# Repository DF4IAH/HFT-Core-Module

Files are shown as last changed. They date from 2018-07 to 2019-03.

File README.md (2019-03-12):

# HFT-Core-Module

## V1.1 PCB after placement was done:
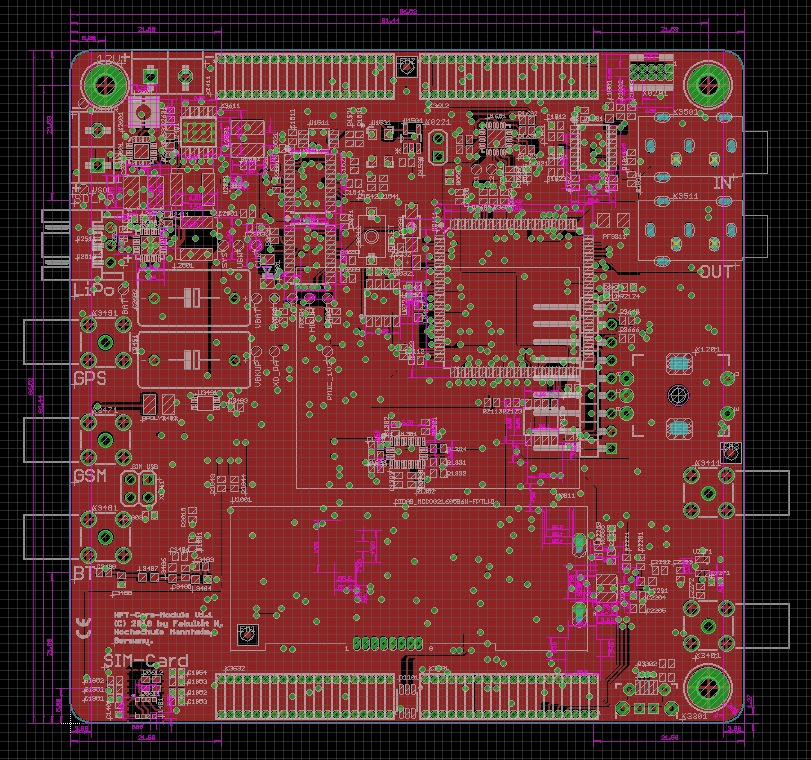
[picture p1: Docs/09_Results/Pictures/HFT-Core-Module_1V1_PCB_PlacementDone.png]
Screenshot of V1.1


## These are the included devices for the V1.1:
* __CPU: ST Microelectronics STM32L496ZGT6P__ (80MHz ARM Cortex-M4 w/ 1MB FLASH / 320kB RAM)
* __ext. Flash and EEPROM__ (8MB more data to be kept outside of the MCU / 8kB configuration data)
* __GSM / GNSS / BT: SIM868__ (SMS / GPRS / GPS, Glonass ...)
* __VHF/UHF FSK and LoRa: SX1262__ (VHF TX/RX)
* __VHF/UHF All but Lora: AX5243__ (VHF TX/RX)
* __Accel/Gyro/Mag: BNO085__ (3Axis-Acceleration, 3Axis-Gyro, 3Axis-Magneto - motion tracking engine)
* __Baro/Hygro/Temp/AirQuality: BME680__ (0.12Pa equiv. 1.7cm)
* __VCTCXO: CFPT-141_20MHz__ (being synchronized to the GPS 1PPS signal by pulling the VC)
* __Clock PLL__ (distributing any clocks that are needed)
* __Audio ADC and DAC__ (connected to the I2S facilities)
* __LCD 16x2 display__ (draws less than 1mA from the battery)
* __E-Ink-Display w/ 200x200px__ (more fun with even less energy)
* __Archer Headers__ (expanded by up to two daughter boards)
* __SMA sockets: GSM, GNSS, BlueTooth, SX1262, AX5243__ (each device has its own antenna socket)
* __PMICs for 12V, USB, Solar-Cells, 3.3V, 1.2V__ (high efficiency on board)
* __Electronic Switches: Subcircuits to be powered on/off by request__ (ultra-low-power to full-media)
* __LiPo-Connector: 1-cell 3.7V__ (high power request by the SIM868 device to be satisfied)
* __... and some more fun...__ (what is missing?  ;-)

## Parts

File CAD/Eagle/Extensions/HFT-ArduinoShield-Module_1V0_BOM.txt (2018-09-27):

Stückliste exportiert aus /Users/espero/nfs_ds_nfs/git/HFT-Core-Module__HW_1V1/CAD/Eagle/Extensions/HFT-ArduinoShield-Module_1V0.sch am 27.09.18 20:26

Qty Value                                   Device                                  Package                                 Parts                  Description                                
1                                           2X08_2MM56_SOCKET                       2X08                                    X108                   Header 2X08 2.54mm                         
1                                           2X10_2MM56_SOCKET                       2X10                                    X107                   Header 2X10 2.54mm                         
1                                           2X15_2MM56_SOCKET                       2X15                                    X105                   Header 2X15 2.54mm                         
2                                           2X17_2MM56_SOCKET                       2X17                                    X110, X190             Header 2X17 2.54mm                         
1                                           2X20_2MM56_SOCKET                       2X20                                    X201                   Header 2X20 2.54mm                         
2   100nF                                   C-EUC0603                               C0603                                   C108, C118             CAPACITOR, European symbol                 
1   120R                                    R-EU_R0603                              R0603                                   R201                   RESISTOR, European symbol                  
2   2X20/90_1MM27_HARWIN_M50-3902042_HEADER 2X20/90_1MM27_HARWIN_M50-3902042_HEADER 2X20/90_1MM27_HARWIN_M50-3902042_HEADER X301, X302             Header 20X2 1.27mm M50-3902042 Archer, 90° 
2   47R                                     R-EU_R0603                              R0603                                   R107, R110             RESISTOR, European symbol                  
4   MOUNT-PAD-ROUND2.8                      MOUNT-PAD-ROUND2.8                      2,8-PAD                                 H401, H402, H403, H404 MOUNTING PAD, round

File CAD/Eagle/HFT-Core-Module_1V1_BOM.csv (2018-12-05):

Qty | Value | Device | Package | Parts | Description
1 |  | HEADER-1X2 | 1X02 | X0222 | Header 1X2 2.54mm
1 |  | HEADER-2X2 | 2X02 | X1961 | Header 2X2 2.54mm
1 |  | HEADER-2X5_1MM27CORTEX_10PIN_JTAG-SWD | 2X05_SHROUDED_1MM27 | X0201 | Header 2X5 1.27mm 0.05";"; 6" | SJ | SJ | SJ0121, SJ0401, SJ0421, SJ0422, SJ0423, SJ0424 | SMD solder JUMPER
1 | 0.47uF | C-EUC0402 | C0402 | C2411 | CAPACITOR, European symbol
1 | 0.5pF | C-EUC0402 | C0402 | C3383 | CAPACITOR, European symbol
1 | 0R | L-EUL0603 | L0603 | L2261 | INDUCTOR, European symbol
12 | 0R | R-EU_R0402 | R0402 | R0441, R0891, R0892, R1811, R1812, R2521, R2651, R2681, R3512, R3513, R3577, R3578 | RESISTOR, European symbol
3 | 0R | R-EU_R0603 | R0603 | R3371, R3381, R3391 | RESISTOR, European symbol
8 | 0pF | C-EUC0402 | C0402 | C2265, C2293, C3371, C3372, C3381, C3382, C3391, C3392 | CAPACITOR, European symbol
2 | 1.0kR | R-EU_R0402 | R0402 | R0611, R0612 | RESISTOR, European symbol
1 | 1.1A/2.2A | R-EU_M1206 | M1206 | PF3211 | RESISTOR, European symbol
1 | 1.2nH | L-EUL0603 | L0603 | L3384 | INDUCTOR, European symbol
2 | 1.2pF | C-EUC0402 | C0402 | C3385, C3389 | CAPACITOR, European symbol
4 | 1.5kR | R-EU_R0402 | R0402 | R1051, R1111, R1121, R1131 | RESISTOR, European symbol
1 | 1.5pF | C-EUC0402 | C0402 | C3388 | CAPACITOR, European symbol
2 | 1.82MR | R-EU_R0402 | R0402 | R2621, R2633 | RESISTOR, European symbol
2 | 1.8pF | C-EUC0402 | C0402 | C2291, C3386 | CAPACITOR, European symbol
1 | 10.0MR | R-EU_R0402 | R0402 | R2622 | RESISTOR, European symbol
4 | 100R | R-EU_R0402 | R0402 | R1712, R1722, R2801, R2802 | RESISTOR, European symbol
8 | 100kR | R-EU_R0402 | R0402 | R0521, R0621, R1521, R2331, R2332, R2612, R2701, R2711 | RESISTOR, European symbol
62 | 100nF | C-EUC0402 | C0402 | C0213, C0401, C0402, C0403, C0404, C0405, C0406, C0407, C0408, C0409, C0421, C0422, C0441, C0521, C0621, C0901, C1001, C1101, C1301, C1302, C1303, C1401, C1501, C1511, C1512, C1531, C1541, C1543, C1602, C1603, C1605, C1702, C1703, C1705, C1902, C2001, C2101, C2202, C2271, C2301, C2302, C2303, C2412, C2541, C2602, C2702, C2751, C2801, C2802, C2803, C2901, C2902, C2903, C3001, C3002, C3003, C3101, C3102, C3103, C3104, C3105, C3393 | CAPACITOR, European symbol
2 | 100nH | L-EUL0603 | L0603 | L2312, L2313 | INDUCTOR, European symbol
1 | 100pF | C-EUC0402 | C0402 | C1532 | CAPACITOR, European symbol
5 | 10kR | R-EU_R0402 | R0402 | R1531, R1711, R1721, R1901, R1942 | RESISTOR, European symbol
10 | 10nF | C-EUC0402 | C0402 | C0412, C1615, C1616, C1712, C1722, C1903, C2404, C2603, C2605, C2653 | CAPACITOR, European symbol
16 | 10uF | C-EUC0402 | C0402 | C1701, C1704, C1711, C1721, C1904, C2201, C2401, C2402, C2403, C2501, C2504, C2505, C2511, C2601, C2652, C2701 | CAPACITOR, European symbol
2 | 10uH | L-EU4.90X4.90MM | L_4.90MM_X_4.90MM | L2651, L2791 | INDUCTOR, European symbol
3 | 10uH | L-EUL0603 | L0603 | L0411, L1701, L1801 | INDUCTOR, European symbol
1 | 150kR | R-EU_R0402 | R0402 | R2712 | RESISTOR, European symbol
1 | 15nH | L-EUL0603 | L0603 | L2291 | INDUCTOR, European symbol
1 | 15uH | L-EU3.00X3.00MM | L_3.00MM_X_3.00MM | L2201 | INDUCTOR, European symbol
1 | 18pF | C-EUC0402 | C0402 | C0311 | CAPACITOR, European symbol
2 | 1F_6V_SCMR18H105MRBB0 | CPOL-EUC115-080X160_POL | C115-080X160_POL | C0451, C2682 | POLARIZED CAPACITOR, European symbol
4 | 1MR | R-EU_ARRAY-8X | EXBD | R0581, R0591, R0681, R0691 | Resistor-Array 8x
3 | 1MR | R-EU_R0402 | R0402 | R1542, R2803, R2804 | RESISTOR, European symbol
1 | 1kR | R-EU_R0402 | R0402 | R2611 | RESISTOR, European symbol
6 | 1nF | C-EUC0402 | C0402 | C1201, C1202, C1203, C1542, C2272, C3203 | CAPACITOR, European symbol
10 | 1uF | C-EUC0402 | C0402 | C0413, C0442, C1011, C1012, C1522, C1811, C1812, C1961, C2502, C2521 | CAPACITOR, European symbol
4 | 2.0kR | R-EU_R0402 | R0402 | R1052, R1112, R1122, R1132 | RESISTOR, European symbol
1 | 2.27kR | R-EU_R0402 | R0402 | R2511 | RESISTOR, European symbol
1 | 2.2pF | C-EUC0402 | C0402 | C2267 | CAPACITOR, European symbol
2 | 2.2uF | C-EUC0402 | C0402 | C1706, C1803 | CAPACITOR, European symbol
2 | 2.2uH | L-EU6.00X6.00MM | L_6.00MM_X_6.00MM | L2411, L2501 | INDUCTOR, European symbol
1 | 2.4pF | C-EUC0402 | C0402 | C2292 | CAPACITOR, European symbol
1 | 2.5nH | L-EUL0603 | L0603 | L2263 | INDUCTOR, European symbol
2 | 2.7nF | C-EUC0402 | C0402 | C1831, C1841 | CAPACITOR, European symbol
1 | 2.7nH | L-EUL0603 | L0603 | L3387 | INDUCTOR, European symbol
3 | 220kR | R-EU_R0402 | R0402 | R0231, R0232, R1031 | RESISTOR, European symbol
7 | 220nF | C-EUC0402 | C0402 | C0711, C0721, C0801, C1601, C1604, C1951, C1955 | CAPACITOR, European symbol
2 | 22R | R-EU_R0402 | R0402 | R1961, R1962 | RESISTOR, European symbol
4 | 22nH | L-EUL0603 | L0603 | L2311, L2316, L2317, L2321 | INDUCTOR, European symbol
5 | 22pF | C-EUC0402 | C0402 | C1321, C1322, C1952, C1953, C1954 | CAPACITOR, European symbol
4 | 22uF | C-EUC0402 | C0402 | C2421, C2422, C2423, C2703 | CAPACITOR, European symbol
1 | 22uH | L-EUWE-TPCWE_TPC_3MM8 | WE-TPC_3MM8-3MM8_R-1MM3 | L2601 | INDUCTOR, European symbol
1 | 240R | R-EU_R0402 | R0402 | R2501 | RESISTOR, European symbol
1 | 27R | R-EU_R0402 | R0402 | R1053 | RESISTOR, European symbol
3 | 27R | R-EU_R0805 | R0805 | R1113, R1123, R1133 | RESISTOR, European symbol
4 | 2X20/90_1MM27_HARWIN_M50-3202045_SOCKET | 2X20/90_1MM27_HARWIN_M50-3202045_SOCKET | 2X20/90_1MM27_HARWIN_M50-3202045_SOCKET | X3511, X3512, X3531, X3532 | Socket 20X2 1.27mm M50-3202045 Archer, 90°
2 | 2kR | R-EU_R0402 | R0402 | R1331, R1332 | RESISTOR, European symbol
3 | 3.3pF | C-EUC0402 | C0402 | C2263, C2282, C2283 | CAPACITOR, European symbol
1 | 3.3uF | C-EUC0402 | C0402 | C2405 | CAPACITOR, European symbol
1 | 3.65MR | R-EU_R0402 | R0402 | R2631 | RESISTOR, European symbol
1 | 330kR | R-EU_R0402 | R0402 | R3202 | RESISTOR, European symbol
3 | 33kR | R-EU_R0402 | R0402 | R0221, R1543, R2541 | RESISTOR, European symbol
2 | 39pF | C-EUC0402 | C0402 | C2264, C2281 | CAPACITOR, European symbol
1 | 3R | R-EU_R0402 | R0402 | R2411 | RESISTOR, European symbol
2 | 4.3pF | C-EUC0402 | C0402 | C2314, C2315 | CAPACITOR, European symbol
1 | 4.75MR | R-EU_R0402 | R0402 | R2641 | RESISTOR, European symbol
2 | 4.7kR | R-EU_R0402 | R0402 | R1943, R1944 | RESISTOR, European symbol
3 | 4.7nH | L-EUL0603 | L0603 | L2264, L3386, L3388 | INDUCTOR, European symbol
5 | 4.7pF | C-EUC0402 | C0402 | C2317, C2318, C2321, C2322, C2323 | CAPACITOR, European symbol
5 | 4.7uF | C-EUC0402 | C0402 | C0410, C0423, C1801, C1802, C2606 | CAPACITOR, European symbol
2 | 43nH | L-EUL0603 | L0603 | L2314, L2315 | INDUCTOR, European symbol
1 | 470nF | C-EUC0402 | C0402 | C2203 | CAPACITOR, European symbol
110 | 47R | R-EU_R0402 | R0402 | R0531, R0631, R0901, R0902, R0903, R0904, R1301, R1302, R1303, R1304, R1538, R1539, R1541, R1623, R1631, R1632, R1643, R1644, R1651, R1751, R1752, R1753, R1761, R1821, R1822, R1823, R1824, R1951, R1952, R1953, R2010, R2011, R2012, R2013, R2014, R2015, R2016, R2017, R2020, R2021, R2022, R2023, R2024, R2025, R2026, R2027, R2110, R2111, R2112, R2113, R2120, R2121, R2122, R2123, R2211, R2221, R2222, R2223, R2224, R2251, R2252, R2253, R2321, R2341, R2351, R2391, R2554, R2811, R3501, R3502, R3503, R3504, R3505, R3506, R3507, R3508, R3509, R3510, R3511, R3514, R3515, R3516, R3517, R3518, R3519, R3520, R3521, R3522, R3523, R3566, R3567, R3568, R3569, R3570, R3571, R3572, R3573, R3574, R3575, R3576, R3579, R3580, R3581, R3582, R3583, R3584, R3585, R3586, R3587, R3588 | RESISTOR, European symbol
2 | 47nF | C-EUC0402 | C0402 | C2205, C2503 | CAPACITOR, European symbol
1 | 47nH | L-EUL0603 | L0603 | L2262 | INDUCTOR, European symbol
2 | 47pF | C-EUC0402 | C0402 | C1901, C2204 | CAPACITOR, European symbol
1 | 5.6pF | C-EUC0402 | C0402 | C2266 | CAPACITOR, European symbol
1 | 50mA/150mA | R-EU_R1210 | R1210 | RPOLY3393 | RESISTOR, European symbol
2 | 560R | R-EU_R0402 | R0402 | R1831, R1841 | RESISTOR, European symbol
1 | 6.86kR | R-EU_R0402 | R0402 | R2512 | RESISTOR, European symbol
1 | 6.8pF | C-EUC0402 | C0402 | C2791 | CAPACITOR, European symbol
1 | 7.50MR | R-EU_R0402 | R0402 | R2632 | RESISTOR, European symbol
2 | 74LVC4245A | 74LVC4245A | TSSOP24_SOT355-1 | U2001, U2101 | Octal dual supply translating transceiver; 3-state
1 | 8.20MR | R-EU_R0402 | R0402 | R2642 | RESISTOR, European symbol
1 | 8.2pF | C-EUC0402 | C0402 | C0332 | CAPACITOR, European symbol
1 | 9.1nH | L-EUL0603 | L0603 | L2282 | INDUCTOR, European symbol
1 | ABM3B-16.0000MHZ | ABM3B-16.0000MHZ | ABM3B | Q2311 | ABM3B Ceramic SMD Crystal
1 | ABM3B-32.0000MHZ | ABM3B-32.0000MHZ | ABM3B | Q2211 | ABM3B Ceramic SMD Crystal
2 | ABS07-32.768KHZ | ABS07-32.768KHZ | ABS07 | Q0321, Q1321 | ABRACON ABS07
1 | ASMT-YTB7-0AA02_RGB | ASMT-YTB7-0AA02_RGB | ASMT-YTB7_0AA02_RGB | D1101 | Broadcom ASMT-YTB7-0AA02
1 | AX5243 | AX5243 | QFN20-4X4-0P5-PAD | U2301 | AX5243
1 | BME680 | BME680 | BME680 | U1401 | BME680 Climate Sensor
1 | BNO085 | BNO085 | BNO085_LGA28 | U1301 | hillcrestlabs BNO085
1 | BQ24193 | BQ24193 | VQFN-24 | U2501 | TI BQ24193
1 | BQ25570 | BQ25570 | V-PVQFN-20 | U2601 | TI BQ25570
1 | CAT24C64 | CAT24C64 | SOIC8_150MIL | U0801 | CAT24C64
1 | CFPT-141-20MHZ | CFPT-141-20MHZ | CFPT-141 | U1531 | VCTCXO, 3.0V
1 | CMAD6001 | D_SOD923 | SOD923 | D1901 | DIODE with SOD923 footprint
4 | CRS08 | CRS08 | SOD80C | D2521, D2681, D2801, D2802 | SCHOTTKY BARRIER RECTIFIER
2 | CUI SJ1-3535NS | SJ1-353XNS_3MM5-STEREO-AUDIO-JACKS | SJ1-353XNS_3MM5-STEREO-AUDIO-JACKS | X3401, X3411 | SJ1-353XNS_3MM5-STEREO-AUDIO-JACKS
7 | D.C. | R-EU_R0402 | R0402 | R1731, R1741, R1742, R1743, R1744, R1745, R1746 | RESISTOR, European symbol
2 | IS25LP032D | IS25LP032D | SOIC8_150MIL | U0711, U0721 | ISSI IS25LP032D
1 | JR200 | C-TRIMM3MM2_2MM5 | 3MM2_X_2MM5 | C0331 | Trimm capacitor
1 | JST_S3B-XH-A | JST_S3B-XH-A | JST_S3B-XH-A | X2551 | JST S3B-XH-A shrouded header
1 | KSR223GLFG | KSR223G_SMD_1POL | KSR223G_SMD_1POL | S0212 | KSR223G
1 | LM4120IM5-3.0 | LM4120IM5-3.0 | SOT95P285X120-5N | U1501 | Precision Micropower Low Dropout Voltage Reference
1 | LM53603-Q1 | LM53603-Q1 | HTSSOP16 | U2401 | TI LM53603-Q1
2 | LPV811 | LPV811 | SOT-23-5 | U1542, U2541 | CMOS OPERATIONAL AMPLIFIERS
1 | MAX5217 | MAX5217 | µMAX8 | U1511 | Maxim Integrated MAX5217 DAC
1 | MCP4661-104E-MS | MCP4661-104E-MS | TSSOP14 | U2751 | Microchip MCP4661
1 | MICROSIM-8P_SDCARD-8P_MOLEX-104642-1610 | MICROSIM-8P_SDCARD-8P_MOLEX-104642-1610 | MICROSIM-8P_SDCARD-8P_MOLEX-104642-1610 | X1951 | Mikro-SIM and Mikro-SD-Cardholder
1 | MIDAS_MCCOG21605B6W-FPTLWI | MIDAS_MCCOG21605B6W-FPTLWI | MIDAS_MCCOG21605B6W-FPTLWI | U1001 | MIDAS MCCOG21605B6W-FPTLWI
4 | MMBT2222 | BC846 | SOT23 | T1051, T1111, T1121, T1131 | NPN TRANSISTOR
1 | MMSZ4690-E3-08 (5.6V) | ZENER-DIODESOD123 | SOD123 | D1902 | Z-Diode
1 | MOLEX 105017-0001 | USB_MICRO-B_MOLEX | USB-B-MICRO-SMD_MOLEX-105017-0001 | X3201 | USB Type Micro-B Connector
3 | MOUNT-PAD-ROUND2.8 | MOUNT-PAD-ROUND2.8 | 2,8-PAD | H3611, H3621, H3631 | MOUNTING PAD, round
3 | N/A | C-EUC0402 | C0402 | C2312, C2313, C2316 | CAPACITOR, European symbol
13 | N/A | R-EU_R0402 | R0402 | R1611, R1612, R1635, R1636, R1661, R2114, R2115, R2116, R2117, R2124, R2125, R2126, R2127 | RESISTOR, European symbol
1 | NTC 10kR | R-EU_R0402 | R0402 | R1941 | RESISTOR, European symbol
1 | OPA354 | OPA354 | SOT-23-5 | U1541 | CMOS OPERATIONAL AMPLIFIERS
2 | PCAL6416APW | PCAL6416APW | TSSOP24_SOT355-1 | U0521, U0621 | NXP PCAL6416A
1 | PCM1863 | PCM1863 | R-PDSO-G30 | U1701 | Texas Instruments PCM1863
1 | PE4259 | PE4259 | SC-70_6-LEAD_2X1MM25_0P65 | U2271 | pSemi PE4259
16 | PTR1B1,27 | PTR1B1,27 | B1,27 | TP_+1V1, TP_+1V2_MCU, TP_+3V3_HICUR, TP_+3V3_XO, TP_+3V3_XO_PA, TP_BQ_VBAT, TP_BQ_VOUT, TP_BQ_VSTOR, TP_IN_CLK1, TP_IN_CLK2, TP_LIPO_BAT, TP_LIPO_CUR, TP_LIPO_SYS, TP_VBAT, TP_VSOL, TP_VUSB_SW | TEST PIN
7 | PTR1TP06R | PTR1TP06R | TP06R | TP_AX_ADC1, TP_AX_ADC2, TP_AX_IRQ, TP_AX_TCXO_EN, TP_SX_DIO1, TP_SX_DIO2, TP_SX_DIO3 | TEST PIN
1 | SAMTEC SMA-J-P-H-RA-TH1 | SMA_SMT_AMPHENOL-901-143 | SMA_SMT_AMPHENOL_901-143 | X3311 | RF/COAXIAL, SMA JACK, R/A, 50OHM, THD
1 | SIM868 | SIM868 | SIM868 | U1901 | SIMCom SIM868
1 | SMA_SMT_AMPHENOL-901-143 | SMA_SMT_AMPHENOL-901-143 | SMA_SMT_AMPHENOL_901-143 | X3301 | RF/COAXIAL, SMA JACK, R/A, 50OHM, THD
3 | SMA_SMT_AMPHENOL-901-143, SAMTEC SMA-J-P-H-RA-TH1 | SMA_SMT_AMPHENOL-901-143 | SMA_SMT_AMPHENOL_901-143 | X3371, X3381, X3391 | RF/COAXIAL, SMA JACK, R/A, 50OHM, THD
1 | STM32L4Z_144PIN_SMPS | STM32L4Z_144PIN_SMPS | LQFP144 | U0111 | STM32L4XX LQFP packages with actual and functional symbols.
1 | SX1262 | SX1262 | QFN24-4X4-0P5-PAD | U2201 | Semtech SX1261/2
1 | Si5338 | SI5338 | QFN24_P0MM5_CTRPAD | U1601 | SI5338
1 | TDK B4310 | TDK_B4310 | QCS5P | U3392 | TDK B4310 SAW-filter for GNSS
1 | TPS62051 | TPS62051 | S-PDSO-G10 | U2701 | TPS62051 800-mA Synchronous Step-Down Converter: 3.3V
7 | TS5A23166 | TS5A23166 | R-PDSO-G8 | U1651, U2681, U2801, U2901, U3001, U3101, U3391 | TS5A23166
1 | TTE_EN11-HSM | TTE_EN11-HSM | TTE_EN11-HSM | X1201 | TT-Electronics EN1-HSM Rotary Encoder with Switch
1 | WE-CBF_300R | L-EUL3216C | L3216C | L3393 | INDUCTOR, European symbol
2 | WIRE-TO-BOARD_5MM08_1X02 | WIRE-TO-BOARD_5MM08_1X02 | WIRE-TO-BOARD_5MM08_1X02 | X2411, X2601 | Wire-to-Board connector 5.08mm 1x02
1 | WM8523 | WM8523 | TSSOP20 | U1801 | WM8523
1 | ZIO_EINK_1IN54 | ZIO_EINK_1IN54 | ZIO_EINK_1IN54 | U0911 | ZIO E-Ink Display 1.54in. V1.0

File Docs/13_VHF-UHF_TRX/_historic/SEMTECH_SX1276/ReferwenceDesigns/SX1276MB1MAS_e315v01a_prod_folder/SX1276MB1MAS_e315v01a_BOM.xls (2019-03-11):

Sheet: SX1276MB1MAS - BOM
 |  |  | SX1276MB1MAS - BOM |  |  | BOM # V1a
 |  |  |  |  |  | SCH # e315V01a
 |  |  | 2015-11-09 | EMr | Version e315V01a - 868MHz on RF_HF and 433MHz on RF_LF | PCB # e315V01a
RefDes | MPN | Geom | Value | Qty | Description | Manufacturer
IC
U1 | SX1276IMLTRT | TQFN-28 6x6mm | SX1276 | 1 | 137MHz to 1020MHz Low Power Long Range Transceiver | Semtech
U2 | PE4259 | SC-70 | - | 1 | PE4259 - 10MHz to 3GHz SPDT RF Switch | Peregrine Semi
U3 | NC7SZ04P5X | SC-70-5 | - | 1 | NC7SZ04 TinyLogic UHS Inverter | Fairchild Semi
U4 | CRCW06030000Z0EA | 0603 | 0R | 1 | Thick Film Resistor ±5%, 1/10W (No SAW filter populated) | Vishay/Dale
U5 | PE4259 | SC-70 | - | 1 | PE4259 - 10MHz to 3GHz SPDT RF Switch | Peregrine Semi
U6 | CRCW06030000Z0EA | 0603 | 0R | 1 | Thick Film Resistor ±5%, 1/10W (No SAW filter populated) | Vishay/Dale
Resistors
R1 | CRCW04020000Z0ED | 0402 | 0R | 1 | Thick Film Resistor ±5%, 1/16W | Vishay/Dale
R2 | CRCW04020000Z0ED | 0402 | 0R | 1 | Thick Film Resistor ±5%, 1/16W | Vishay/Dale
R3 | CRCW06030000Z0EA | 0603 | 0R | 1 | Thick Film Resistor ±5%, 1/10W | Vishay/Dale
R4 | EXB-N8V101JX | EXB28V | 100R | 1 | SMD Resistor Array Resistors (4x), ±5%, 31mW | Panasonic - ECG
R5 | EXB-N8V101JX | EXB28V | 100R | 1 | SMD Resistor Array Resistors (4x), ±5%, 31mW | Panasonic - ECG
R6 | CRCW06030000Z0EA | 0603 | 0R | 1 | Thick Film Resistor ±5%, 1/10W | Vishay/Dale
R7 | CRCW04020000Z0ED | 0402 | 0R | 1 | Thick Film Resistor ±5%, 1/16W | Vishay/Dale
R11 | CRCW04021K00JNED | 0402 | 1k | 1 | Thick Film Resistor ±5%, 1/16W | Vishay/Dale
R13 | EXB-N8V101JX | EXB28V | 100R | 1 | SMD Resistor Array Resistors (4x), ±5%, 31mW | Panasonic - ECG
R14 | CRCW0402100RJNED | 0402 | 100R | 1 | Thick Film Resistor ±5%, 1/16W | Vishay/Dale
R16 | CRCW0402100RJNED | 0402 | 100R | 1 | Thick Film Resistor ±5%, 1/16W | Vishay/Dale
Capacitors
C1 | GRM1555C1H150JA01D | 0402 | 15pF | 1 | Multilayer ceramic capacitors C0G ±5%, 50V for Rakon Crystal (18pF for NDK) | Murata
C2 | GRM1555C1H150JA01D | 0402 | 15pF | 1 | Multilayer ceramic capacitors C0G ±5%, 50V for Rakon Crystal (18pF for NDK) | Murata
C3 | GRM155R71C104KA88D | 0402 | 100nF | 1 | Multilayer ceramic capacitors X7R ±10%, 16V | Murata
C4 | GRM155R71C104KA88D | 0402 | 100nF | 1 | Multilayer ceramic capacitors X7R ±10%, 16V | Murata
C5 | GRM155R71C104KA88D | 0402 | 100nF | 1 | Multilayer ceramic capacitors X7R ±10%, 16V | Murata
C6 | GRM155R71C104KA88D | 0402 | 100nF | 1 | Multilayer ceramic capacitors X7R ±10%, 16V | Murata
C7 | GRM1555C1H470JZ01D | 0402 | 47pF | 1 | Multilayer ceramic capacitors C0G ±5%, 50V | Murata
C8 | GRM1555C1H470JZ01D | 0402 | 47pF | 1 | Multilayer ceramic capacitors C0G ±5%, 50V | Murata
C9 | GRM1555C1H330JZ01D | 0402 | 33pF | 1 | Multilayer ceramic capacitors C0G ±0.25pF, 50V | Murata
C10 | GRM1555C1H1R5CZ01D | 0402 | 1.5pF | 1 | Multilayer ceramic capacitors C0G ±0.25pF, 50V | Murata
C11 | GRM1555C1H4R7CZ01D | 0402 | 4.7pF | 1 | Multilayer ceramic capacitors C0G ±0.25pF, 50V | Murata
C12 | GRM1555C1H1R2CZ01D | 0402 | 1.2pF | 1 | Multilayer ceramic capacitors C0G ±0.25pF, 50V | Murata
C13 | GRM1555C1H1R8CZ01D | 0402 | 1.8pF | 1 | Multilayer ceramic capacitors C0G ±0.25pF, 50V | Murata
C17 | GRM1555C1H3R3CZ01D | 0402 | 3.3pF | 1 | Multilayer ceramic capacitors C0G ±0.25pF, 50V | Murata
C18 | GRM1555C1H470JZ01D | 0402 | 47pF | 1 | Multilayer ceramic capacitors C0G ±5%, 50V | Murata
C19 | GRM1555C1H470JZ01D | 0402 | 47pF | 1 | Multilayer ceramic capacitors C0G ±5%, 50V | Murata
C20 | GRM1555C1H470JZ01D | 0402 | 47pF | 1 | Multilayer ceramic capacitors C0G ±5%, 50V | Murata
C21 | GRM155R71C104KA88D | 0402 | 100nF | 1 | Multilayer ceramic capacitors X7R ±10%, 16V | Murata
C22 | GRM155R71H102JA01D | 0402 | 1nF | 1 | Multilayer ceramic capacitors X7R ±5%, 50V | Murata
C23 | GRM21BR60J226ME39L | 0805 | 22uF | 1 | Multilayer ceramic capacitors X5R ±20%, 6.3V | Murata
C24 | GRM188R61A105KA61D | 0603 | 1uF | 1 | Multilayer ceramic capacitors X5R ±10%, 10V | Murata
C25 | GRM155R71H102JA01D | 0402 | 1nF | 1 | Multilayer ceramic capacitors X7R ±5%, 50V | Murata
C26 | GRM1555C1H470JZ01D | 0402 | 47pF | 1 | Multilayer ceramic capacitors C0G ±5%, 50V | Murata
C27 | GRM155R71C104KA88D | 0402 | 100nF | 1 | Multilayer ceramic capacitors X7R ±10%, 16V | Murata
C28 | LQG15HS15NJ02D | 0402 | 15nH | 1 | Multilayer Inductor ±5% | Murata
C29 | GRM1555C1H4R7CA01D | 0402 | 4.7pF | 1 | Multilayer ceramic capacitors C0G ±0.25pF, 50V | Murata
C30 | GRM1555C1H6R8CA01D | 0402 | 6.8pF | 1 | Multilayer ceramic capacitors C0G ±0.25pF, 50V | Murata
C31 | GRM1555C1H2R7CZ01D | 0402 | 2.7pF | 1 | Multilayer ceramic capacitors C0G ±0.25pF, 50V | Murata
C32 | GRM1555C1H6R8CA01D | 0402 | 6.8pF | 1 | Multilayer ceramic capacitors C0G ±0.25pF, 50V | Murata
C35 | GRM155R71E103KA01D | 0402 | 10nF | 1 | Multilayer ceramic capacitors X7R ±10%, 25V | Murata
C36 | GRM1555C1H470JZ01D | 0402 | 47pF | 1 | Multilayer ceramic capacitors C0G ±5%, 50V | Murata
C38 | GRM1555C1H470JZ01D | 0402 | 47pF | 1 | Multilayer ceramic capacitors C0G ±5%, 50V | Murata
C39 | GRM1555C1H470JZ01D | 0402 | 47pF | 1 | Multilayer ceramic capacitors C0G ±5%, 50V | Murata
C43 | GRM155R71H102JA01D | 0402 | 1nF | 1 | Multilayer ceramic capacitors X7R ±5%, 50V | Murata
C44 | GRM188R61A105KA61D | 0603 | 1uF | 1 | Multilayer ceramic capacitors X5R ±10%, 10V | Murata
C45 | GRM155R71H102JA01D | 0402 | 1nF | 1 | Multilayer ceramic capacitors X7R ±5%, 50V | Murata
C50 | GRM188R61A105KA61D | 0603 | 1uF | 1 | Multilayer ceramic capacitors X5R ±10%, 10V | Murata
Inductors & Ferrites
L1 | LQG15HS82NJ02D | 0402 | 82nH | 1 | Multilayer Inductor ±5% | Murata
L2 | LQW15AN33NJ00D | 0402 | 33nH | 1 | Wirewound Inductor ±5% | Murata
L4 | LQG15HS10NJ02D | 0402 | 10nH | 1 | Multilayer Inductor ±5% | Murata
L5 | LQG15HS6N2S02D | 0402 | 6.2nH | 1 | Multilayer Inductor ±0.3nH | Murata
L7 | LQG15HS10NJ02D | 0402 | 10nH | 1 | Multilayer Inductor ±5% | Murata
L8 | CRCW04020000Z0ED | 0402 | 0R | 1 | Thick Film Resistor ±5%, 1/16W | Vishay/Dale
L9 | LQG15HS12NJ02D | 0402 | 12nH | 1 | Multilayer Inductor ±5% | Murata
L10 | CRCW04020000Z0ED | 0402 | 0R | 1 | Thick Film Resistor ±5%, 1/16W | Vishay/Dale
L11 | CRCW04020000Z0ED | 0402 | 0R | 1 | Thick Film Resistor ±5%, 1/16W | Vishay/Dale
L12 | GRM1555C1H4R7CZ01D | 0402 | 4.7pF | 1 | Multilayer ceramic capacitors C0G ±0.25pF, 50V | Murata
L13 | LQG15HS18NJ02D | 0402 | 18nH | 1 | Multilayer Inductor ±5% | Murata
L14 | CRCW04020000Z0ED | 0402 | 0R | 1 | Thick Film Resistor ±5%, 1/16W | Vishay/Dale
Crystal (or other referenced vendors)
Q1 | FTR5092-A2 | QESM07 3.2x2.5mm | 32.000MHz | 1 | Crystal unit Rakon; Tol. ±10ppm, Cload=10pF, G-Senstivity=2ppb/G max (populated) | Rakon
or | FTR5123-A0 | QESM09 2.0x1.6mm | 32.000MHz | - | Crystal unit Rakon; Tol. ±10ppm, Cload=10pF, G-Senstivity=2ppb/G max (recommended for new design) | Rakon
Q1 | EXS00A-CS00131 | NX2520SA 2.5x2.0mm | 32.000MHz | - | Crystal unit NDK; Tol. ±10ppm, Cload=10pF, G-Senstivity=2ppb/G max | NDK
or | EXS00A-CS06465 | NX2016SA 2.0x1.6mm | 32.000MHz | - | Crystal unit NDK; Tol. ±10ppm, Cload=10pF, G-Senstivity=2ppb/G max (recommended for new design) | NDK
Q1 | S0197-X-002-3 | QESM07 3.2x2.5mm | 32.000MHz | - | Crystal unit Taitien; Tol. ±10ppm, Cload=10pF, G-Senstivity=2ppb/G max | Taitien
Connectors and others (or P/N equivalent)
ANT_HF | 142-0711-821 | SMA End Launch | 50 Ohms | 1 | SMA End launch jack receptacle for PCB mount | Emerson Network Power
ANT_LF | 142-0711-821 | SMA End Launch | 50 Ohms | 1 | SMA End launch jack receptacle for PCB mount | Emerson Network Power
J1 | 68000-108HLF | Header 1x8 | 8 pins | 1 | 8 Pins - Through hole single row male connector, Bottom side | FCI
J2 | 68000-110HLF | Header 1x10 | 10 pins | 1 | 10 Pins - Through hole single row male connector, Bottom side | FCI
J3 | 68000-108HLF | Header 1x8 | 8 pins | 1 | 8 Pins - Through hole single row male connector, Bottom side | FCI
J4 | 68000-106HLF | Header 1x6 | 6 pins | 1 | 6 Pins - Through hole single row male connector, Bottom side | FCI
Additional or optional components
- | BMIS-205-F | Shield | - | 0 | Standard Surface Mount Shield in two parts with BMIS-205-C cover | Laird Technologies
Remark: components not listed in the BOM are not populated on the module.

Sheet: Release
 |  | SX1276MB1MAS - BOM |  |  |  | BOM # V1a
 |  |  |  |  |  | SCH # e315V01a
 |  | 2015-11-09 | EMr | Version e315V01a |  | PCB # e315V01a
Release histroy
Version | Change notes |  |  |  | By
pcb_e315V01a | BOM for SX1276MB1MAS V1a |  |  |  | EMr
 | Modified BOM to have the correct ouput power +14dBm @433MHz |  |  |  | EMr
 | Modified value for references: L1, C28, C29, L8, C30, C32, L10 & C34=NC
 | Modified value for RxTX control on R11=1k; R16=100R |  |  |  | EMr
 | Added two new ref for 32.0MHz crystal |  |  |  | EMr

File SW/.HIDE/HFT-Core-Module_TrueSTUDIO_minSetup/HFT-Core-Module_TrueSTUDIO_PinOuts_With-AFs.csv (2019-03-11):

Position | Name | Type | Signal | Label | AF0 | AF1 | AF2 | AF3 | AF4 | AF5 | AF6 | AF7 | AF8 | AF9 | AF10 | AF11 | AF12 | AF13 | AF14 | AF15
1 | PE2 | I/O | GPIO_Analog |  | SYS_TRACECLK |  | TIM3_ETR |  |  |  |  |  |  | TSC_G7_IO1 |  | LCD_SEG38 | FMC_A23 | SAI1_MCLK_A |  | EVENTOUT
2 | PE3 | I/O | GPIO_Analog |  | SYS_TRACED0 |  | TIM3_CH1 |  |  |  |  |  |  | TSC_G7_IO2 |  | LCD_SEG39 | FMC_A19 | SAI1_SD_B |  | EVENTOUT
3 | PE4 | I/O | GPIO_Analog |  | SYS_TRACED1 |  | TIM3_CH2 |  |  |  | DFSDM1_DATIN3 |  |  | TSC_G7_IO3 | DCMI_D4 |  | FMC_A20 | SAI1_FS_A |  | EVENTOUT
4 | PE5 | I/O | GPIO_Analog |  | SYS_TRACED2 |  | TIM3_CH3 |  |  |  | DFSDM1_CKIN3 |  |  | TSC_G7_IO4 | DCMI_D6 |  | FMC_A21 | SAI1_SCK_A |  | EVENTOUT
5 | PE6 | I/O |  |  | SYS_TRACED3 |  | TIM3_CH4 |  |  |  |  |  |  |  | DCMI_D7 |  | FMC_A22 | SAI1_SD_A |  | EVENTOUT
6 | VBAT | Power
7 | PC13 | I/O | SYS_WKUP2 | MCU_IN_WAKEUP |  |  |  |  |  |  |  |  |  |  |  |  |  |  |  | EVENTOUT
8 | PC14-OSC32_IN (PC14) | I/O | RCC_OSC32_IN | MCU_OSC32_IN |  |  |  |  |  |  |  |  |  |  |  |  |  |  |  | EVENTOUT
9 | PC15-OSC32_OUT (PC15) | I/O | RCC_OSC32_OUT | MCU_OSC32_OUT |  |  |  |  |  |  |  |  |  |  |  |  |  |  |  | EVENTOUT
10 | PF0 | I/O | I2C2_SDA | MCU_I2C2_SDA |  |  |  |  | I2C2_SDA |  |  |  |  |  |  |  | FMC_A0 |  |  | EVENTOUT
11 | PF1 | I/O | I2C2_SCL | MCU_I2C2_SCL |  |  |  |  | I2C2_SCL |  |  |  |  |  |  |  | FMC_A1 |  |  | EVENTOUT
12 | PF2 | I/O | GPIO_Analog |  |  |  |  |  | I2C2_SMBA |  |  |  |  |  |  |  | FMC_A2 |  |  | EVENTOUT
13 | PF3 | I/O | ADC3_IN6 | ADC3_IN6_20MHZ_PULL |  |  |  |  |  |  |  |  |  |  |  |  | FMC_A3 |  |  | EVENTOUT
14 | PF4 | I/O |  |  |  |  |  |  |  |  |  |  |  |  |  |  | FMC_A4 |  |  | EVENTOUT
15 | PF5 | I/O |  |  |  |  |  |  |  |  |  |  |  |  |  |  | FMC_A5 |  |  | EVENTOUT
16 | VSS | Power
17 | VDD | Power
18 | PF6 | I/O | TIM5_CH1 | MCU_IN_TIMCAP_N |  | TIM5_ETR | TIM5_CH1 |  |  |  |  |  |  |  | QUADSPI_BK1_IO3 |  |  | SAI1_SD_B |  | EVENTOUT
19 | PF7 | I/O | TIM5_CH2 | MCU_IN_TIMCAP_W |  |  | TIM5_CH2 |  |  |  |  |  |  |  | QUADSPI_BK1_IO2 |  |  | SAI1_MCLK_B |  | EVENTOUT
20 | PF8 | I/O | TIM5_CH3 | MCU_IN_TIMCAP_S |  |  | TIM5_CH3 |  |  |  |  |  |  |  | QUADSPI_BK1_IO0 |  |  | SAI1_SCK_B |  | EVENTOUT
21 | PF9 | I/O | TIM5_CH4 | MCU_IN_TIMCAP_VSOL |  |  | TIM5_CH4 |  |  |  |  |  |  |  | QUADSPI_BK1_IO1 |  |  | SAI1_FS_B | TIM15_CH1 | EVENTOUT
22 | PF10 | I/O | GPIO_Analog |  |  |  |  | QUADSPI_CLK |  |  |  |  |  |  | DCMI_D11 |  |  |  | TIM15_CH2 | EVENTOUT
23 | PH0-OSC_IN (PH0) | I/O | RCC_OSC_IN | MCU_HSE |  |  |  |  |  |  |  |  |  |  |  |  |  |  |  | EVENTOUT
24 | PH1-OSC_OUT (PH1) | I/O |  |  |  |  |  |  |  |  |  |  |  |  |  |  |  |  |  | EVENTOUT
25 | NRST | Reset
26 | PC0 | I/O | GPIO_Analog |  |  | LPTIM1_IN1 | I2C4_SCL |  | I2C3_SCL |  | DFSDM1_DATIN4 |  | LPUART1_RX |  |  | LCD_SEG18 |  |  | LPTIM2_IN1 | EVENTOUT
27 | PC1 | I/O | GPIO_Analog |  | SYS_TRACED0 | LPTIM1_OUT | I2C4_SDA | SPI2_MOSI | I2C3_SDA |  | DFSDM1_CKIN4 |  | LPUART1_TX |  | QUADSPI_BK2_IO0 | LCD_SEG19 |  | SAI1_SD_A |  | EVENTOUT
28 | PC2 | I/O | GPIO_Analog |  |  | LPTIM1_IN2 |  |  |  | SPI2_MISO | DFSDM1_CKOUT |  |  |  | QUADSPI_BK2_IO1 | LCD_SEG20 |  |  |  | EVENTOUT
29 | PC3 | I/O | GPIO_Analog |  |  | LPTIM1_ETR |  |  |  | SPI2_MOSI |  |  |  |  | QUADSPI_BK2_IO2 | LCD_VLCD |  | SAI1_SD_A | LPTIM2_ETR | EVENTOUT
30 | VSSA | Power
31 | VREF- | Power
32 | VREF+ | MonoIO | VREFBUF_OUT | MCU_OUT_VREF+
33 | VDDA | Power
34 | PA0 | I/O | USART2_CTS | UART2_CTS_IN |  | TIM2_CH1 | TIM5_CH1 | TIM8_ETR |  |  |  | USART2_CTS | UART4_TX |  |  |  |  | SAI1_EXTCLK | TIM2_ETR | EVENTOUT
35 | PA1 | I/O |  |  |  | TIM2_CH2 | TIM5_CH2 |  | I2C1_SMBA | SPI1_SCK |  | USART2_DE/USART2_RTS | UART4_RX |  |  | LCD_SEG0 |  |  | TIM15_CH1N | EVENTOUT
36 | PA2 | I/O | USART2_TX | UART2_TX_OUT |  | TIM2_CH3 | TIM5_CH3 |  |  |  |  | USART2_TX | LPUART1_TX |  | QUADSPI_BK1_NCS | LCD_SEG1 |  | SAI2_EXTCLK | TIM15_CH1 | EVENTOUT
37 | PA3 | I/O | ADC2_IN8 ADC1_IN8 | MCU_VSOL_ADC1 |  | TIM2_CH4 | TIM5_CH4 |  |  |  |  | USART2_RX | LPUART1_RX |  | QUADSPI_CLK | LCD_SEG2 |  | SAI1_MCLK_A | TIM15_CH2 | EVENTOUT
38 | VSS | Power
39 | VDD | Power
40 | PA4 | I/O |  |  |  |  |  |  |  | SPI1_NSS | SPI3_NSS | USART2_CK |  |  | DCMI_HSYNC |  |  | SAI1_FS_B | LPTIM2_OUT | EVENTOUT
41 | PA5 | I/O |  |  |  | TIM2_CH1 | TIM2_ETR | TIM8_CH1N |  | SPI1_SCK |  |  |  |  |  |  |  |  | LPTIM2_ETR | EVENTOUT
42 | PA6 | I/O | USART3_CTS | UART3_CTS_IN |  | TIM1_BKIN | TIM3_CH1 | TIM8_BKIN | DCMI_PIXCLK | SPI1_MISO |  | USART3_CTS | LPUART1_CTS |  | QUADSPI_BK1_IO3 | LCD_SEG3 | TIM1_BKIN_COMP2 | TIM8_BKIN_COMP2 | TIM16_CH1 | EVENTOUT
43 | PA7 | I/O | TIM3_CH2 | MCU_OUT_PWM_LED_G |  | TIM1_CH1N | TIM3_CH2 | TIM8_CH1N | I2C3_SCL | SPI1_MOSI |  |  |  |  | QUADSPI_BK1_IO2 | LCD_SEG4 |  |  | TIM17_CH1 | EVENTOUT
44 | PC4 | I/O | USART3_TX | UART3_TX_OUT |  |  |  |  |  |  |  | USART3_TX |  |  | QUADSPI_BK2_IO3 | LCD_SEG22 |  |  |  | EVENTOUT
45 | PC5 | I/O | USART3_RX | UART3_RX_IN |  |  |  |  |  |  |  | USART3_RX |  |  |  | LCD_SEG23 |  |  |  | EVENTOUT
46 | PB0 | I/O | TIM3_CH3 | MCU_OUT_PWM_LED_B |  | TIM1_CH2N | TIM3_CH3 | TIM8_CH2N |  | SPI1_NSS |  | USART3_CK |  |  | QUADSPI_BK1_IO1 | LCD_SEG5 | COMP1_OUT | SAI1_EXTCLK |  | EVENTOUT
47 | PB1 | I/O | USART3_RTS | UART3_RTS_OUT |  | TIM1_CH3N | TIM3_CH4 | TIM8_CH3N |  |  | DFSDM1_DATIN0 | USART3_DE/USART3_RTS | LPUART1_DE/LPUART1_RTS |  | QUADSPI_BK1_IO0 | LCD_SEG6 |  |  | LPTIM2_IN1 | EVENTOUT
48 | PB2 | I/O |  |  | RTC_OUT_ALARM/RTC_OUT_CALIB | LPTIM1_OUT |  |  | I2C3_SMBA |  | DFSDM1_CKIN0 |  |  |  |  | LCD_VLCD |  |  |  | EVENTOUT
49 | PF11 | I/O |  |  |  |  |  |  |  |  |  |  |  |  | DCMI_D12 |  |  |  |  | EVENTOUT
50 | PF12 | I/O | GPIO_Analog |  |  |  |  |  |  |  |  |  |  |  |  |  | FMC_A6 |  |  | EVENTOUT
51 | VSS | Power
52 | VDD | Power
53 | PF13 | I/O |  |  |  |  |  |  | I2C4_SMBA |  | DFSDM1_DATIN6 |  |  |  |  |  | FMC_A7 |  |  | EVENTOUT
54 | PF14 | I/O | I2C4_SCL | MCU_I2C4_SCL |  |  |  |  | I2C4_SCL |  | DFSDM1_CKIN6 |  |  | TSC_G8_IO1 |  |  | FMC_A8 |  |  | EVENTOUT
55 | PF15 | I/O |  |  |  |  |  |  | I2C4_SDA |  |  |  |  | TSC_G8_IO2 |  |  | FMC_A9 |  |  | EVENTOUT
56 | PG0 | I/O | GPIO_Analog |  |  |  |  |  |  |  |  |  |  | TSC_G8_IO3 |  |  | FMC_A10 |  |  | EVENTOUT
57 | PG1 | I/O | GPIO_Analog |  |  |  |  |  |  |  |  |  |  | TSC_G8_IO4 |  |  | FMC_A11 |  |  | EVENTOUT
58 | PE7 | I/O | GPIO_Analog |  |  | TIM1_ETR |  |  |  |  | DFSDM1_DATIN2 |  |  |  |  |  | FMC_D4/FMC_DA4 | SAI1_SD_B |  | EVENTOUT
59 | PE8 | I/O | SAI1_SCK_B | I2S1B_SCK_OUT |  | TIM1_CH1N |  |  |  |  | DFSDM1_CKIN2 |  |  |  |  |  | FMC_D5/FMC_DA5 | SAI1_SCK_B |  | EVENTOUT
60 | PE9 | I/O | SAI1_FS_B | I2S1B_FS_OUT |  | TIM1_CH1 |  |  |  |  | DFSDM1_CKOUT |  |  |  |  |  | FMC_D6/FMC_DA6 | SAI1_FS_B |  | EVENTOUT
61 | VSS | Power
62 | VDD | Power
63 | PE10 | I/O | SAI1_MCLK_B | I2S1B_MCLK_OUT |  | TIM1_CH2N |  |  |  |  | DFSDM1_DATIN4 |  |  | TSC_G5_IO1 | QUADSPI_CLK |  | FMC_D7/FMC_DA7 | SAI1_MCLK_B |  | EVENTOUT
64 | PE11 | I/O | GPIO_Analog |  |  | TIM1_CH2 |  |  |  |  | DFSDM1_CKIN4 |  |  | TSC_G5_IO2 | QUADSPI_BK1_NCS |  | FMC_D8/FMC_DA8 |  |  | EVENTOUT
65 | PE12 | I/O | GPIO_Analog |  |  | TIM1_CH3N |  |  |  | SPI1_NSS | DFSDM1_DATIN5 |  |  | TSC_G5_IO3 | QUADSPI_BK1_IO0 |  | FMC_D9/FMC_DA9 |  |  | EVENTOUT
66 | PE13 | I/O | SPI1_SCK | MCU_SPI1_SCK |  | TIM1_CH3 |  |  |  | SPI1_SCK | DFSDM1_CKIN5 |  |  | TSC_G5_IO4 | QUADSPI_BK1_IO1 |  | FMC_D10/FMC_DA10 |  |  | EVENTOUT
67 | PE14 | I/O | SPI1_MISO | MCU_SPI1_MISO |  | TIM1_CH4 | TIM1_BKIN2 | TIM1_BKIN2_COMP2 |  | SPI1_MISO |  |  |  |  | QUADSPI_BK1_IO2 |  | FMC_D11/FMC_DA11 |  |  | EVENTOUT
68 | PE15 | I/O | SPI1_MOSI | MCU_SPI1_MOSI |  | TIM1_BKIN |  | TIM1_BKIN_COMP1 |  | SPI1_MOSI |  |  |  |  | QUADSPI_BK1_IO3 |  | FMC_D12/FMC_DA12 |  |  | EVENTOUT
69 | PB10 | I/O | GPIO_Analog |  |  | TIM2_CH3 |  | I2C4_SCL | I2C2_SCL | SPI2_SCK | DFSDM1_DATIN7 | USART3_TX | LPUART1_RX | TSC_SYNC | QUADSPI_CLK | LCD_SEG10 | COMP1_OUT | SAI1_SCK_A |  | EVENTOUT
70 | VDD12 | Power
71 | VSS | Power
72 | VDD | Power
73 | PB12 | I/O | GPIO_Analog |  |  | TIM1_BKIN |  | TIM1_BKIN_COMP2 | I2C2_SMBA | SPI2_NSS | DFSDM1_DATIN1 | USART3_CK | LPUART1_DE/LPUART1_RTS | TSC_G1_IO1 | CAN2_RX | LCD_SEG12 | SWPMI1_IO | SAI2_FS_A | TIM15_BKIN | EVENTOUT
74 | PB13 | I/O | SAI2_SCK_A | I2S2A_SCK_IN |  | TIM1_CH1N |  |  | I2C2_SCL | SPI2_SCK | DFSDM1_CKIN1 | USART3_CTS | LPUART1_CTS | TSC_G1_IO2 | CAN2_TX | LCD_SEG13 | SWPMI1_TX | SAI2_SCK_A | TIM15_CH1N | EVENTOUT
75 | PB14 | I/O | GPIO_Analog |  |  | TIM1_CH2N |  | TIM8_CH2N | I2C2_SDA | SPI2_MISO | DFSDM1_DATIN2 | USART3_DE/USART3_RTS |  | TSC_G1_IO3 |  | LCD_SEG14 | SWPMI1_RX | SAI2_MCLK_A | TIM15_CH1 | EVENTOUT
76 | PB15 | I/O |  |  | RTC_REFIN | TIM1_CH3N |  | TIM8_CH3N |  | SPI2_MOSI | DFSDM1_CKIN2 |  |  | TSC_G1_IO4 |  | LCD_SEG15 | SWPMI1_SUSPEND | SAI2_SD_A | TIM15_CH2 | EVENTOUT
77 | PD8 | I/O | GPIO_Analog |  |  |  |  |  |  |  |  | USART3_TX |  |  | DCMI_HSYNC | LCD_SEG28 | FMC_D13/FMC_DA13 |  |  | EVENTOUT
78 | PD9 | I/O | GPIO_Analog |  |  |  |  |  |  |  |  | USART3_RX |  |  | DCMI_PIXCLK | LCD_SEG29 | FMC_D14/FMC_DA14 | SAI2_MCLK_A |  | EVENTOUT
79 | PD10 | I/O | GPIO_Analog |  |  |  |  |  |  |  |  | USART3_CK |  | TSC_G6_IO1 |  | LCD_SEG30 | FMC_D15/FMC_DA15 | SAI2_SCK_A |  | EVENTOUT
80 | PD11 | I/O | SAI2_SD_A | I2S2A_SD_IN |  |  |  |  | I2C4_SMBA |  |  | USART3_CTS |  | TSC_G6_IO2 |  | LCD_SEG31 | FMC_A16 | SAI2_SD_A | LPTIM2_ETR | EVENTOUT
81 | PD12 | I/O | SAI2_FS_A | I2S2A_FS_IN |  |  | TIM4_CH1 |  | I2C4_SCL |  |  | USART3_DE/USART3_RTS |  | TSC_G6_IO3 |  | LCD_SEG32 | FMC_A17 | SAI2_FS_A | LPTIM2_IN1 | EVENTOUT
82 | PD13 | I/O | I2C4_SDA | MCU_I2C4_SDA |  |  | TIM4_CH2 |  | I2C4_SDA |  |  |  |  | TSC_G6_IO4 |  | LCD_SEG33 | FMC_A18 |  | LPTIM2_OUT | EVENTOUT
83 | VSS | Power
84 | VDD | Power
85 | PD14 | I/O | GPIO_Analog |  |  |  | TIM4_CH3 |  |  |  |  |  |  |  |  | LCD_SEG34 | FMC_D0/FMC_DA0 |  |  | EVENTOUT
86 | PD15 | I/O | GPIO_Analog |  |  |  | TIM4_CH4 |  |  |  |  |  |  |  |  | LCD_SEG35 | FMC_D1/FMC_DA1 |  |  | EVENTOUT
87 | PG2 | I/O | GPIO_Analog |  |  |  |  |  |  | SPI1_SCK |  |  |  |  |  |  | FMC_A12 | SAI2_SCK_B |  | EVENTOUT
88 | PG3 | I/O | GPIO_Analog |  |  |  |  |  |  | SPI1_MISO |  |  |  |  |  |  | FMC_A13 | SAI2_FS_B |  | EVENTOUT
89 | PG4 | I/O | GPIO_Analog |  |  |  |  |  |  | SPI1_MOSI |  |  |  |  |  |  | FMC_A14 | SAI2_MCLK_B |  | EVENTOUT
90 | PG5 | I/O |  |  |  |  |  |  |  | SPI1_NSS |  |  | LPUART1_CTS |  |  |  | FMC_A15 | SAI2_SD_B |  | EVENTOUT
91 | PG6 | I/O |  |  |  |  |  |  | I2C3_SMBA |  |  |  | LPUART1_DE/LPUART1_RTS |  |  |  |  |  |  | EVENTOUT
92 | PG7 | I/O | I2C3_SCL | MCU_I2C3_SCL |  |  |  |  | I2C3_SCL |  |  |  | LPUART1_TX |  |  |  | FMC_INT | SAI1_MCLK_A |  | EVENTOUT
93 | PG8 | I/O | I2C3_SDA | MCU_I2C3_SDA |  |  |  |  | I2C3_SDA |  |  |  | LPUART1_RX |  |  |  |  |  |  | EVENTOUT
94 | VSS | Power
95 | VDDIO2 | Power
96 | PC6 | I/O | TIM3_CH1 | MCU_OUT_PWM_LED_R |  |  | TIM3_CH1 | TIM8_CH1 |  |  | DFSDM1_CKIN3 |  |  | TSC_G4_IO1 | DCMI_D0 | LCD_SEG24 | SDMMC1_D6 | SAI2_MCLK_A |  | EVENTOUT
97 | PC7 | I/O |  |  |  |  | TIM3_CH2 | TIM8_CH2 |  |  | DFSDM1_DATIN3 |  |  | TSC_G4_IO2 | DCMI_D1 | LCD_SEG25 | SDMMC1_D7 | SAI2_MCLK_B |  | EVENTOUT
98 | PC8 | I/O | GPIO_Analog |  |  |  | TIM3_CH3 | TIM8_CH3 |  |  |  |  |  | TSC_G4_IO3 | DCMI_D2 | LCD_SEG26 | SDMMC1_D0 |  |  | EVENTOUT
99 | PC9 | I/O | GPIO_Analog |  |  | TIM8_BKIN2 | TIM3_CH4 | TIM8_CH4 | DCMI_D3 |  | I2C3_SDA |  |  | TSC_G4_IO4 | USB_OTG_FS_NOE | LCD_SEG27 | SDMMC1_D1 | SAI2_EXTCLK | TIM8_BKIN2_COMP1 | EVENTOUT
100 | PA8 | I/O | RCC_MCO | MCU_MCO | RCC_MCO | TIM1_CH1 |  |  |  |  |  | USART1_CK |  |  | USB_OTG_FS_SOF | LCD_COM0 | SWPMI1_IO | SAI1_SCK_A | LPTIM2_OUT | EVENTOUT
101 | PA9 | I/O | USB_OTG_FS_VBUS | MCU_IN_VBUS |  | TIM1_CH2 |  | SPI2_SCK |  | DCMI_D0 |  | USART1_TX |  |  |  | LCD_COM1 |  | SAI1_FS_A | TIM15_BKIN | EVENTOUT
102 | PA10 | I/O |  |  |  | TIM1_CH3 |  |  |  | DCMI_D1 |  | USART1_RX |  |  | USB_OTG_FS_ID | LCD_COM2 |  | SAI1_SD_A | TIM17_BKIN | EVENTOUT
103 | PA11 | I/O | USB_OTG_FS_DM | PA_USB_N |  | TIM1_CH4 | TIM1_BKIN2 |  |  | SPI1_MISO |  | USART1_CTS |  | CAN1_RX | USB_OTG_FS_DM |  | TIM1_BKIN2_COMP1 |  |  | EVENTOUT
104 | PA12 | I/O | USB_OTG_FS_DP | PA_USB_P |  | TIM1_ETR |  |  |  | SPI1_MOSI |  | USART1_DE/USART1_RTS |  | CAN1_TX | USB_OTG_FS_DP |  |  |  |  | EVENTOUT
105 | PA13 (JTMS/SWDIO) | I/O | GPIO_Analog |  | SYS_JTMS-SWDIO | IR_OUT |  |  |  |  |  |  |  |  | USB_OTG_FS_NOE |  | SWPMI1_TX | SAI1_SD_B |  | EVENTOUT
106 | VDDUSB | Power
107 | VSS | Power
108 | VDD | Power
109 | PA14 (JTCK/SWCLK) | I/O | SYS_JTCK-SWCLK | MCU_IN_SWCLK | SYS_JTCK-SWCLK | LPTIM1_OUT |  |  | I2C1_SMBA | I2C4_SMBA |  |  |  |  | USB_OTG_FS_SOF |  | SWPMI1_RX | SAI1_FS_B |  | EVENTOUT
110 | PA15 (JTDI) | I/O |  |  | SYS_JTDI | TIM2_CH1 | TIM2_ETR | USART2_RX |  | SPI1_NSS | SPI3_NSS | USART3_DE/USART3_RTS | UART4_DE/UART4_RTS | TSC_G3_IO1 |  | LCD_SEG17 | SWPMI1_SUSPEND | SAI2_FS_B |  | EVENTOUT
111 | PC10 | I/O | SPI3_SCK | MCU_SPI3_SCK | SYS_TRACED1 |  |  |  |  |  | SPI3_SCK | USART3_TX | UART4_TX | TSC_G3_IO2 | DCMI_D8 | LCD_COM4/LCD_SEG28/LCD_SEG40 | SDMMC1_D2 | SAI2_SCK_B |  | EVENTOUT
112 | PC11 | I/O | SPI3_MISO | MCU_SPI3_MISO |  |  |  |  |  | QUADSPI_BK2_NCS | SPI3_MISO | USART3_RX | UART4_RX | TSC_G3_IO3 | DCMI_D4 | LCD_COM5/LCD_SEG29/LCD_SEG41 | SDMMC1_D3 | SAI2_MCLK_B |  | EVENTOUT
113 | PC12 | I/O | SPI3_MOSI | MCU_SPI3_MOSI | SYS_TRACED3 |  |  |  |  |  | SPI3_MOSI | USART3_CK | UART5_TX | TSC_G3_IO4 | DCMI_D9 | LCD_COM6/LCD_SEG30/LCD_SEG42 | SDMMC1_CK | SAI2_SD_B |  | EVENTOUT
114 | PD0 | I/O | GPIO_Analog |  |  |  |  |  |  | SPI2_NSS | DFSDM1_DATIN7 |  |  | CAN1_RX |  |  | FMC_D2/FMC_DA2 |  |  | EVENTOUT
115 | PD1 | I/O | GPIO_Analog |  |  |  |  |  |  | SPI2_SCK | DFSDM1_CKIN7 |  |  | CAN1_TX |  |  | FMC_D3/FMC_DA3 |  |  | EVENTOUT
116 | PD2 | I/O | GPIO_Analog |  | SYS_TRACED2 |  | TIM3_ETR |  |  |  |  | USART3_DE/USART3_RTS | UART5_RX | TSC_SYNC | DCMI_D11 | LCD_COM7/LCD_SEG31/LCD_SEG43 | SDMMC1_CMD |  |  | EVENTOUT
117 | PD3 | I/O | GPIO_Analog |  |  |  |  | SPI2_SCK | DCMI_D5 | SPI2_MISO | DFSDM1_DATIN0 | USART2_CTS |  |  | QUADSPI_BK2_NCS |  | FMC_CLK |  |  | EVENTOUT
118 | PD4 | I/O | USART2_RTS | UART2_RTS_OUT |  |  |  |  |  | SPI2_MOSI | DFSDM1_CKIN0 | USART2_DE/USART2_RTS |  |  | QUADSPI_BK2_IO0 |  | FMC_NOE |  |  | EVENTOUT
119 | PD5 | I/O | GPIO_Analog |  |  |  |  |  |  |  |  | USART2_TX |  |  | QUADSPI_BK2_IO1 |  | FMC_NWE |  |  | EVENTOUT
120 | VSS | Power
121 | VDD | Power
122 | PD6 | I/O | USART2_RX | UART2_RX_IN |  |  |  |  | DCMI_D10 | QUADSPI_BK2_IO1 | DFSDM1_DATIN1 | USART2_RX |  |  | QUADSPI_BK2_IO2 |  | FMC_NWAIT | SAI1_SD_A |  | EVENTOUT
123 | PD7 | I/O | GPIO_Analog |  |  |  |  |  |  |  | DFSDM1_CKIN1 | USART2_CK |  |  | QUADSPI_BK2_IO3 |  | FMC_NE1 |  |  | EVENTOUT
124 | PG9 | I/O | USART1_TX | UART1_TX_OUT |  |  |  |  |  |  | SPI3_SCK | USART1_TX |  |  |  |  | FMC_NCE/FMC_NE2 | SAI2_SCK_A | TIM15_CH1N | EVENTOUT
125 | PG10 | I/O | USART1_RX | UART1_RX_IN |  | LPTIM1_IN1 |  |  |  |  | SPI3_MISO | USART1_RX |  |  |  |  | FMC_NE3 | SAI2_FS_A | TIM15_CH1 | EVENTOUT
126 | PG11 | I/O | USART1_CTS | UART1_CTS_IN |  | LPTIM1_IN2 |  |  |  |  | SPI3_MOSI | USART1_CTS |  |  |  |  |  | SAI2_MCLK_A | TIM15_CH2 | EVENTOUT
127 | PG12 | I/O | USART1_RTS | UART1_RTS_OUT |  | LPTIM1_ETR |  |  |  |  | SPI3_NSS | USART1_DE/USART1_RTS |  |  |  |  | FMC_NE4 | SAI2_SD_A |  | EVENTOUT
128 | PG13 | I/O | I2C1_SDA | MCU_I2C1_SDA |  |  |  |  | I2C1_SDA |  |  | USART1_CK |  |  |  |  | FMC_A24 |  |  | EVENTOUT
129 | PG14 | I/O | I2C1_SCL | MCU_I2C1_SCL |  |  |  |  | I2C1_SCL |  |  |  |  |  |  |  | FMC_A25 |  |  | EVENTOUT
130 | VSS | Power
131 | VDDIO2 | Power
132 | PB3 (JTDO/TRACESWO) | I/O | GPIO_Analog |  | SYS_JTDO-SWO | TIM2_CH2 |  |  |  | SPI1_SCK | SPI3_SCK | USART1_DE/USART1_RTS |  |  | CRS_SYNC | LCD_SEG7 |  | SAI1_SCK_B |  | EVENTOUT
133 | PB4 (NJTRST) | I/O |  |  | SYS_JTRST |  | TIM3_CH1 |  | I2C3_SDA | SPI1_MISO | SPI3_MISO | USART1_CTS | UART5_DE/UART5_RTS | TSC_G2_IO1 | DCMI_D12 | LCD_SEG8 |  | SAI1_MCLK_B | TIM17_BKIN | EVENTOUT
134 | PB5 | I/O | GPIO_Analog |  |  | LPTIM1_IN1 | TIM3_CH2 | CAN2_RX | I2C1_SMBA | SPI1_MOSI | SPI3_MOSI | USART1_CK | UART5_CTS | TSC_G2_IO2 | DCMI_D10 | LCD_SEG9 | COMP2_OUT | SAI1_SD_B | TIM16_BKIN | EVENTOUT
135 | PB6 | I/O | GPIO_Analog |  |  | LPTIM1_ETR | TIM4_CH1 | TIM8_BKIN2 | I2C1_SCL | I2C4_SCL | DFSDM1_DATIN5 | USART1_TX | CAN2_TX | TSC_G2_IO3 | DCMI_D5 |  | TIM8_BKIN2_COMP2 | SAI1_FS_B | TIM16_CH1N | EVENTOUT
136 | PB7 | I/O | GPIO_Analog |  |  | LPTIM1_IN2 | TIM4_CH2 | TIM8_BKIN | I2C1_SDA | I2C4_SDA | DFSDM1_CKIN5 | USART1_RX | UART4_CTS | TSC_G2_IO4 | DCMI_VSYNC | LCD_SEG21 | FMC_NL | TIM8_BKIN_COMP1 | TIM17_CH1N | EVENTOUT
137 | PH3-BOOT0 | I/O |  |  |  |  |  |  |  |  |  |  |  |  |  |  |  |  |  | EVENTOUT
138 | PB8 | I/O |  |  |  |  | TIM4_CH3 |  | I2C1_SCL |  | DFSDM1_DATIN6 |  |  | CAN1_RX | DCMI_D6 | LCD_SEG16 | SDMMC1_D4 | SAI1_MCLK_A | TIM16_CH1 | EVENTOUT
139 | PB9 | I/O |  |  |  | IR_OUT | TIM4_CH4 |  | I2C1_SDA | SPI2_NSS | DFSDM1_CKIN6 |  |  | CAN1_TX | DCMI_D7 | LCD_COM3 | SDMMC1_D5 | SAI1_FS_A | TIM17_CH1 | EVENTOUT
140 | PE0 | I/O | GPIO_Analog |  |  |  | TIM4_ETR |  |  |  |  |  |  |  | DCMI_D2 | LCD_SEG36 | FMC_NBL0 |  | TIM16_CH1 | EVENTOUT
141 | PE1 | I/O |  |  |  |  |  |  |  |  |  |  |  |  | DCMI_D3 | LCD_SEG37 | FMC_NBL1 |  | TIM17_CH1 | EVENTOUT
142 | VDD12 | Power
143 | VSS | Power
144 | VDD | Power

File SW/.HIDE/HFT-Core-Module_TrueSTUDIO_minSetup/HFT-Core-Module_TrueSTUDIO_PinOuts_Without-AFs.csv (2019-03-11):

Position | Name | Type | Signal | Label
1 | PE2 | I/O | GPIO_Analog
2 | PE3 | I/O | GPIO_Analog
3 | PE4 | I/O | GPIO_Analog
4 | PE5 | I/O | GPIO_Analog
5 | PE6 | I/O
6 | VBAT | Power
7 | PC13 | I/O | SYS_WKUP2 | MCU_IN_WAKEUP
8 | PC14-OSC32_IN (PC14) | I/O | RCC_OSC32_IN | MCU_OSC32_IN
9 | PC15-OSC32_OUT (PC15) | I/O | RCC_OSC32_OUT | MCU_OSC32_OUT
10 | PF0 | I/O | I2C2_SDA | MCU_I2C2_SDA
11 | PF1 | I/O | I2C2_SCL | MCU_I2C2_SCL
12 | PF2 | I/O | GPIO_Analog
13 | PF3 | I/O | ADC3_IN6 | ADC3_IN6_20MHZ_PULL
14 | PF4 | I/O
15 | PF5 | I/O
16 | VSS | Power
17 | VDD | Power
18 | PF6 | I/O | TIM5_CH1 | MCU_IN_TIMCAP_N
19 | PF7 | I/O | TIM5_CH2 | MCU_IN_TIMCAP_W
20 | PF8 | I/O | TIM5_CH3 | MCU_IN_TIMCAP_S
21 | PF9 | I/O | TIM5_CH4 | MCU_IN_TIMCAP_VSOL
22 | PF10 | I/O | GPIO_Analog
23 | PH0-OSC_IN (PH0) | I/O | RCC_OSC_IN | MCU_HSE
24 | PH1-OSC_OUT (PH1) | I/O
25 | NRST | Reset
26 | PC0 | I/O | GPIO_Analog
27 | PC1 | I/O | GPIO_Analog
28 | PC2 | I/O | GPIO_Analog
29 | PC3 | I/O | GPIO_Analog
30 | VSSA | Power
31 | VREF- | Power
32 | VREF+ | MonoIO | VREFBUF_OUT | MCU_OUT_VREF+
33 | VDDA | Power
34 | PA0 | I/O | USART2_CTS | UART2_CTS_IN
35 | PA1 | I/O
36 | PA2 | I/O | USART2_TX | UART2_TX_OUT
37 | PA3 | I/O | ADC2_IN8 ADC1_IN8 | MCU_VSOL_ADC1
38 | VSS | Power
39 | VDD | Power
40 | PA4 | I/O
41 | PA5 | I/O
42 | PA6 | I/O | USART3_CTS | UART3_CTS_IN
43 | PA7 | I/O | TIM3_CH2 | MCU_OUT_PWM_LED_G
44 | PC4 | I/O | USART3_TX | UART3_TX_OUT
45 | PC5 | I/O | USART3_RX | UART3_RX_IN
46 | PB0 | I/O | TIM3_CH3 | MCU_OUT_PWM_LED_B
47 | PB1 | I/O | USART3_RTS | UART3_RTS_OUT
48 | PB2 | I/O
49 | PF11 | I/O
50 | PF12 | I/O | GPIO_Analog
51 | VSS | Power
52 | VDD | Power
53 | PF13 | I/O
54 | PF14 | I/O | I2C4_SCL | MCU_I2C4_SCL
55 | PF15 | I/O
56 | PG0 | I/O | GPIO_Analog
57 | PG1 | I/O | GPIO_Analog
58 | PE7 | I/O | GPIO_Analog
59 | PE8 | I/O | SAI1_SCK_B | I2S1B_SCK_OUT
60 | PE9 | I/O | SAI1_FS_B | I2S1B_FS_OUT
61 | VSS | Power
62 | VDD | Power
63 | PE10 | I/O | SAI1_MCLK_B | I2S1B_MCLK_OUT
64 | PE11 | I/O | GPIO_Analog
65 | PE12 | I/O | GPIO_Analog
66 | PE13 | I/O | SPI1_SCK | MCU_SPI1_SCK
67 | PE14 | I/O | SPI1_MISO | MCU_SPI1_MISO
68 | PE15 | I/O | SPI1_MOSI | MCU_SPI1_MOSI
69 | PB10 | I/O | GPIO_Analog
70 | VDD12 | Power
71 | VSS | Power
72 | VDD | Power
73 | PB12 | I/O | GPIO_Analog
74 | PB13 | I/O | SAI2_SCK_A | I2S2A_SCK_IN
75 | PB14 | I/O | GPIO_Analog
76 | PB15 | I/O
77 | PD8 | I/O | GPIO_Analog
78 | PD9 | I/O | GPIO_Analog
79 | PD10 | I/O | GPIO_Analog
80 | PD11 | I/O | SAI2_SD_A | I2S2A_SD_IN
81 | PD12 | I/O | SAI2_FS_A | I2S2A_FS_IN
82 | PD13 | I/O | I2C4_SDA | MCU_I2C4_SDA
83 | VSS | Power
84 | VDD | Power
85 | PD14 | I/O | GPIO_Analog
86 | PD15 | I/O | GPIO_Analog
87 | PG2 | I/O | GPIO_Analog
88 | PG3 | I/O | GPIO_Analog
89 | PG4 | I/O | GPIO_Analog
90 | PG5 | I/O
91 | PG6 | I/O
92 | PG7 | I/O | I2C3_SCL | MCU_I2C3_SCL
93 | PG8 | I/O | I2C3_SDA | MCU_I2C3_SDA
94 | VSS | Power
95 | VDDIO2 | Power
96 | PC6 | I/O | TIM3_CH1 | MCU_OUT_PWM_LED_R
97 | PC7 | I/O
98 | PC8 | I/O | GPIO_Analog
99 | PC9 | I/O | GPIO_Analog
100 | PA8 | I/O | RCC_MCO | MCU_MCO
101 | PA9 | I/O | USB_OTG_FS_VBUS | MCU_IN_VBUS
102 | PA10 | I/O
103 | PA11 | I/O | USB_OTG_FS_DM | PA_USB_N
104 | PA12 | I/O | USB_OTG_FS_DP | PA_USB_P
105 | PA13 (JTMS/SWDIO) | I/O | GPIO_Analog
106 | VDDUSB | Power
107 | VSS | Power
108 | VDD | Power
109 | PA14 (JTCK/SWCLK) | I/O | SYS_JTCK-SWCLK | MCU_IN_SWCLK
110 | PA15 (JTDI) | I/O
111 | PC10 | I/O | SPI3_SCK | MCU_SPI3_SCK
112 | PC11 | I/O | SPI3_MISO | MCU_SPI3_MISO
113 | PC12 | I/O | SPI3_MOSI | MCU_SPI3_MOSI
114 | PD0 | I/O | GPIO_Analog
115 | PD1 | I/O | GPIO_Analog
116 | PD2 | I/O | GPIO_Analog
117 | PD3 | I/O | GPIO_Analog
118 | PD4 | I/O | USART2_RTS | UART2_RTS_OUT
119 | PD5 | I/O | GPIO_Analog
120 | VSS | Power
121 | VDD | Power
122 | PD6 | I/O | USART2_RX | UART2_RX_IN
123 | PD7 | I/O | GPIO_Analog
124 | PG9 | I/O | USART1_TX | UART1_TX_OUT
125 | PG10 | I/O | USART1_RX | UART1_RX_IN
126 | PG11 | I/O | USART1_CTS | UART1_CTS_IN
127 | PG12 | I/O | USART1_RTS | UART1_RTS_OUT
128 | PG13 | I/O | I2C1_SDA | MCU_I2C1_SDA
129 | PG14 | I/O | I2C1_SCL | MCU_I2C1_SCL
130 | VSS | Power
131 | VDDIO2 | Power
132 | PB3 (JTDO/TRACESWO) | I/O | GPIO_Analog
133 | PB4 (NJTRST) | I/O
134 | PB5 | I/O | GPIO_Analog
135 | PB6 | I/O | GPIO_Analog
136 | PB7 | I/O | GPIO_Analog
137 | PH3-BOOT0 | I/O
138 | PB8 | I/O
139 | PB9 | I/O
140 | PE0 | I/O | GPIO_Analog
141 | PE1 | I/O
142 | VDD12 | Power
143 | VSS | Power
144 | VDD | Power

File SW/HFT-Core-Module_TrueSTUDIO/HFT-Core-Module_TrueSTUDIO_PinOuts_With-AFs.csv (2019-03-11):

Position | Name | Type | Signal | Label | AF0 | AF1 | AF2 | AF3 | AF4 | AF5 | AF6 | AF7 | AF8 | AF9 | AF10 | AF11 | AF12 | AF13 | AF14 | AF15
1 | PE2 | I/O |  |  | SYS_TRACECLK |  | TIM3_ETR |  |  |  |  |  |  | TSC_G7_IO1 |  | LCD_SEG38 | FMC_A23 | SAI1_MCLK_A |  | EVENTOUT
2 | PE3 | I/O | SAI1_SD_B | MCU_I2S1B_SD_OUT | SYS_TRACED0 |  | TIM3_CH1 |  |  |  |  |  |  | TSC_G7_IO2 |  | LCD_SEG39 | FMC_A19 | SAI1_SD_B |  | EVENTOUT
3 | PE4 | I/O |  |  | SYS_TRACED1 |  | TIM3_CH2 |  |  |  | DFSDM1_DATIN3 |  |  | TSC_G7_IO3 | DCMI_D4 |  | FMC_A20 | SAI1_FS_A |  | EVENTOUT
4 | PE5 | I/O |  |  | SYS_TRACED2 |  | TIM3_CH3 |  |  |  | DFSDM1_CKIN3 |  |  | TSC_G7_IO4 | DCMI_D6 |  | FMC_A21 | SAI1_SCK_A |  | EVENTOUT
5 | PE6 | I/O | TIM3_CH4 | MCU_PWM_LCD_BL | SYS_TRACED3 |  | TIM3_CH4 |  |  |  |  |  |  |  | DCMI_D7 |  | FMC_A22 | SAI1_SD_A |  | EVENTOUT
6 | VBAT | Power
7 | PC13 | I/O | SYS_WKUP2 | MCU_WAKEUP_IN |  |  |  |  |  |  |  |  |  |  |  |  |  |  |  | EVENTOUT
8 | PC14-OSC32_IN (PC14) | I/O | RCC_OSC32_IN | MCU_OSC32_IN |  |  |  |  |  |  |  |  |  |  |  |  |  |  |  | EVENTOUT
9 | PC15-OSC32_OUT (PC15) | I/O | RCC_OSC32_OUT | MCU_OSC32_OUT |  |  |  |  |  |  |  |  |  |  |  |  |  |  |  | EVENTOUT
10 | PF0 | I/O | I2C2_SDA | MCU_I2C2_SDA |  |  |  |  | I2C2_SDA |  |  |  |  |  |  |  | FMC_A0 |  |  | EVENTOUT
11 | PF1 | I/O | I2C2_SCL | MCU_I2C2_SCL |  |  |  |  | I2C2_SCL |  |  |  |  |  |  |  | FMC_A1 |  |  | EVENTOUT
12 | PF2 | I/O |  |  |  |  |  |  | I2C2_SMBA |  |  |  |  |  |  |  | FMC_A2 |  |  | EVENTOUT
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

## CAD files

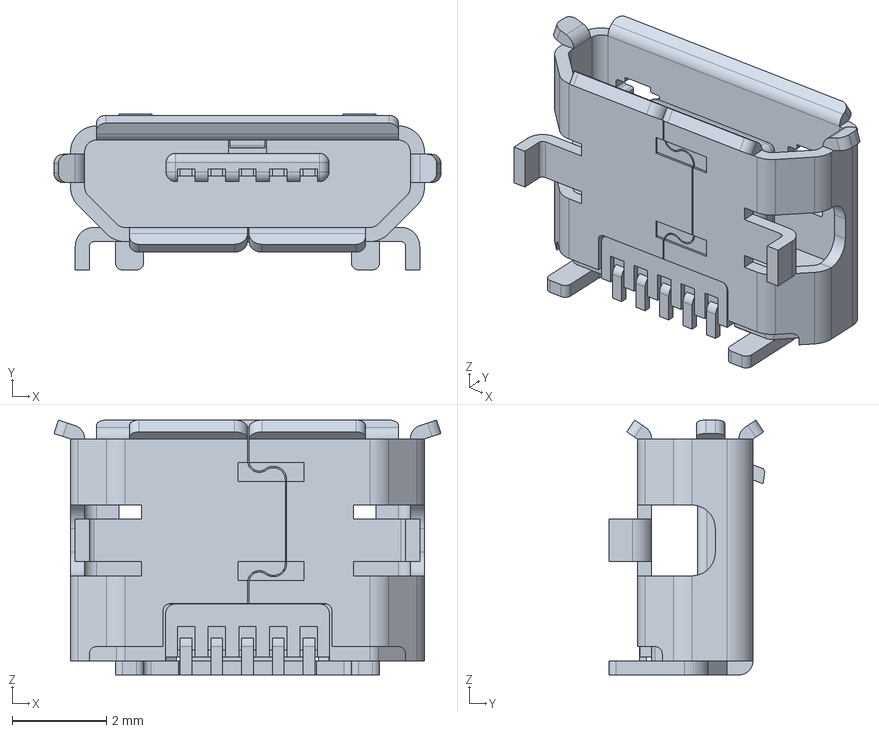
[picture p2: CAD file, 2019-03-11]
Docs/72_USB-connectors/USB-B_Receptacle_SMT/_used_for_HW-1V1/MOLEX_Micro-USB-Receptacle_PartNo-105017-0001/3D-Model/1050170001.stp
8.20 x 3.30 x 5.40 mm

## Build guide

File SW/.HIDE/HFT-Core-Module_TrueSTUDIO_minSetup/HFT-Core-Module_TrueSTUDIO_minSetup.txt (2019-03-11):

Configuration	HFT-Core-Module_TrueSTUDIO_minSetup
STM32CubeMX 	4.26.1
Date	10/07/2018
MCU	STM32L496ZGTxP

PERIPHERALS	MODES	FUNCTIONS	PINS
RCC	Crystal/Ceramic Resonator	RCC_OSC32_IN	PC14-OSC32_IN (PC14)
RCC	Crystal/Ceramic Resonator	RCC_OSC32_OUT	PC15-OSC32_OUT (PC15)
RTC	Activate RTC Clock Source	RTC_VS_RTC_Activate	VP_RTC_VS_RTC_Activate
RTC	RTC Enabled	RTC_VS_RTC_Calendar	VP_RTC_VS_RTC_Calendar
RTC	Internal Alarm A	RTC_VS_RTC_Alarm_A_Intern	VP_RTC_VS_RTC_Alarm_A_Intern
RTC	Internal Alarm B	RTC_VS_RTC_Alarm_B_Intern	VP_RTC_VS_RTC_Alarm_B_Intern
RTC	Internal WakeUp	RTC_VS_RTC_WakeUp_intern	VP_RTC_VS_RTC_WakeUp_intern
SYS	Power Voltage Detector In (Internal analog voltage)	SYS_V_PVD_IN	VP_SYS_V_PVD_IN
SYS	Internal voltage reference	VREFBUF_OUT	VREF+
SYS	TIM2	SYS_VS_tim2	VP_SYS_VS_tim2

Pin Nb	PINs	FUNCTIONs	LABELs
1	PE2	GPIO_Analog	
2	PE3	GPIO_Analog	
3	PE4	GPIO_Analog	
4	PE5	GPIO_Analog	
7	PC13*	SYS_WKUP2	MCU_IN_WAKEUP
8	PC14-OSC32_IN (PC14)	RCC_OSC32_IN	MCU_OSC32_IN
9	PC15-OSC32_OUT (PC15)	RCC_OSC32_OUT	MCU_OSC32_OUT
10	PF0*	I2C2_SDA	MCU_I2C2_SDA
11	PF1*	I2C2_SCL	MCU_I2C2_SCL
12	PF2	GPIO_Analog	
13	PF3*	ADC3_IN6	ADC3_IN6_20MHZ_PULL
18	PF6*	TIM5_CH1	MCU_IN_TIMCAP_N
19	PF7*	TIM5_CH2	MCU_IN_TIMCAP_W
20	PF8*	TIM5_CH3	MCU_IN_TIMCAP_S
21	PF9*	TIM5_CH4	MCU_IN_TIMCAP_VSOL
22	PF10	GPIO_Analog	
23	PH0-OSC_IN (PH0)*	RCC_OSC_IN	MCU_HSE
26	PC0	GPIO_Analog	
27	PC1	GPIO_Analog	
28	PC2	GPIO_Analog	
29	PC3	GPIO_Analog	
32	VREF+	VREFBUF_OUT	MCU_OUT_VREF+
34	PA0*	USART2_CTS	UART2_CTS_IN
36	PA2*	USART2_TX	UART2_TX_OUT
37	PA3*	ADC2_IN8 ADC1_IN8	MCU_VSOL_ADC1
42	PA6*	USART3_CTS	UART3_CTS_IN
43	PA7*	TIM3_CH2	MCU_OUT_PWM_LED_G
44	PC4*	USART3_TX	UART3_TX_OUT
45	PC5*	USART3_RX	UART3_RX_IN
46	PB0*	TIM3_CH3	MCU_OUT_PWM_LED_B
47	PB1*	USART3_RTS	UART3_RTS_OUT
50	PF12	GPIO_Analog	
54	PF14*	I2C4_SCL	MCU_I2C4_SCL
56	PG0	GPIO_Analog	
57	PG1	GPIO_Analog	
58	PE7	GPIO_Analog	
59	PE8*	SAI1_SCK_B	I2S1B_SCK_OUT
60	PE9*	SAI1_FS_B	I2S1B_FS_OUT
63	PE10*	SAI1_MCLK_B	I2S1B_MCLK_OUT
64	PE11	GPIO_Analog	
65	PE12	GPIO_Analog	
66	PE13*	SPI1_SCK	MCU_SPI1_SCK
67	PE14*	SPI1_MISO	MCU_SPI1_MISO
68	PE15*	SPI1_MOSI	MCU_SPI1_MOSI
69	PB10	GPIO_Analog	
73	PB12	GPIO_Analog	
74	PB13*	SAI2_SCK_A	I2S2A_SCK_IN
75	PB14	GPIO_Analog	
77	PD8	GPIO_Analog	
78	PD9	GPIO_Analog	
79	PD10	GPIO_Analog	
80	PD11*	SAI2_SD_A	I2S2A_SD_IN
81	PD12*	SAI2_FS_A	I2S2A_FS_IN
82	PD13*	I2C4_SDA	MCU_I2C4_SDA
85	PD14	GPIO_Analog	
86	PD15	GPIO_Analog	
87	PG2	GPIO_Analog	
88	PG3	GPIO_Analog	
89	PG4	GPIO_Analog	
92	PG7*	I2C3_SCL	MCU_I2C3_SCL
93	PG8*	I2C3_SDA	MCU_I2C3_SDA
96	PC6*	TIM3_CH1	MCU_OUT_PWM_LED_R
98	PC8	GPIO_Analog	
99	PC9	GPIO_Analog	
100	PA8*	RCC_MCO	MCU_MCO
101	PA9*	USB_OTG_FS_VBUS	MCU_IN_VBUS
103	PA11*	USB_OTG_FS_DM	PA_USB_N
104	PA12*	USB_OTG_FS_DP	PA_USB_P
105	PA13 (JTMS/SWDIO)	GPIO_Analog	
109	PA14 (JTCK/SWCLK)*	SYS_JTCK-SWCLK	MCU_IN_SWCLK
111	PC10*	SPI3_SCK	MCU_SPI3_SCK
112	PC11*	SPI3_MISO	MCU_SPI3_MISO
113	PC12*	SPI3_MOSI	MCU_SPI3_MOSI
114	PD0	GPIO_Analog	
115	PD1	GPIO_Analog	
116	PD2	GPIO_Analog	
117	PD3	GPIO_Analog	
118	PD4*	USART2_RTS	UART2_RTS_OUT
119	PD5	GPIO_Analog	
122	PD6*	USART2_RX	UART2_RX_IN
123	PD7	GPIO_Analog	
124	PG9*	USART1_TX	UART1_TX_OUT
125	PG10*	USART1_RX	UART1_RX_IN
126	PG11*	USART1_CTS	UART1_CTS_IN
127	PG12*	USART1_RTS	UART1_RTS_OUT
128	PG13*	I2C1_SDA	MCU_I2C1_SDA
129	PG14*	I2C1_SCL	MCU_I2C1_SCL
132	PB3 (JTDO/TRACESWO)	GPIO_Analog	
134	PB5	GPIO_Analog	
135	PB6	GPIO_Analog	
136	PB7	GPIO_Analog	
140	PE0	GPIO_Analog	

SOFTWARE PROJECT

Project Settings : 
Project Name : HFT-Core-Module_TrueSTUDIO_minSetup
Project Folder : Z:\nfs_ds_nfs\git\HFT-Core-Module__SW\SW\TrueSTUDIO\HFT-Core-Module_TrueSTUDIO_minSetup
Toolchain / IDE : TrueSTUDIO
Firmware Package Name and Version : STM32Cube FW_L4 V1.12.0

Code Generation Settings : 
STM32Cube Firmware Library Package : Copy only the necessary library files
Generate peripheral initialization as a pair of '.c/.h' files per peripheral : No
Backup previously generated files when re-generating : No
Delete previously generated files when not re-generated : Yes
Set all free pins as analog (to optimize the power consumption) : No

Toolchains Settings : 
Compiler Optimizations :

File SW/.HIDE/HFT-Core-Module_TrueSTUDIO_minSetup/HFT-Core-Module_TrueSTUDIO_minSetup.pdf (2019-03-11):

## HFT-Core-Module_TrueSTUDIO_minSetup Project Configuration Report

# 1. Description

## 1.1. Project

Project Name | HFT-Core-Module_TrueSTUDIO_minSetup
Board Name | HFT-Core-Module_TrueSTUDIO
Generated with: | STM32CubeMX 4.26.1
Date | 10/07/2018

## 1.2. MCU

MCU Series | STM32L4
MCU Line | STM32L4x6
MCU name | STM32L496ZGTxP
MCU Package | LQFP144
MCU Pin number | 144

# 2. Pinout Configuration

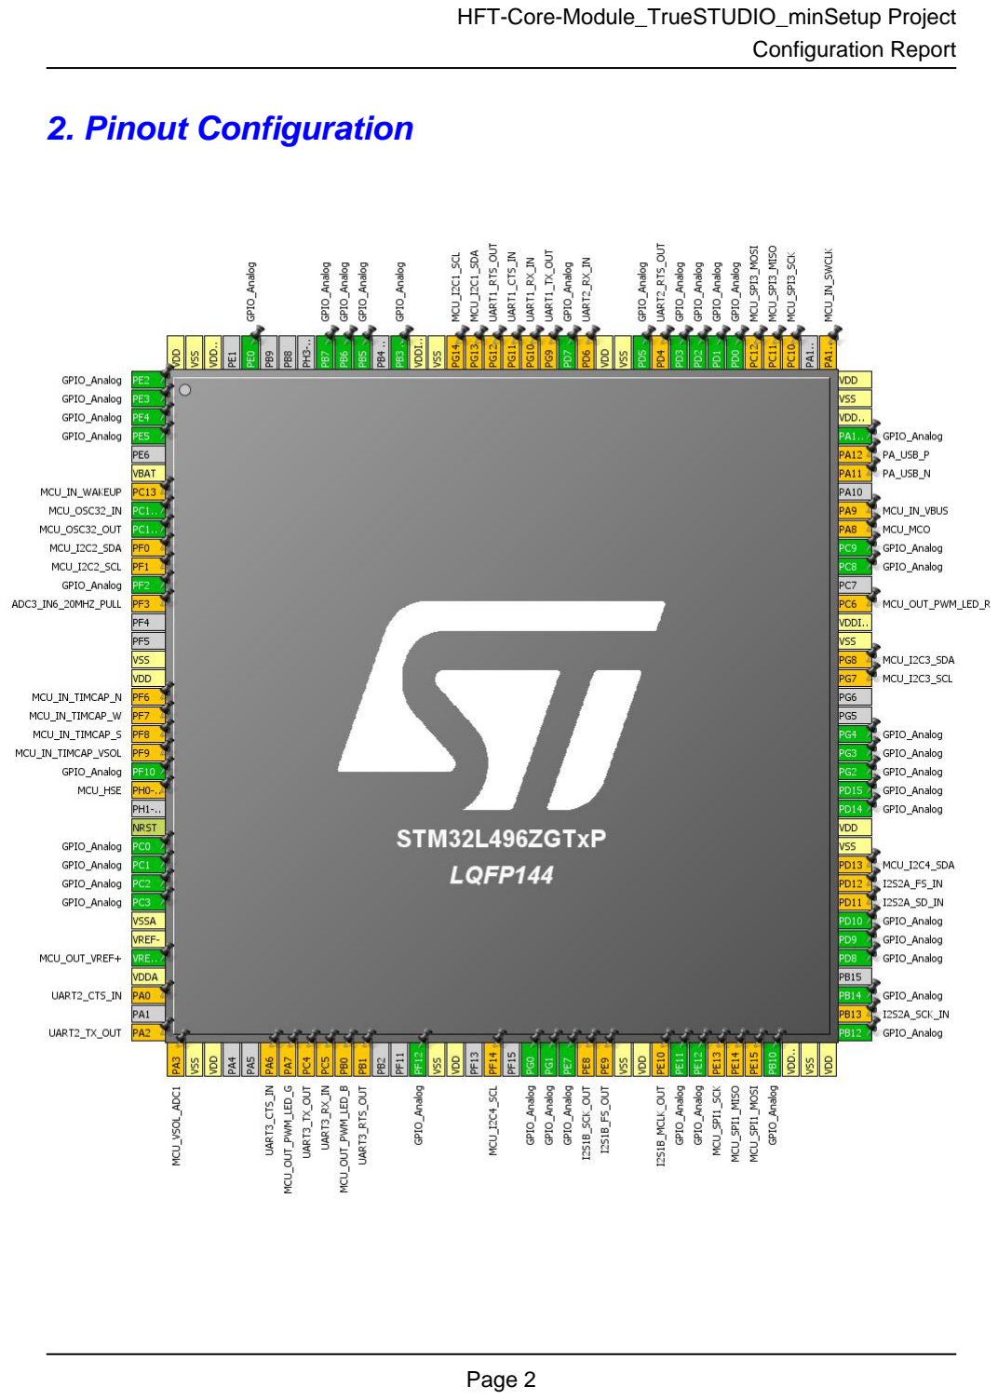
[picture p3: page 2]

# 3. Pins Configuration

Pin Number LQFP144 | Pin Name (function after reset) | Pin Type | Alternate Function(s) | Label
1 | PE2 * | I/O | GPIO_Analog
2 | PE3 * | I/O | GPIO_Analog
3 | PE4 * | I/O | GPIO_Analog
4 | PE5 * | I/O | GPIO_Analog
6 | VBAT | Power
7 | PC13 ** | I/O | SYS_WKUP2 | MCU_IN_WAKEUP
8 | PC14-OSC32_IN (PC14) | I/O | RCC_OSC32_IN | MCU_OSC32_IN
9 | PC15-OSC32_OUT (PC15) | I/O | RCC_OSC32_OUT | MCU_OSC32_OUT
10 | PF0 ** | I/O | I2C2_SDA | MCU_I2C2_SDA
11 | PF1 ** | I/O | I2C2_SCL | MCU_I2C2_SCL
12 | PF2 * | I/O | GPIO_Analog
13 | PF3 ** | I/O | ADC3_IN6 | ADC3_IN6_20MHZ_PULL
16 | VSS | Power
17 | VDD | Power
18 | PF6 ** | I/O | TIM5_CH1 | MCU_IN_TIMCAP_N
19 | PF7 ** | I/O | TIM5_CH2 | MCU_IN_TIMCAP_W
20 | PF8 ** | I/O | TIM5_CH3 | MCU_IN_TIMCAP_S
21 | PF9 ** | I/O | TIM5_CH4 | MCU_IN_TIMCAP_VSOL
22 | PF10 * | I/O | GPIO_Analog
23 | PH0-OSC_IN (PH0) ** | I/O | RCC_OSC_IN | MCU_HSE
25 | NRST | Reset
26 | PC0 * | I/O | GPIO_Analog
27 | PC1 * | I/O | GPIO_Analog
28 | PC2 * | I/O | GPIO_Analog
29 | PC3 * | I/O | GPIO_Analog
30 | VSSA | Power
31 | VREF- | Power
32 | VREF+ | MonoIO | VREFBUF_OUT | MCU_OUT_VREF+
33 | VDDA | Power
34 | PA0 ** | I/O | USART2_CTS | UART2_CTS_IN
36 | PA2 ** | I/O | USART2_TX | UART2_TX_OUT
37 | PA3 ** | I/O | ADC2_IN8, ADC1_IN8 | MCU_VSOL_ADC1
38 | VSS | Power
39 | VDD | Power
42 | PA6 ** | I/O | USART3_CTS | UART3_CTS_IN
43 | PA7 ** | I/O | TIM3_CH2 | MCU_OUT_PWM_LED_G

Pin Number LQFP144 | Pin Name (function after reset) | Pin Type | Alternate Function(s) | Label
44 | PC4 ** | I/O | USART3_TX | UART3_TX_OUT
45 | PC5 ** | I/O | USART3_RX | UART3_RX_IN
46 | PB0 ** | I/O | TIM3_CH3 | MCU_OUT_PWM_LED_B
47 | PB1 ** | I/O | USART3_RTS | UART3_RTS_OUT
50 | PF12 * | I/O | GPIO_Analog
51 | VSS | Power
52 | VDD | Power
54 | PF14 ** | I/O | I2C4_SCL | MCU_I2C4_SCL
56 | PG0 * | I/O | GPIO_Analog
57 | PG1 * | I/O | GPIO_Analog
58 | PE7 * | I/O | GPIO_Analog
59 | PE8 ** | I/O | SAI1_SCK_B | I2S1B_SCK_OUT
60 | PE9 ** | I/O | SAI1_FS_B | I2S1B_FS_OUT
61 | VSS | Power
62 | VDD | Power
63 | PE10 ** | I/O | SAI1_MCLK_B | I2S1B_MCLK_OUT
64 | PE11 * | I/O | GPIO_Analog
65 | PE12 * | I/O | GPIO_Analog
66 | PE13 ** | I/O | SPI1_SCK | MCU_SPI1_SCK
67 | PE14 ** | I/O | SPI1_MISO | MCU_SPI1_MISO
68 | PE15 ** | I/O | SPI1_MOSI | MCU_SPI1_MOSI
69 | PB10 * | I/O | GPIO_Analog
70 | VDD12 | Power
71 | VSS | Power
72 | VDD | Power
73 | PB12 * | I/O | GPIO_Analog
74 | PB13 ** | I/O | SAI2_SCK_A | I2S2A_SCK_IN
75 | PB14 * | I/O | GPIO_Analog
77 | PD8 * | I/O | GPIO_Analog
78 | PD9 * | I/O | GPIO_Analog
79 | PD10 * | I/O | GPIO_Analog
80 | PD11 ** | I/O | SAI2_SD_A | I2S2A_SD_IN
81 | PD12 ** | I/O | SAI2_FS_A | I2S2A_FS_IN
82 | PD13 ** | I/O | I2C4_SDA | MCU_I2C4_SDA
83 | VSS | Power
84 | VDD | Power
85 | PD14 * | I/O | GPIO_Analog
86 | PD15 * | I/O | GPIO_Analog
87 | PG2 * | I/O | GPIO_Analog

Pin Number LQFP144 | Pin Name (function after reset) | Pin Type | Alternate Function(s) | Label
88 | PG3 * | I/O | GPIO_Analog
89 | PG4 * | I/O | GPIO_Analog
92 | PG7 ** | I/O | I2C3_SCL | MCU_I2C3_SCL
93 | PG8 ** | I/O | I2C3_SDA | MCU_I2C3_SDA
94 | VSS | Power
95 | VDDIO2 | Power
96 | PC6 ** | I/O | TIM3_CH1 | MCU_OUT_PWM_LED_R
98 | PC8 * | I/O | GPIO_Analog
99 | PC9 * | I/O | GPIO_Analog
100 | PA8 ** | I/O | RCC_MCO | MCU_MCO
101 | PA9 ** | I/O | USB_OTG_FS_VBUS | MCU_IN_VBUS
103 | PA11 ** | I/O | USB_OTG_FS_DM | PA_USB_N
104 | PA12 ** | I/O | USB_OTG_FS_DP | PA_USB_P
105 | PA13 (JTMS/SWDIO) * | I/O | GPIO_Analog
106 | VDDUSB | Power
107 | VSS | Power
108 | VDD | Power
109 | PA14 (JTCK/SWCLK) ** | I/O | SYS_JTCK-SWCLK | MCU_IN_SWCLK
111 | PC10 ** | I/O | SPI3_SCK | MCU_SPI3_SCK
112 | PC11 ** | I/O | SPI3_MISO | MCU_SPI3_MISO
113 | PC12 ** | I/O | SPI3_MOSI | MCU_SPI3_MOSI
114 | PD0 * | I/O | GPIO_Analog
115 | PD1 * | I/O | GPIO_Analog
116 | PD2 * | I/O | GPIO_Analog
117 | PD3 * | I/O | GPIO_Analog
118 | PD4 ** | I/O | USART2_RTS | UART2_RTS_OUT
119 | PD5 * | I/O | GPIO_Analog
120 | VSS | Power
121 | VDD | Power
122 | PD6 ** | I/O | USART2_RX | UART2_RX_IN
123 | PD7 * | I/O | GPIO_Analog
124 | PG9 ** | I/O | USART1_TX | UART1_TX_OUT
125 | PG10 ** | I/O | USART1_RX | UART1_RX_IN
126 | PG11 ** | I/O | USART1_CTS | UART1_CTS_IN
127 | PG12 ** | I/O | USART1_RTS | UART1_RTS_OUT
128 | PG13 ** | I/O | I2C1_SDA | MCU_I2C1_SDA
129 | PG14 ** | I/O | I2C1_SCL | MCU_I2C1_SCL
130 | VSS | Power
131 | VDDIO2 | Power

Pin Number LQFP144 | Pin Name (function after reset) | Pin Type | Alternate Function(s) | Label
132 | PB3 (JTDO/TRACESWO) * | I/O | GPIO_Analog
134 | PB5 * | I/O | GPIO_Analog
135 | PB6 * | I/O | GPIO_Analog
136 | PB7 * | I/O | GPIO_Analog
140 | PE0 * | I/O | GPIO_Analog
142 | VDD12 | Power
143 | VSS | Power
144 | VDD | Power

## * The pin is affected with an I/O function ** The pin is affected with a peripheral function but no peripheral mode is activated

# 4. Clock Tree Configuration

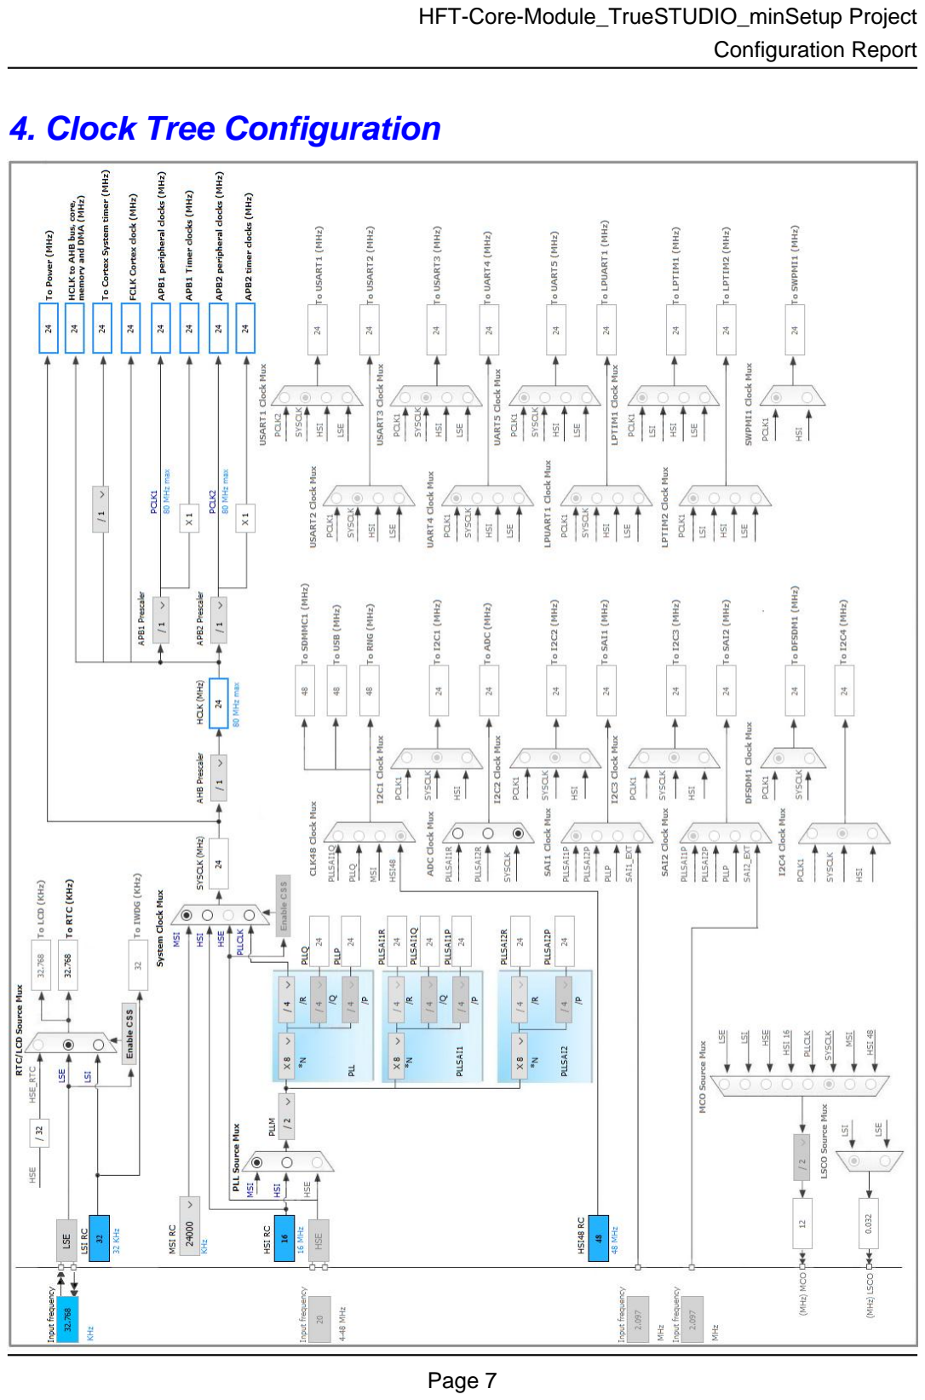
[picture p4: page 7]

# 5. IPs and Middleware Configuration

# 5.1. RCC

## Low Speed Clock (LSE) : Crystal/Ceramic Resonator 5.1.1. Parameter Settings:

### System Parameters:

VDD voltage (V) | 3.3
Instruction Cache | Enabled
Prefetch Buffer | Enabled *
Data Cache | Enabled
Flash Latency(WS) | 3 WS (4 CPU cycle)

### RCC Parameters:

HSI Calibration Value | 64
MSI Calibration Value | 0
MSI Auto Calibration | Disabled
HSE Startup Timout Value (ms) | 100
LSE Startup Timout Value (ms) | 5000
LSE Drive Capability | LSE oscillator low drive capability

### Power Parameters:

Power Regulator Voltage Scale | Power Regulator Voltage Scale 2 *

# 5.2. RTC

## mode: Activate Clock Source mode: Activate Calendar Alarm A: Internal Alarm A Alarm B: Internal Alarm B WakeUp: Internal WakeUp 5.2.1. Parameter Settings:

### General:

Hour Format | Hourformat 24
Asynchronous Predivider value | 31 *
Synchronous Predivider value | 1023 *

### Calendar Time:

Data Format | BCD data format
Hours | 0

Minutes | 0
Seconds | 0
Day Light Saving: value of hour adjustment | Daylightsaving None
Store Operation | Storeoperation Reset

### Calendar Date:

Week Day | Monday
Month | January
Date | 1
Year | 0

### Alarm A:

Hours | 0
Minutes | 0
Seconds | 0
Sub Seconds | 0
Alarm Mask Date Week day | Disable
Alarm Mask Hours | Disable
Alarm Mask Minutes | Disable
Alarm Mask Seconds | Disable
Alarm Sub Second Mask | All Alarm SS fields are masked.
Alarm Date Week Day Sel | Date
Alarm Date | 1

### Alarm B:

Hours | 0
Minutes | 0
Seconds | 0
Sub Seconds | 0
Alarm Mask Date Week day | Disable
Alarm Mask Hours | Disable
Alarm Mask Minutes | Disable
Alarm Mask Seconds | Disable
Alarm Sub Second Mask | All Alarm SS fields are masked.
Alarm Date Week Day Sel | Date
Alarm Date | 1

### Wake UP:

Wake Up Clock | RTCCLK / 16
Wake Up Counter | 0

# 5.3. SYS

## Power Voltage Detector In: Power Voltage Detector In (Internal analog voltage)

## VREFBUF Mode: Internal voltage reference Timebase Source: TIM2 5.3.1. Parameter Settings:

### Programmable_Voltage_Detector_Settings:

PVD detection Level | PWR PVD LEVEL 5 (2.8 V) *
PWR PVD Mode | basic mode is used

### Voltage_Reference_Buffer_Settings:

Trimming Mode | User Trimming *
Trimming Value | 5 *
Internal Voltage reference scale | SCALE 0: around 2.048 V

# 5.4. FREERTOS

## mode: Enabled 5.4.1. Config parameters:

### Versions:

FreeRTOS version | 9.0.0
CMSIS-RTOS version | 1.02

### Kernel settings:

USE_PREEMPTION | Enabled
CPU_CLOCK_HZ | SystemCoreClock
TICK_RATE_HZ | 1000
MAX_PRIORITIES | 7
MINIMAL_STACK_SIZE | 128
MAX_TASK_NAME_LEN | 32 *
USE_16_BIT_TICKS | Disabled
IDLE_SHOULD_YIELD | Enabled
USE_MUTEXES | Enabled
USE_RECURSIVE_MUTEXES | Disabled
USE_COUNTING_SEMAPHORES | Enabled *
QUEUE_REGISTRY_SIZE | 64 *
USE_APPLICATION_TASK_TAG | Enabled *
ENABLE_BACKWARD_COMPATIBILITY | Disabled *
USE_PORT_OPTIMISED_TASK_SELECTION | Enabled
USE_TICKLESS_IDLE | Disabled
USE_TASK_NOTIFICATIONS | Enabled

### Memory management settings:

Memory Allocation | Dynamic
TOTAL_HEAP_SIZE | 0x8000 *
Memory Management scheme | heap_4

### Hook function related definitions:

USE_IDLE_HOOK | Enabled *
USE_TICK_HOOK | Disabled
USE_MALLOC_FAILED_HOOK | Enabled *
USE_DAEMON_TASK_STARTUP_HOOK | Disabled
CHECK_FOR_STACK_OVERFLOW | Option1 *

### Run time and task stats gathering related definitions:

GENERATE_RUN_TIME_STATS | Enabled *
USE_TRACE_FACILITY | Enabled *
USE_STATS_FORMATTING_FUNCTIONS | Enabled *

### Co-routine related definitions:

USE_CO_ROUTINES | Disabled
MAX_CO_ROUTINE_PRIORITIES | 2

### Software timer definitions:

USE_TIMERS | Enabled
TIMER_TASK_PRIORITY | 2
TIMER_QUEUE_LENGTH | 16 *
TIMER_TASK_STACK_DEPTH | 256

### Interrupt nesting behaviour configuration:

LIBRARY_LOWEST_INTERRUPT_PRIORITY | 15
LIBRARY_MAX_SYSCALL_INTERRUPT_PRIORITY | 5

## 5.4.2. Include parameters:

### Include definitions:

vTaskPrioritySet | Enabled
uxTaskPriorityGet | Enabled
vTaskDelete | Disabled *
vTaskCleanUpResources | Disabled
vTaskSuspend | Enabled
vTaskDelayUntil | Enabled *
vTaskDelay | Enabled
xTaskGetSchedulerState | Enabled
xTaskResumeFromISR | Enabled
xQueueGetMutexHolder | Enabled *

xSemaphoreGetMutexHolder | Enabled *
pcTaskGetTaskName | Enabled *
uxTaskGetStackHighWaterMark | Enabled *
xTaskGetCurrentTaskHandle | Enabled *
eTaskGetState | Enabled *
xEventGroupSetBitFromISR | Enabled *
xTimerPendFunctionCall | Enabled *
xTaskAbortDelay | Disabled
xTaskGetHandle | Enabled *

### * User modified value

# 6. System Configuration

# 6.1. GPIO configuration

IP | Pin | Signal | GPIO mode | GPIO pull/up pull down

## Max Speed

## User Label

RCC | PC14-
OSC32_IN
(PC14)
RCC_OSC32_IN | n/a | n/a | n/a | MCU_OSC32_IN

PC15-
OSC32_OU
T (PC15)

RCC_OSC32_O
UT
n/a | n/a | n/a | MCU_OSC32_OUT
SYS | VREF+ | VREFBUF_OUT | n/a | n/a | n/a | MCU_OUT_VREF+
Single Mapped Signals | PC13 | SYS_WKUP2 | n/a | n/a | n/a | MCU_IN_WAKEUP
| PF0 | I2C2_SDA | Alternate Function Open Drain | Pull-up | Low | MCU_I2C2_SDA
| PF1 | I2C2_SCL | Alternate Function Open Drain | Pull-up | Low | MCU_I2C2_SCL
| PF3 | ADC3_IN6 | Analog mode for ADC conversion | No pull-up and no pull-down | n/a | ADC3_IN6_20MHZ_PULL
| PF6 | TIM5_CH1 | Alternate Function Push Pull | Pull-down * | Low | MCU_IN_TIMCAP_N
| PF7 | TIM5_CH2 | Alternate Function Push Pull | Pull-down * | Low | MCU_IN_TIMCAP_W
| PF8 | TIM5_CH3 | Alternate Function Push Pull | Pull-down * | Low | MCU_IN_TIMCAP_S
| PF9 | TIM5_CH4 | Alternate Function Push Pull | Pull-down * | Low | MCU_IN_TIMCAP_VSOL
| PH0- OSC_IN (PH0) | RCC_OSC_IN | n/a | n/a | n/a | MCU_HSE
PA0 | USART2_CTS Alternate Function Push Pull | Pull-down * | Low | UART2_CTS_IN
PA2 | USART2_TX | Alternate Function Push Pull | Pull-up * | Low | UART2_TX_OUT
PA3 | ADC2_IN8, ADC1_IN8 | Analog mode for ADC conversion | No pull-up and no pull-down | n/a | MCU_VSOL_ADC1
PA6 | USART3_CTS Alternate Function Push Pull | Pull-down * | Low | UART3_CTS_IN
PA7 | TIM3_CH2 | Alternate Function Push Pull | Pull-down * | Low | MCU_OUT_PWM_LED_G
PC4 | USART3_TX | Alternate Function Push Pull | Pull-up * | Low | UART3_TX_OUT
PC5 | USART3_RX | Alternate Function Push Pull | Pull-up * | Low | UART3_RX_IN
PB0 | TIM3_CH3 | Alternate Function Push Pull | Pull-down * | Low | MCU_OUT_PWM_LED_B
PB1 | USART3_RTS Alternate Function Push Pull | Pull-down * | Low | UART3_RTS_OUT
PF14 | I2C4_SCL | Alternate Function Open Drain | Pull-up | Low | MCU_I2C4_SCL
PE8 | SAI1_SCK_B | Alternate Function Push Pull | Pull-down * | Medium * | I2S1B_SCK_OUT
PE9 | SAI1_FS_B | Alternate Function Push Pull | Pull-down * | Medium * | I2S1B_FS_OUT

IP | Pin | Signal | GPIO mode | GPIO pull/up pull down

## Max Speed

## User Label

PE10 | SAI1_MCLK_B Alternate Function Push Pull | Pull-down * | Medium * | I2S1B_MCLK_OUT
PE13 | SPI1_SCK | Alternate Function Push Pull | Pull-down * | Very High
*
| | | | | MCU_SPI1_SCK
PE14 | SPI1_MISO | Alternate Function Push Pull | Pull-down * | Very High
*
| | | | | MCU_SPI1_MISO
PE15 | SPI1_MOSI | Alternate Function Push Pull | Pull-down * | Very High
*
| | | | | MCU_SPI1_MOSI
PB13 | SAI2_SCK_A | Alternate Function Push Pull | Pull-down * | Medium * | I2S2A_SCK_IN
PD11 | SAI2_SD_A | Alternate Function Push Pull | Pull-down * | Medium * | I2S2A_SD_IN
PD12 | SAI2_FS_A | Alternate Function Push Pull | Pull-down * | Medium * | I2S2A_FS_IN
PD13 | I2C4_SDA | Alternate Function Open Drain | Pull-up | Low | MCU_I2C4_SDA
PG7 | I2C3_SCL | Alternate Function Open Drain | Pull-up | Low | MCU_I2C3_SCL
PG8 | I2C3_SDA | Alternate Function Open Drain | Pull-up | Low | MCU_I2C3_SDA
PC6 | TIM3_CH1 | Alternate Function Push Pull | Pull-down * | Low | MCU_OUT_PWM_LED_R
PA8 | RCC_MCO | Alternate Function Push Pull | Pull-down * | Low | MCU_MCO
PA9 | USB_OTG_FS_ VBUS | n/a | n/a | n/a | MCU_IN_VBUS
PA11 | USB_OTG_FS_ DM | Alternate Function Push Pull | Pull-down * | High * | PA_USB_N
PA12 | USB_OTG_FS_ DP | Alternate Function Push Pull | Pull-down * | High * | PA_USB_P
PA14 (JTCK/SWC LK) | SYS_JTCK- SWCLK | n/a | n/a | n/a | MCU_IN_SWCLK
PC10 | SPI3_SCK | Alternate Function Push Pull | Pull-down * | Very High
*
| | | | | MCU_SPI3_SCK
PC11 | SPI3_MISO | Alternate Function Push Pull | Pull-down * | Very High
*
| | | | | MCU_SPI3_MISO
PC12 | SPI3_MOSI | Alternate Function Push Pull | Pull-down * | Very High
*
| | | | | MCU_SPI3_MOSI
PD4 | USART2_RTS Alternate Function Push Pull | Pull-down * | Low | UART2_RTS_OUT
PD6 | USART2_RX | Alternate Function Push Pull | Pull-up * | Low | UART2_RX_IN
PG9 | USART1_TX | Alternate Function Push Pull | Pull-up * | Low | UART1_TX_OUT
PG10 | USART1_RX | Alternate Function Push Pull | Pull-up * | Low | UART1_RX_IN
PG11 | USART1_CTS Alternate Function Push Pull | Pull-down * | Low | UART1_CTS_IN
PG12 | USART1_RTS | Alternate Function Push Pull | | Low | UART1_RTS_OUT

IP | Pin | Signal | GPIO mode | GPIO pull/up pull

## down

## Max Speed

## User Label

### Pull-down *

| PG13 | I2C1_SDA | Alternate Function Open Drain
Pull-up | Low | MCU_I2C1_SDA
| PG14 | I2C1_SCL | Alternate Function Open Drain
Pull-up | Low | MCU_I2C1_SCL
GPIO | PE2 | GPIO_Analog | Analog mode | No pull-up and no pull-down | n/a
| PE3 | GPIO_Analog | Analog mode | No pull-up and no pull-down | n/a
| PE4 | GPIO_Analog | Analog mode | No pull-up and no pull-down | n/a
| PE5 | GPIO_Analog | Analog mode | No pull-up and no pull-down | n/a
| PF2 | GPIO_Analog | Analog mode | No pull-up and no pull-down | n/a
| PF10 | GPIO_Analog | Analog mode | No pull-up and no pull-down | n/a
| PC0 | GPIO_Analog | Analog mode | No pull-up and no pull-down | n/a
| PC1 | GPIO_Analog | Analog mode | No pull-up and no pull-down | n/a
| PC2 | GPIO_Analog | Analog mode | No pull-up and no pull-down | n/a
| PC3 | GPIO_Analog | Analog mode | No pull-up and no pull-down | n/a
| PF12 | GPIO_Analog | Analog mode | No pull-up and no pull-down | n/a
| PG0 | GPIO_Analog | Analog mode | No pull-up and no pull-down | n/a
| PG1 | GPIO_Analog | Analog mode | No pull-up and no pull-down | n/a
| PE7 | GPIO_Analog | Analog mode | No pull-up and no pull-down | n/a
| PE11 | GPIO_Analog | Analog mode | No pull-up and no pull-down | n/a
| PE12 | GPIO_Analog | Analog mode | No pull-up and no pull-down | n/a
| PB10 | GPIO_Analog | Analog mode | No pull-up and no pull-down | n/a
| PB12 | GPIO_Analog | Analog mode | No pull-up and no pull-down | n/a
| PB14 | GPIO_Analog | Analog mode | No pull-up and no pull-down | n/a
| PD8 | GPIO_Analog | Analog mode | No pull-up and no pull-down | n/a
| PD9 | GPIO_Analog | Analog mode | No pull-up and no pull-down | n/a
| PD10 | GPIO_Analog | Analog mode | No pull-up and no pull-down | n/a
| PD14 | GPIO_Analog | Analog mode | No pull-up and no pull-down | n/a
| PD15 | GPIO_Analog | Analog mode | No pull-up and no pull-down | n/a
| PG2 | GPIO_Analog | Analog mode | No pull-up and no pull-down | n/a
| PG3 | GPIO_Analog | Analog mode | No pull-up and no pull-down | n/a
| PG4 | GPIO_Analog | Analog mode | No pull-up and no pull-down | n/a
| PC8 | GPIO_Analog | Analog mode | No pull-up and no pull-down | n/a
| PC9 | GPIO_Analog | Analog mode | No pull-up and no pull-down | n/a
| PA13 (JTMS/SWDI O) | GPIO_Analog | Analog mode | No pull-up and no pull-down | n/a
PD0 | GPIO_Analog | Analog mode | No pull-up and no pull-down | n/a
PD1 | GPIO_Analog | Analog mode | No pull-up and no pull-down | n/a
PD2 | GPIO_Analog | Analog mode | No pull-up and no pull-down | n/a
PD3 | GPIO_Analog | Analog mode | No pull-up and no pull-down | n/a

IP | Pin | Signal | GPIO mode | GPIO pull/up pull down | Max Speed | User Label
| PD5 | GPIO_Analog | Analog mode | No pull-up and no pull-down | n/a
| PD7 | GPIO_Analog | Analog mode | No pull-up and no pull-down | n/a
| PB3 (JTDO/TRA CESWO) | GPIO_Analog | Analog mode | No pull-up and no pull-down | n/a
| PB5 | GPIO_Analog | Analog mode | No pull-up and no pull-down | n/a
| PB6 | GPIO_Analog | Analog mode | No pull-up and no pull-down | n/a
| PB7 | GPIO_Analog | Analog mode | No pull-up and no pull-down | n/a
| PE0 | GPIO_Analog | Analog mode | No pull-up and no pull-down | n/a

# 6.2. DMA configuration

## nothing configured in DMA service

# 6.3. NVIC configuration

Interrupt Table | Enable | Preenmption Priority | SubPriority
Non maskable interrupt | true | 0 | 0
Hard fault interrupt | true | 0 | 0
Memory management fault | true | 0 | 0
Prefetch fault, memory access fault | true | 0 | 0
Undefined instruction or illegal state | true | 0 | 0
System service call via SWI instruction | true | 0 | 0
Debug monitor | true | 0 | 0
Pendable request for system service | true | 15 | 0
System tick timer | true | 15 | 0
TIM2 global interrupt | true | 0 | 0
PVD/PVM1/PVM2/PVM3/PVM4 interrupts through EXTI lines 16/35/36/37/38 | unused
RTC wake-up interrupt through EXTI line 20 | unused
Flash global interrupt | unused
RCC global interrupt | unused
RTC alarm interrupt through EXTI line 18 | unused
FPU global interrupt | unused

### * User modified value

# 7. Power Consumption Calculator report

### 7.1. Microcontroller Selection

Series | STM32L4
Line | STM32L4x6
MCU | STM32L496ZGTxP
Datasheet | 029173_Rev2

### 7.2. Parameter Selection

Temperature | 25
Vdd | 3.6

### 7.3. SMPS Selection

SMPS | SMPS1_User
Vin | 3.3 V
Vout | 1.2 V
OffCurrent | 250.0 nA
QCurrent | 500.0 nA
Efficiency | 85 %

## 7.4. Sequence

Step | Step1 | Step2

Mode | RUN | SLEEP
SMPS | CONNECTED | CONNECTED
Vdd | 3.6 | 3.6
Voltage Source | Battery | Battery
Range | Range2-Medium | Range2-Medium
Fetch Type | FLASH | FLASH
Clock Configuration | HSE BYP ART Flash-ON | HSE BYP ART Flash-ON
Clock Source Frequency | 24 MHz | 24 MHz
CPU Frequency | 24 MHz | 24 MHz
Peripherals | ADC1:fs_10_ksps ADC3:fs_10_ksps CRC DFSDM1 GPIOA GPIOB GPIOC GPIOD GPIOE GPIOF GPIOG GPIOH I2C1 I2C2 I2C3 I2C4 RNG RTC SAI1 SAI2 SPI1 SPI3 SYS-VREFBUF/COMP1:COMP_H igh_Speed-Square_VREFBUF_OFF TIM3 TIM5 TIM16 TIM17 USART1 USART2 USART3 USB_OTG_FS | ADC1:fs_10_ksps ADC3:fs_10_ksps CRC DFSDM1 GPIOA GPIOB GPIOC GPIOD GPIOE GPIOF GPIOG GPIOH I2C1 I2C2 I2C3 I2C4 RNG RTC SAI1 SAI2 SPI1 SPI3 SYS-VREFBUF/COMP1:COMP_H igh_Speed-Square_VREFBUF_OFF TIM3 TIM5 TIM16 TIM17 USART1 USART2 USART3 USB_OTG_FS
Additional Cons. | 0 mA | 0 mA
Average Current | 2.34 mA | 1.45 mA
Duration | 0.04 ms | 0.96 ms
DMIPS | 0.0 | 0.0
Ta Max | 104.73 | 104.83
Category | Measurements | Measurements

## 7.5. RESULTS

Sequence Time | 1 ms | Average Current | 1.49 mA
Battery Life | 0 | Average DMIPS | 30.0 DMIPS

## 7.6. Chart

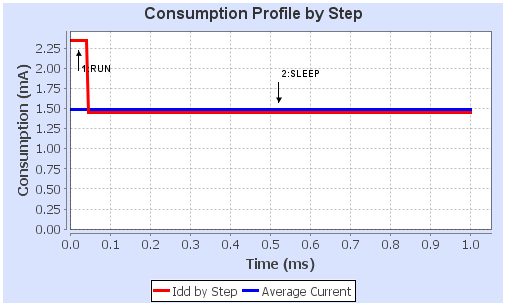
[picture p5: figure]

# 8. Software Project

## 8.1. Project Settings

Name | Value
Project Name | HFT-Core-Module_TrueSTUDIO_minSetup
Project Folder | Z:\nfs_ds_nfs\git\HFT-Core-Module__SW\SW\TrueSTUDIO\HFT-Core-
Toolchain / IDE | TrueSTUDIO
Firmware Package Name and Version | STM32Cube FW_L4 V1.12.0

## 8.2. Code Generation Settings

Name | Value
STM32Cube Firmware Library Package | Copy only the necessary library files
Generate peripheral initialization as a pair of '.c/.h' files | No
Backup previously generated files when re-generating | No
Delete previously generated files when not re-generated | Yes
Set all free pins as analog (to optimize the power consumption) | No

# 9. Software Pack Report

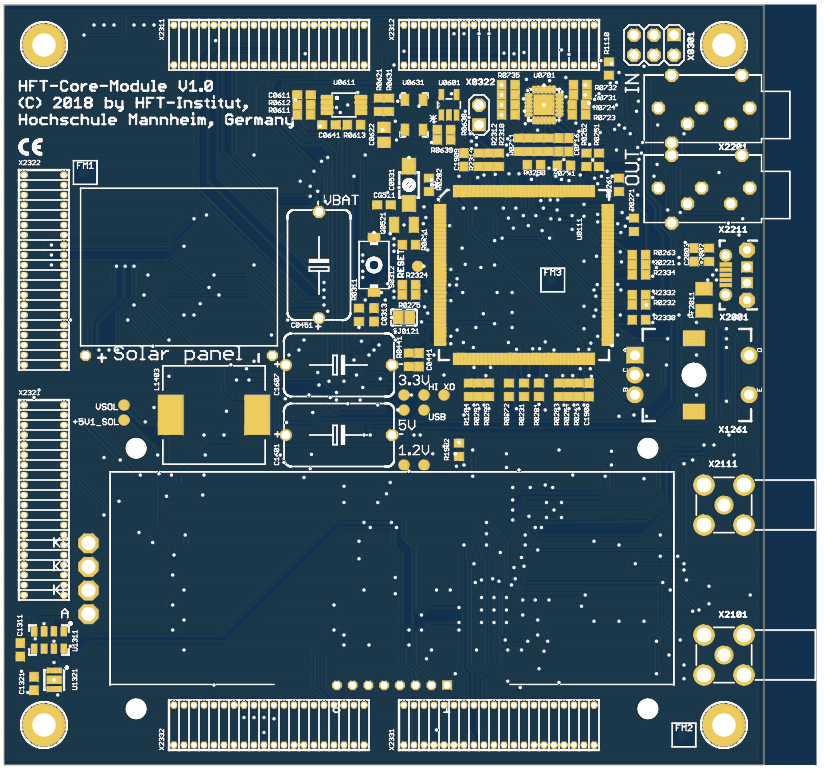
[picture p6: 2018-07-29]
CAD/Eagle/Manufacturing/Pictures/HFT-Core-Module_1V0__Top.png

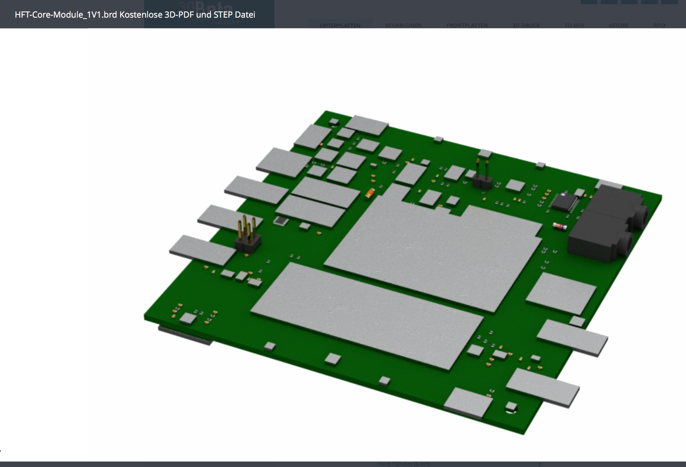
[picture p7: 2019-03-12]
Docs/09_Results/Pictures/1V1_6-Layers_Beta-Layout/5_3D-PDF-STEP.png

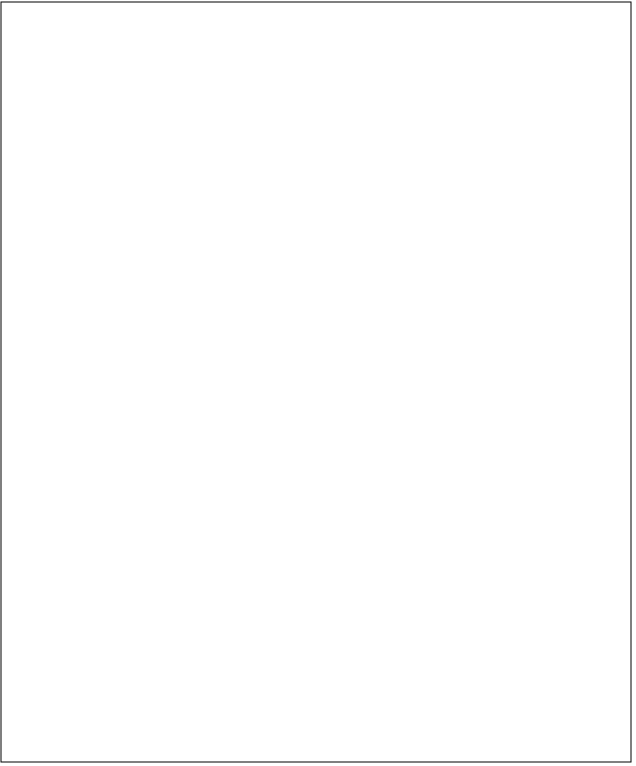
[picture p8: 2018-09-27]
CAD/Eagle/Extensions/Manufacturing/Pictures/HFT-ArduinoShield-Module_1V0___Mill.png

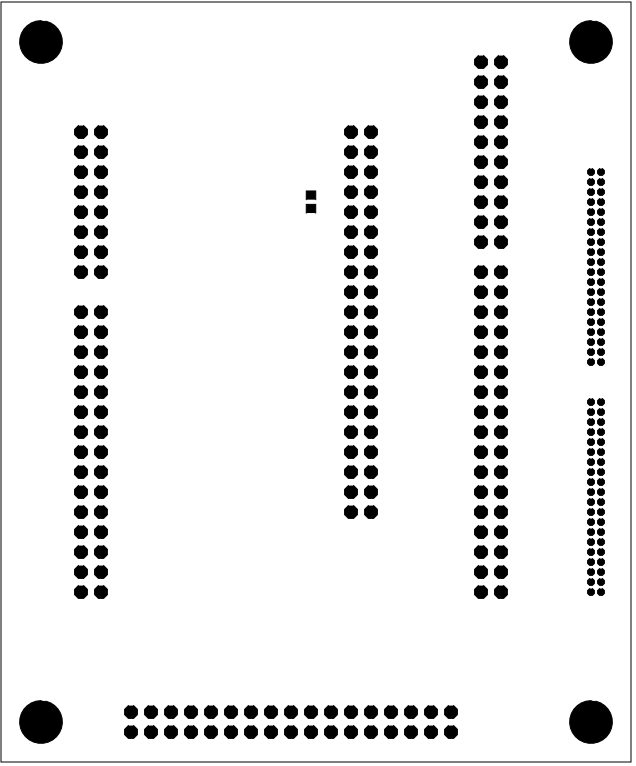
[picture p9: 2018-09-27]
CAD/Eagle/Extensions/Manufacturing/Pictures/HFT-ArduinoShield-Module_1V0__BottomSoldermask.png

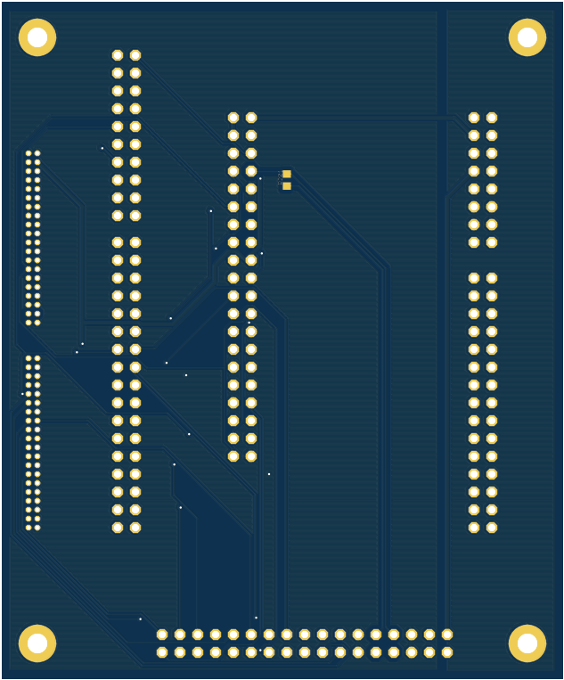
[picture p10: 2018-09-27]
CAD/Eagle/Extensions/Manufacturing/Pictures/HFT-ArduinoShield-Module_1V0__Bottom.png

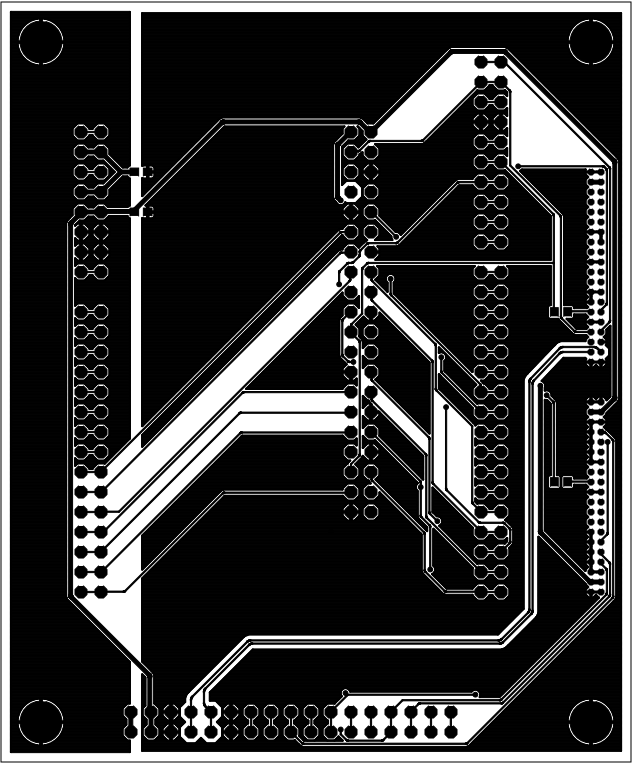
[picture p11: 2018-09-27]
CAD/Eagle/Extensions/Manufacturing/Pictures/HFT-ArduinoShield-Module_1V0__TopCopper.png

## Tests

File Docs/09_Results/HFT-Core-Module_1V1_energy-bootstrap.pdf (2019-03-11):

Von: Ulrich Habel espero7757@gmx.net Betreff: HFT-Core-Module V1.1 - Hochlauf Datum: 12. November 2018 um 23:03
An: Ulrich Habel espero7757@gmx.net

## Bootstrap - check for HFT-Core-Module PCB V1.1

Variant | Energy entry | Bootstrap circuit
1 | Solar 0.3V .. 2V | VSOL, U2601, BQ_VSTOR, U2681, +5V0, BQ_VSTOR, BQ_VOUT,
+3V3.
2 | USB | USB_VBUS, VDDUSB, D2801, (R2801 || R2802), U2801, VUSB_SW,
+5V0, D2681, BQ_VSTOR, BQ_VOUT, +3V3.
3 | 12V in | DC_12V_IN, U2401, POW_IN_5V0, D2521, +5V0, D2681, BQ_VSTOR,
BQ_VOUT, +3V3.
4 | LiPo 3.7V | NO! First set register REG01[5:4] = 10 and PSEL = 1 and OTG = 1 to
enable BOOST mode (OTG). Circuit: LIPO_BAT, U2501, +5V0, D2681, BQ_VSTOR, BQ_VOUT, +3V3.

<EOF>

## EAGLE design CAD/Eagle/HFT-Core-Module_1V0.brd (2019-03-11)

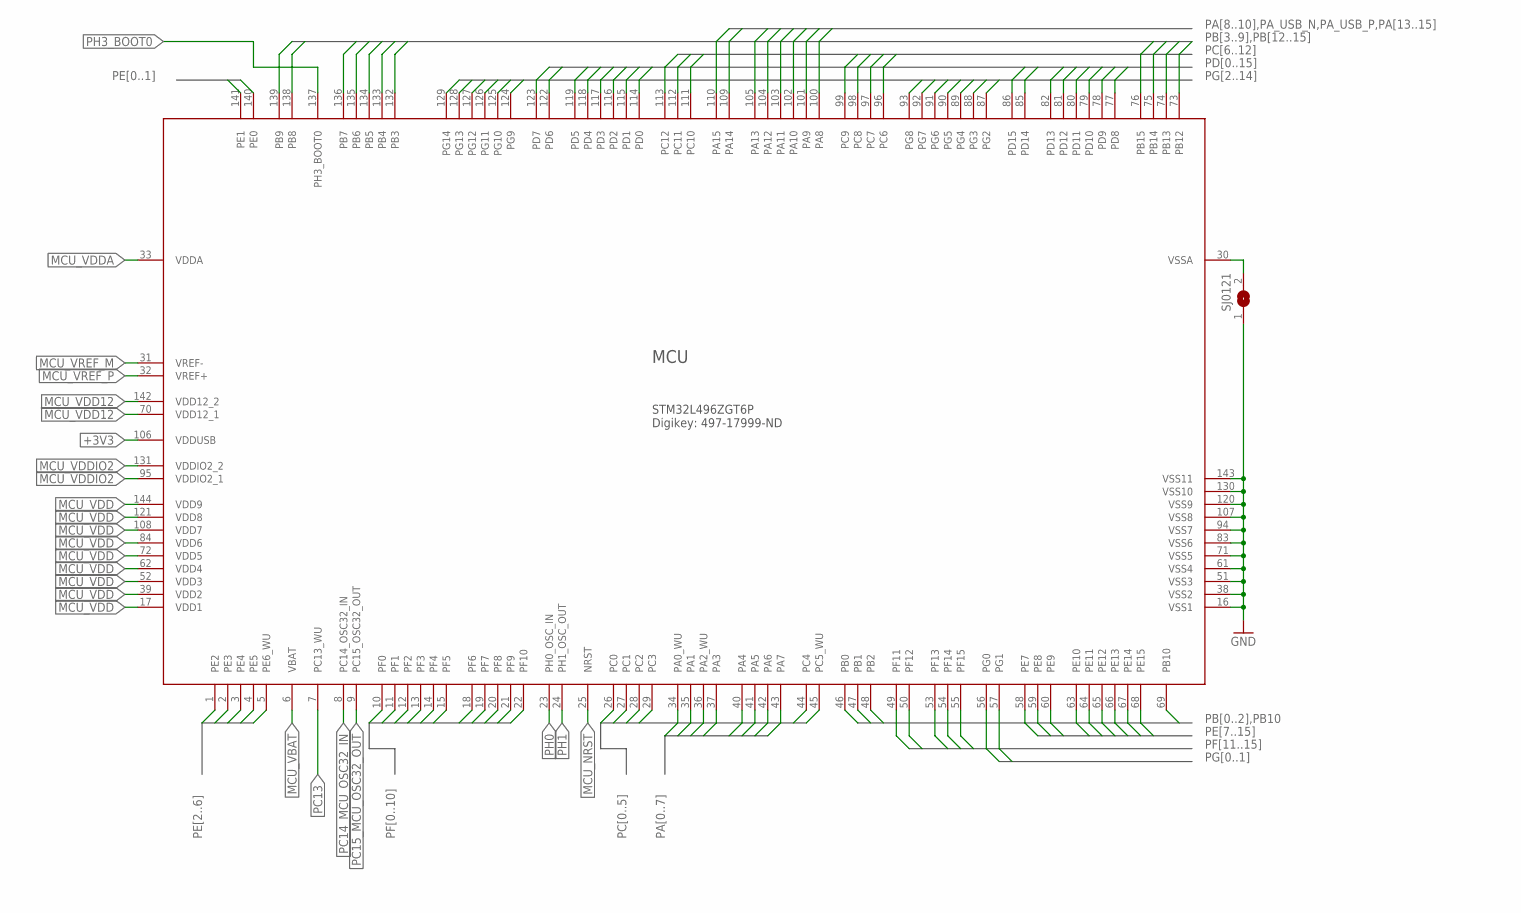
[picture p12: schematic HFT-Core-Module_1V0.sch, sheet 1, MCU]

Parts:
SJ0121: SJ
U0111: STM32L4Z_144PIN_SMPS; LQFP144

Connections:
+3V3: U0111.106 (VDDUSB); also elsewhere on the board
GND: SJ0121.1, U0111.16 (VSS1), U0111.38 (VSS2), U0111.51 (VSS3), U0111.61 (VSS4), U0111.71 (VSS5), U0111.83 (VSS6), U0111.94 (VSS7), U0111.107 (VSS8), U0111.120 (VSS9), U0111.130 (VSS10), U0111.143 (VSS11); also elsewhere on the board
MCU_NRST: U0111.25 (NRST); also elsewhere on the board
MCU_VBAT: U0111.6 (VBAT); also elsewhere on the board
MCU_VDD: U0111.17 (VDD1), U0111.39 (VDD2), U0111.52 (VDD3), U0111.62 (VDD4), U0111.72 (VDD5), U0111.84 (VDD6), U0111.108 (VDD7), U0111.121 (VDD8), U0111.144 (VDD9); also elsewhere on the board
MCU_VDD12: U0111.70 (VDD12_1), U0111.142 (VDD12_2); also elsewhere on the board
MCU_VDDA: U0111.33 (VDDA); also elsewhere on the board
MCU_VDDIO2: U0111.95 (VDDIO2_1), U0111.131 (VDDIO2_2); also elsewhere on the board
MCU_VREF_M: U0111.31 (VREF-); also elsewhere on the board
MCU_VREF_P: U0111.32 (VREF+); also elsewhere on the board
MCU_VSSA: SJ0121.2, U0111.30 (VSSA)
PA0: U0111.34 (PA0_WU); also elsewhere on the board
PA1: U0111.35 (PA1)
PA2: U0111.36 (PA2_WU); also elsewhere on the board
PA3: U0111.37 (PA3); also elsewhere on the board
PA4: U0111.40 (PA4)
PA5: U0111.41 (PA5)
PA6: U0111.42 (PA6); also elsewhere on the board
PA7: U0111.43 (PA7); also elsewhere on the board
PA8: U0111.100 (PA8); also elsewhere on the board
PA9: U0111.101 (PA9); also elsewhere on the board
PA10: U0111.102 (PA10); also elsewhere on the board
PA13: U0111.105 (PA13); also elsewhere on the board
PA14: U0111.109 (PA14); also elsewhere on the board
PA15: U0111.110 (PA15)
PA_USB_N: U0111.103 (PA11); also elsewhere on the board
PA_USB_P: U0111.104 (PA12); also elsewhere on the board
PB0: U0111.46 (PB0); also elsewhere on the board
PB1: U0111.47 (PB1); also elsewhere on the board
PB2: U0111.48 (PB2)
PB3: U0111.132 (PB3); also elsewhere on the board
PB4: U0111.133 (PB4)
PB5: U0111.134 (PB5); also elsewhere on the board
PB6: U0111.135 (PB6); also elsewhere on the board
PB7: U0111.136 (PB7); also elsewhere on the board
PB8: U0111.138 (PB8)
PB9: U0111.139 (PB9)
PB10: U0111.69 (PB10); also elsewhere on the board
PB12: U0111.73 (PB12); also elsewhere on the board
PB13: U0111.74 (PB13); also elsewhere on the board
PB14: U0111.75 (PB14); also elsewhere on the board
PB15: U0111.76 (PB15)
PC0: U0111.26 (PC0); also elsewhere on the board
PC1: U0111.27 (PC1); also elsewhere on the board
PC2: U0111.28 (PC2); also elsewhere on the board
PC3: U0111.29 (PC3); also elsewhere on the board
PC4: U0111.44 (PC4); also elsewhere on the board
PC5: U0111.45 (PC5_WU); also elsewhere on the board
PC6: U0111.96 (PC6); also elsewhere on the board
PC7: U0111.97 (PC7)
PC8: U0111.98 (PC8); also elsewhere on the board
PC9: U0111.99 (PC9); also elsewhere on the board
PC10: U0111.111 (PC10); also elsewhere on the board
PC11: U0111.112 (PC11); also elsewhere on the board
PC12: U0111.113 (PC12); also elsewhere on the board
PC13: U0111.7 (PC13_WU); also elsewhere on the board
PC14_MCU_OSC32_IN: U0111.8 (PC14_OSC32_IN); also elsewhere on the board
PC15_MCU_OSC32_OUT: U0111.9 (PC15_OSC32_OUT); also elsewhere on the board
PD0: U0111.114 (PD0); also elsewhere on the board
PD1: U0111.115 (PD1); also elsewhere on the board
PD2: U0111.116 (PD2); also elsewhere on the board
PD3: U0111.117 (PD3); also elsewhere on the board
PD4: U0111.118 (PD4); also elsewhere on the board
PD5: U0111.119 (PD5); also elsewhere on the board
PD6: U0111.122 (PD6); also elsewhere on the board
PD7: U0111.123 (PD7); also elsewhere on the board
PD8: U0111.77 (PD8); also elsewhere on the board
PD9: U0111.78 (PD9); also elsewhere on the board
PD10: U0111.79 (PD10); also elsewhere on the board
PD11: U0111.80 (PD11); also elsewhere on the board
PD12: U0111.81 (PD12); also elsewhere on the board
PD13: U0111.82 (PD13); also elsewhere on the board
PD14: U0111.85 (PD14); also elsewhere on the board
PD15: U0111.86 (PD15); also elsewhere on the board
PE0: U0111.140 (PE0); also elsewhere on the board
PE1: U0111.141 (PE1)
PE2: U0111.1 (PE2); also elsewhere on the board
PE3: U0111.2 (PE3); also elsewhere on the board
PE4: U0111.3 (PE4); also elsewhere on the board
PE5: U0111.4 (PE5); also elsewhere on the board
PE6: U0111.5 (PE6_WU)
PE7: U0111.58 (PE7); also elsewhere on the board
PE8: U0111.59 (PE8); also elsewhere on the board
PE9: U0111.60 (PE9); also elsewhere on the board
PE10: U0111.63 (PE10); also elsewhere on the board
PE11: U0111.64 (PE11); also elsewhere on the board
PE12: U0111.65 (PE12); also elsewhere on the board
PE13: U0111.66 (PE13); also elsewhere on the board
PE14: U0111.67 (PE14); also elsewhere on the board
PE15: U0111.68 (PE15); also elsewhere on the board
PF0: U0111.10 (PF0); also elsewhere on the board
PF1: U0111.11 (PF1); also elsewhere on the board
PF2: U0111.12 (PF2); also elsewhere on the board
PF3: U0111.13 (PF3); also elsewhere on the board
PF4: U0111.14 (PF4)
PF5: U0111.15 (PF5)
PF6: U0111.18 (PF6); also elsewhere on the board
PF7: U0111.19 (PF7); also elsewhere on the board
PF8: U0111.20 (PF8); also elsewhere on the board
PF9: U0111.21 (PF9); also elsewhere on the board
PF10: U0111.22 (PF10); also elsewhere on the board
PF11: U0111.49 (PF11)
PF12: U0111.50 (PF12); also elsewhere on the board
PF13: U0111.53 (PF13); also elsewhere on the board
PF14: U0111.54 (PF14); also elsewhere on the board
PF15: U0111.55 (PF15)
PG0: U0111.56 (PG0); also elsewhere on the board
PG1: U0111.57 (PG1); also elsewhere on the board
PG2: U0111.87 (PG2); also elsewhere on the board
PG3: U0111.88 (PG3); also elsewhere on the board
PG4: U0111.89 (PG4); also elsewhere on the board
PG5: U0111.90 (PG5)
PG6: U0111.91 (PG6)
PG7: U0111.92 (PG7); also elsewhere on the board
PG8: U0111.93 (PG8); also elsewhere on the board
PG9: U0111.124 (PG9); also elsewhere on the board
PG10: U0111.125 (PG10); also elsewhere on the board
PG11: U0111.126 (PG11); also elsewhere on the board
PG12: U0111.127 (PG12); also elsewhere on the board
PG13: U0111.128 (PG13); also elsewhere on the board
PG14: U0111.129 (PG14); also elsewhere on the board
PH0: U0111.23 (PH0_OSC_IN); also elsewhere on the board
PH1: U0111.24 (PH1_OSC_OUT)
PH3_BOOT0: U0111.137 (PH3_BOOT0); also elsewhere on the board

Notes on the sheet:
STM32L496ZGT6P Digikey: 497-17999-ND
MCU

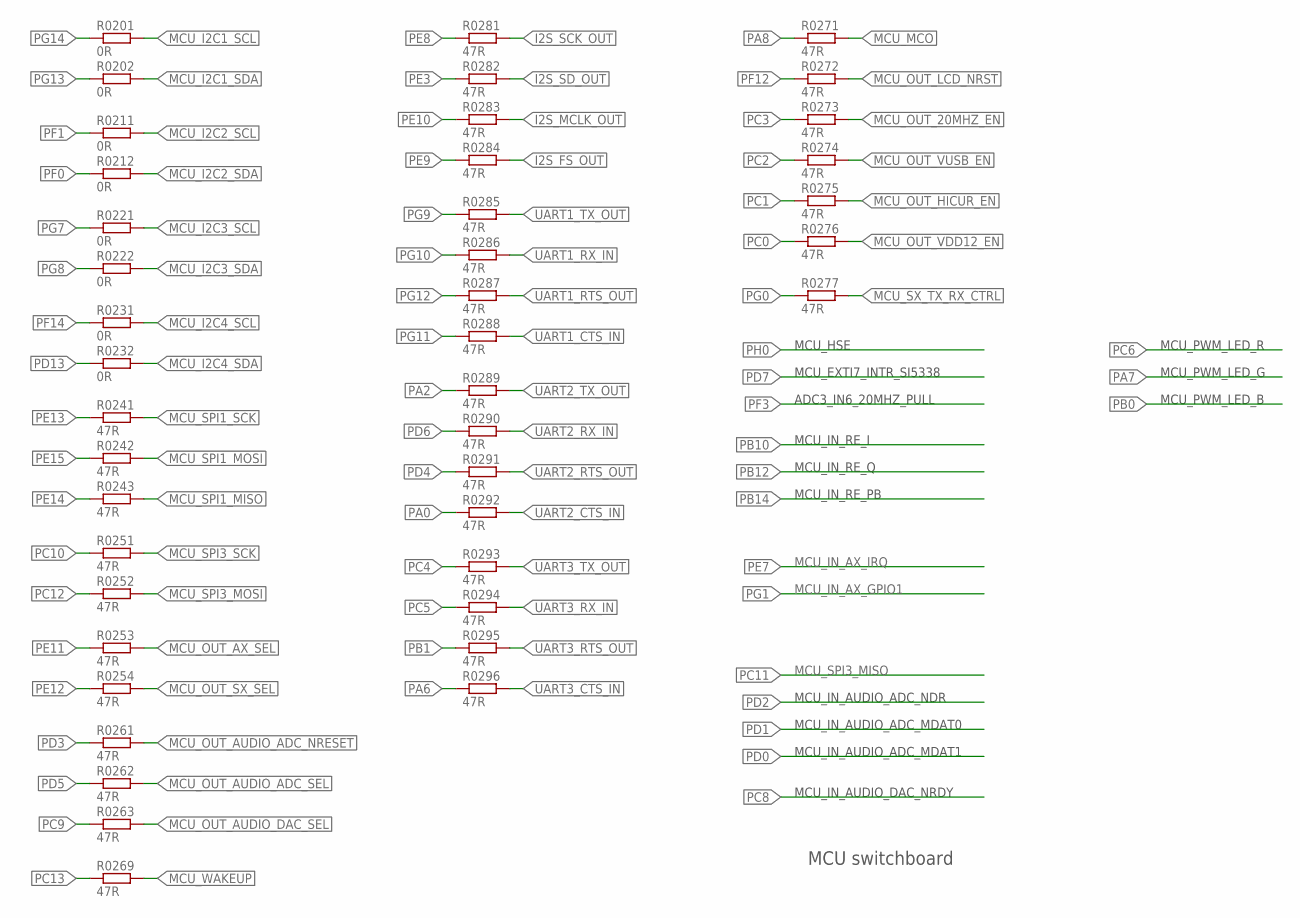
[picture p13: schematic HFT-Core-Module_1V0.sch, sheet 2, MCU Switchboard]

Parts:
R0201, R0202, R0211, R0212, R0221, R0222, R0231, R0232: 0R; R0603
R0241, R0242, R0243, R0251, R0252, R0253, R0254, R0261, R0262, R0263, R0269, R0271, R0272, R0273, R0274, R0275, R0276, R0277, R0281, R0282, R0283, R0284, R0285, R0286, R0287, R0288, R0289, R0290, R0291, R0292, R0293, R0294, R0295, R0296: 47R; R0603

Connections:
I2S_FS_OUT: R0284.2; also elsewhere on the board
I2S_MCLK_OUT: R0283.2; also elsewhere on the board
I2S_SCK_OUT: R0281.2; also elsewhere on the board
I2S_SD_OUT: R0282.2; also elsewhere on the board
MCU_I2C1_SCL: R0201.2; also elsewhere on the board
MCU_I2C1_SDA: R0202.2; also elsewhere on the board
MCU_I2C2_SCL: R0211.2; also elsewhere on the board
MCU_I2C2_SDA: R0212.2; also elsewhere on the board
MCU_I2C3_SCL: R0221.2; also elsewhere on the board
MCU_I2C3_SDA: R0222.2; also elsewhere on the board
MCU_I2C4_SCL: R0231.2; also elsewhere on the board
MCU_I2C4_SDA: R0232.2; also elsewhere on the board
MCU_MCO: R0271.2; also elsewhere on the board
MCU_OUT_20MHZ_EN: R0273.2; also elsewhere on the board
MCU_OUT_AUDIO_ADC_NRESET: R0261.2; also elsewhere on the board
MCU_OUT_AUDIO_ADC_SEL: R0262.2; also elsewhere on the board
MCU_OUT_AUDIO_DAC_SEL: R0263.2; also elsewhere on the board
MCU_OUT_AX_SEL: R0253.2; also elsewhere on the board
MCU_OUT_HICUR_EN: R0275.2; also elsewhere on the board
MCU_OUT_LCD_NRST: R0272.2; also elsewhere on the board
MCU_OUT_SX_SEL: R0254.2; also elsewhere on the board
MCU_OUT_VDD12_EN: R0276.2; also elsewhere on the board
MCU_OUT_VUSB_EN: R0274.2; also elsewhere on the board
MCU_SPI1_MISO: R0243.2; also elsewhere on the board
MCU_SPI1_MOSI: R0242.2; also elsewhere on the board
MCU_SPI1_SCK: R0241.2; also elsewhere on the board
MCU_SPI3_MOSI: R0252.2; also elsewhere on the board
MCU_SPI3_SCK: R0251.2; also elsewhere on the board
MCU_SX_TX_RX_CTRL: R0277.2; also elsewhere on the board
MCU_WAKEUP: R0269.2; also elsewhere on the board
PA0: R0292.1; also elsewhere on the board
PA2: R0289.1; also elsewhere on the board
PA6: R0296.1; also elsewhere on the board
PA8: R0271.1; also elsewhere on the board
PB1: R0295.1; also elsewhere on the board
PC0: R0276.1; also elsewhere on the board
PC1: R0275.1; also elsewhere on the board
PC2: R0274.1; also elsewhere on the board
PC3: R0273.1; also elsewhere on the board
PC4: R0293.1; also elsewhere on the board
PC5: R0294.1; also elsewhere on the board
PC9: R0263.1; also elsewhere on the board
PC10: R0251.1; also elsewhere on the board
PC12: R0252.1; also elsewhere on the board
PC13: R0269.1; also elsewhere on the board
PD3: R0261.1; also elsewhere on the board
PD4: R0291.1; also elsewhere on the board
PD5: R0262.1; also elsewhere on the board
PD6: R0290.1; also elsewhere on the board
PD13: R0232.1; also elsewhere on the board
PE3: R0282.1; also elsewhere on the board
PE8: R0281.1; also elsewhere on the board
PE9: R0284.1; also elsewhere on the board
PE10: R0283.1; also elsewhere on the board
PE11: R0253.1; also elsewhere on the board
PE12: R0254.1; also elsewhere on the board
PE13: R0241.1; also elsewhere on the board
PE14: R0243.1; also elsewhere on the board
PE15: R0242.1; also elsewhere on the board
PF0: R0212.1; also elsewhere on the board
PF1: R0211.1; also elsewhere on the board
PF12: R0272.1; also elsewhere on the board
PF14: R0231.1; also elsewhere on the board
PG0: R0277.1; also elsewhere on the board
PG7: R0221.1; also elsewhere on the board
PG8: R0222.1; also elsewhere on the board
PG9: R0285.1; also elsewhere on the board
PG10: R0286.1; also elsewhere on the board
PG11: R0288.1; also elsewhere on the board
PG12: R0287.1; also elsewhere on the board
PG13: R0202.1; also elsewhere on the board
PG14: R0201.1; also elsewhere on the board
UART1_CTS_IN: R0288.2; also elsewhere on the board
UART1_RTS_OUT: R0287.2; also elsewhere on the board
UART1_RX_IN: R0286.2; also elsewhere on the board
UART1_TX_OUT: R0285.2; also elsewhere on the board
UART2_CTS_IN: R0292.2; also elsewhere on the board
UART2_RTS_OUT: R0291.2; also elsewhere on the board
UART2_RX_IN: R0290.2; also elsewhere on the board
UART2_TX_OUT: R0289.2; also elsewhere on the board
UART3_CTS_IN: R0296.2; also elsewhere on the board
UART3_RTS_OUT: R0295.2; also elsewhere on the board
UART3_RX_IN: R0294.2; also elsewhere on the board
UART3_TX_OUT: R0293.2; also elsewhere on the board

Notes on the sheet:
MCU_SPI3_MISO
MCU_IN_AX_IRQ
MCU_IN_AX_GPIO1
MCU switchboard
MCU_IN_AUDIO_ADC_NDR
MCU_IN_AUDIO_ADC_MDAT0
MCU_IN_AUDIO_ADC_MDAT1
MCU_IN_RE_I
MCU_IN_RE_Q
MCU_IN_RE_PB
ADC3_IN6_20MHZ_PULL
MCU_HSE
MCU_EXTI7_INTR_SI5338
MCU_IN_AUDIO_DAC_NRDY
MCU_PWM_LED_R
MCU_PWM_LED_G
MCU_PWM_LED_B

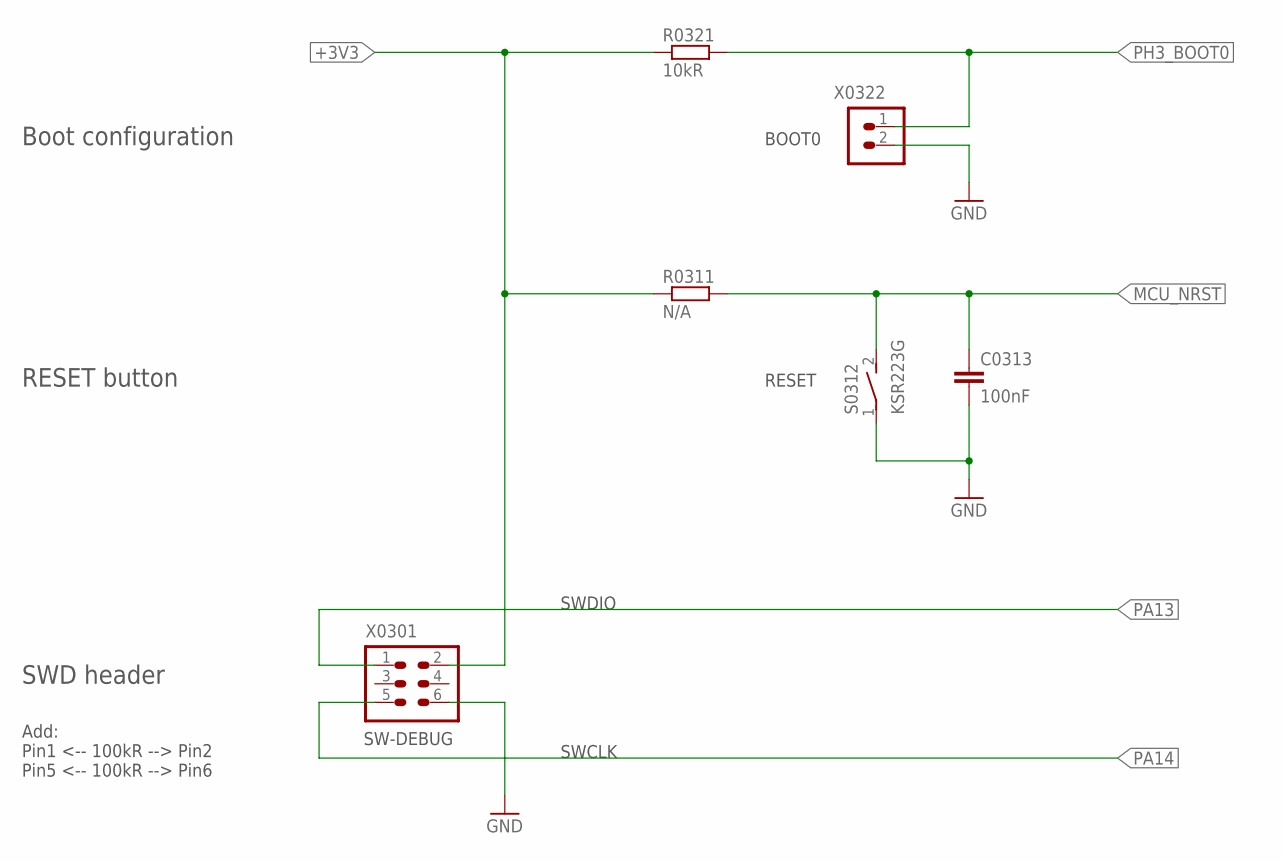
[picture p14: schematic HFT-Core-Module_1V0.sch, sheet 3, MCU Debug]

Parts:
C0313: 100nF; C0603
R0311: N/A; R0603
R0321: 10kR; R0603
S0312: KSR223G; KSR223G_SMD_1POL
X0301: HEADER-2X3; 2X03
X0322: HEADER-1X2; 1X02

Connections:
+3V3: R0311.1, R0321.1, X0301.2; also elsewhere on the board
GND: C0313.2, S0312.1, X0301.6, X0322.2; also elsewhere on the board
MCU_NRST: C0313.1, R0311.2, S0312.2 (S); also elsewhere on the board
PA13: X0301.1; also elsewhere on the board
PA14: X0301.5; also elsewhere on the board
PH3_BOOT0: R0321.2, X0322.1; also elsewhere on the board

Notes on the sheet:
SWDIO
SWCLK
RESET
BOOT0
SW-DEBUG
SWD header
Boot configuration
RESET button
Add: Pin1 <-- 100kR --> Pin2 Pin5 <-- 100kR --> Pin6

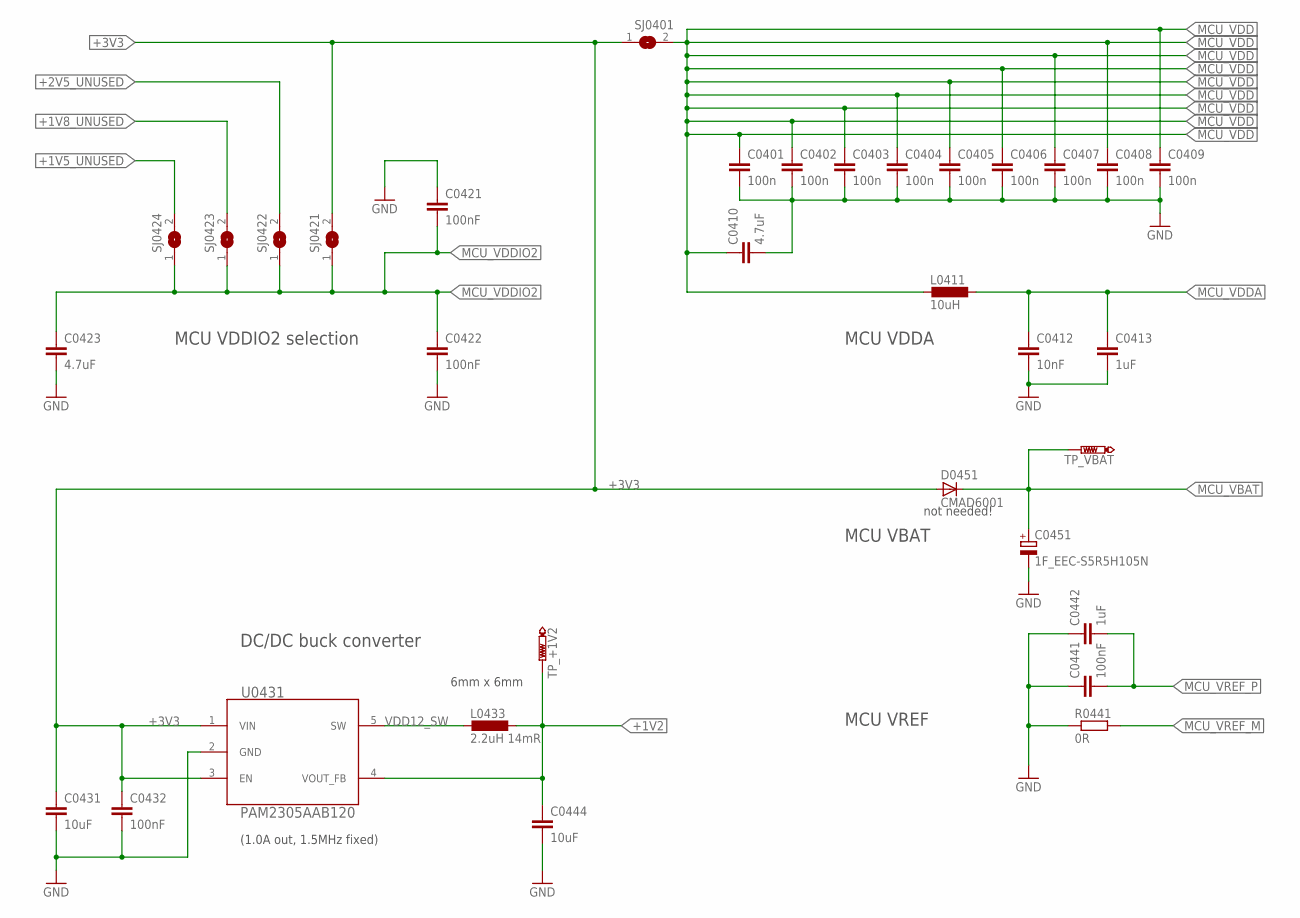
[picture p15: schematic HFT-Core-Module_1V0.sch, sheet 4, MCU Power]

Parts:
C0401, C0402, C0403, C0404, C0405, C0406, C0407, C0408, C0409: 100n; C0603
C0410, C0423: 4.7uF; C0805
C0412: 10nF; C0603
C0413, C0442: 1uF; C0805
C0421, C0422, C0432, C0441: 100nF; C0603
C0431, C0444: 10uF; C0805
C0451: 1F_EEC-S5R5H105N; W14MM_D8MM_P13MM5
D0451: CMAD6001; SOD923
L0411: 10uH; L2012C
L0433: 2.2uH 14mR; L_6X6MM
R0441: 0R; R0603
SJ0401, SJ0421, SJ0422, SJ0423, SJ0424: SJ
TP_+1V2: PTR1B1,27; B1,27
TP_VBAT: PTR1B1,27; B1,27
U0431: PAM2305AAB120; SOT95P280X145-5N

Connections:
+1V2: C0444.1, L0433.1, TP_+1V2.TP, U0431.4 (VOUT_FB); also elsewhere on the board
+1V5_UNUSED: SJ0424.2
+1V8_UNUSED: SJ0423.2
+2V5_UNUSED: SJ0422.2
+3V3: C0431.1, C0432.1, D0451.A, SJ0401.1, SJ0421.2, U0431.1 (VIN), U0431.3 (EN); also elsewhere on the board
GND: C0401.2, C0402.2, C0403.2, C0404.2, C0405.2, C0406.2, C0407.2, C0408.2, C0409.2, C0410.2, C0412.2, C0413.2, C0421.1, C0422.2, C0423.2, C0431.2, C0432.2, C0441.1, C0442.1, C0444.2, C0451.-, R0441.1, U0431.2 (GND); also elsewhere on the board
MCU_VBAT: C0451.+, D0451.C, TP_VBAT.TP; also elsewhere on the board
MCU_VDD: C0401.1, C0402.1, C0403.1, C0404.1, C0405.1, C0406.1, C0407.1, C0408.1, C0409.1, C0410.1, L0411.2, SJ0401.2; also elsewhere on the board
MCU_VDDA: C0412.1, C0413.1, L0411.1; also elsewhere on the board
MCU_VDDIO2: C0421.2, C0422.1, C0423.1, SJ0421.1, SJ0422.1, SJ0423.1, SJ0424.1; also elsewhere on the board
MCU_VREF_M: R0441.2; also elsewhere on the board
MCU_VREF_P: C0441.2, C0442.2; also elsewhere on the board
VDD12_SW: L0433.2, U0431.5 (SW)

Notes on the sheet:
6mm x 6mm
MCU VDDIO2 selection
MCU VDDA
DC/DC buck converter
MCU VREF
MCU VBAT
not needed!
(1.0A out, 1.5MHz fixed)

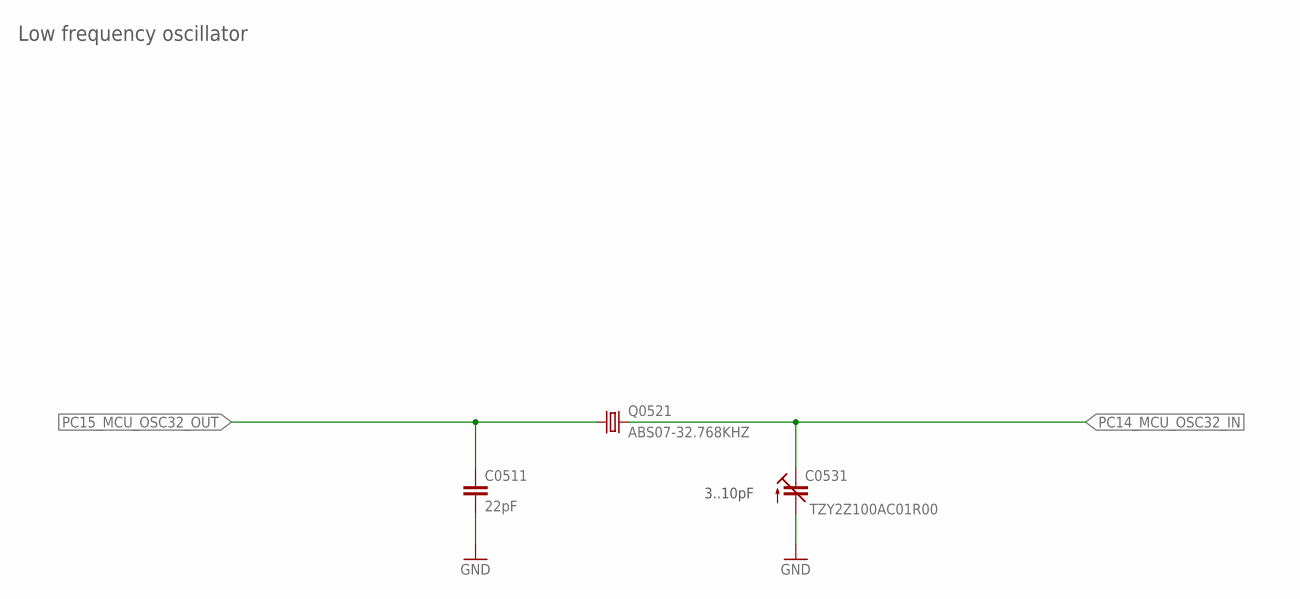
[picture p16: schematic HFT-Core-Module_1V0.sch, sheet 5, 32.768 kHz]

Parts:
C0511: 22pF; C0603
C0531: TZY2Z100AC01R00; 3MM2_X_2MM5
Q0521: ABS07-32.768KHZ; ABS07

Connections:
GND: C0511.2, C0531.+ (A); also elsewhere on the board
PC14_MCU_OSC32_IN: C0531.- (E), Q0521.2; also elsewhere on the board
PC15_MCU_OSC32_OUT: C0511.1, Q0521.1; also elsewhere on the board

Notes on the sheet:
3..10pF
Low frequency oscillator

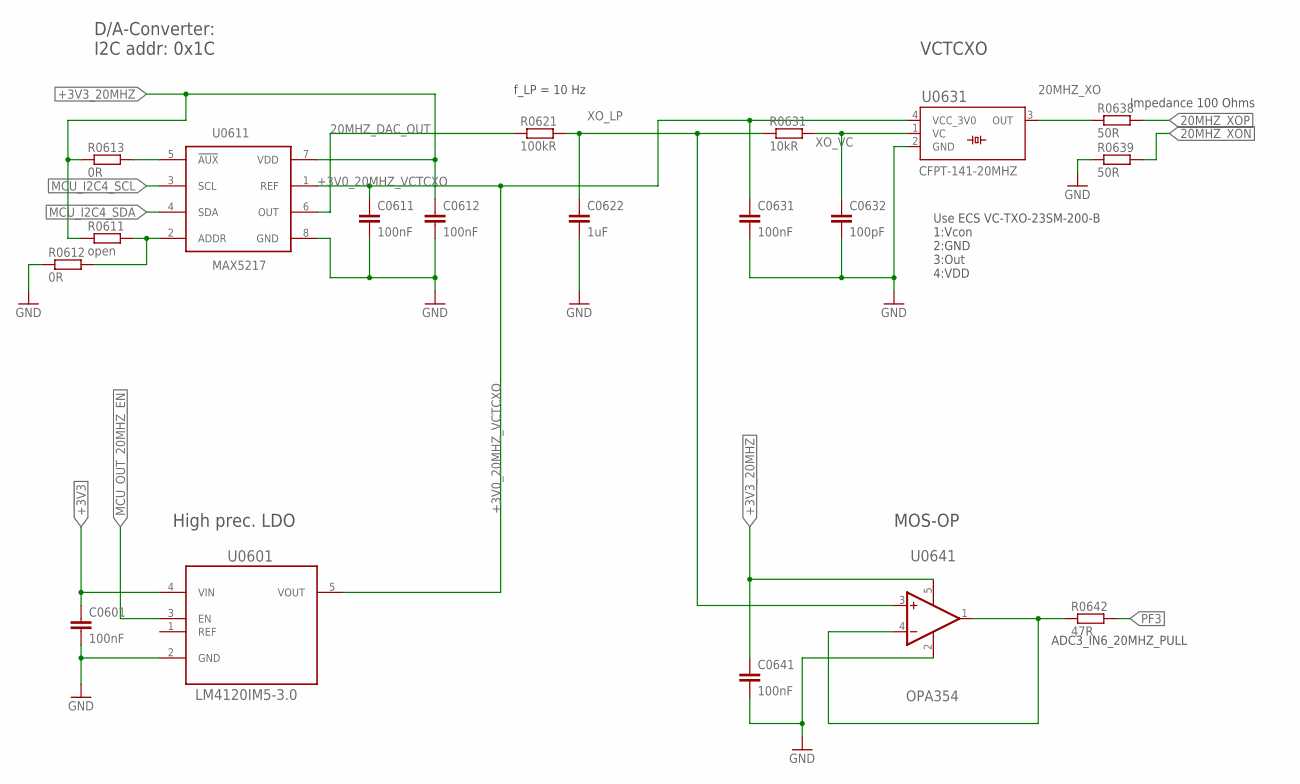
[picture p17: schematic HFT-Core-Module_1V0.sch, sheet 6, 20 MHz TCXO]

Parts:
C0601, C0611, C0612, C0631, C0641: 100nF; C0603
C0622: 1uF; C0805
C0632: 100pF; C0603
R0611: open; R0603
R0612, R0613: 0R; R0603
R0621: 100kR; R0603
R0631: 10kR; R0603
R0638, R0639: 50R; R0603
R0642: 47R; R0603
U0601: LM4120IM5-3.0; SOT95P285X120-5N
U0611: MAX5217; µMAX8
U0631: CFPT-141-20MHZ; CFPT-141
U0641: OPA354; SOT-23-5

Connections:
20MHZ_DAC_OUT: R0621.1, U0611.6 (OUT)
20MHZ_XO: R0638.1, U0631.3 (OUT)
20MHZ_XON: R0639.2; also elsewhere on the board
20MHZ_XOP: R0638.2; also elsewhere on the board
+3V0_20MHZ_VCTCXO: C0611.1, C0631.1, U0601.5 (VOUT), U0611.1 (REF), U0631.4 (VCC_3V0)
+3V3: C0601.1, U0601.4 (VIN); also elsewhere on the board
+3V3_20MHZ: C0612.1, C0641.1, R0611.1, R0613.1, U0611.7 (VDD), U0641.5 (V+); also elsewhere on the board
AD_VCTCXO1: R0642.1, U0641.1 (OUT), U0641.4 (-IN)
GND: C0601.2, C0611.2, C0612.2, C0622.2, C0631.2, C0632.2, C0641.2, R0612.1, R0639.1, U0601.2 (GND), U0611.8 (GND), U0631.2 (GND), U0641.2 (V-); also elsewhere on the board
MAX5217_!AUX: R0613.2, U0611.5 (!AUX)
MAX5217_ADDR: R0611.2, R0612.2, U0611.2 (ADDR)
MCU_I2C4_SCL: U0611.3 (SCL); also elsewhere on the board
MCU_I2C4_SDA: U0611.4 (SDA); also elsewhere on the board
MCU_OUT_20MHZ_EN: U0601.3 (EN); also elsewhere on the board
PF3: R0642.2; also elsewhere on the board
XO_LP: C0622.1, R0621.2, R0631.1, U0641.3 (+IN)
XO_VC: C0632.1, R0631.2, U0631.1 (VC)

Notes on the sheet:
f_LP = 10 Hz
Use ECS VC-TXO-23SM-200-B 1:Vcon 2:GND 3:Out 4:VDD
Impedance 100 Ohms
High prec. LDO
MOS-OP
VCTCXO
D/A-Converter: I2C addr: 0x1C
ADC3_IN6_20MHZ_PULL

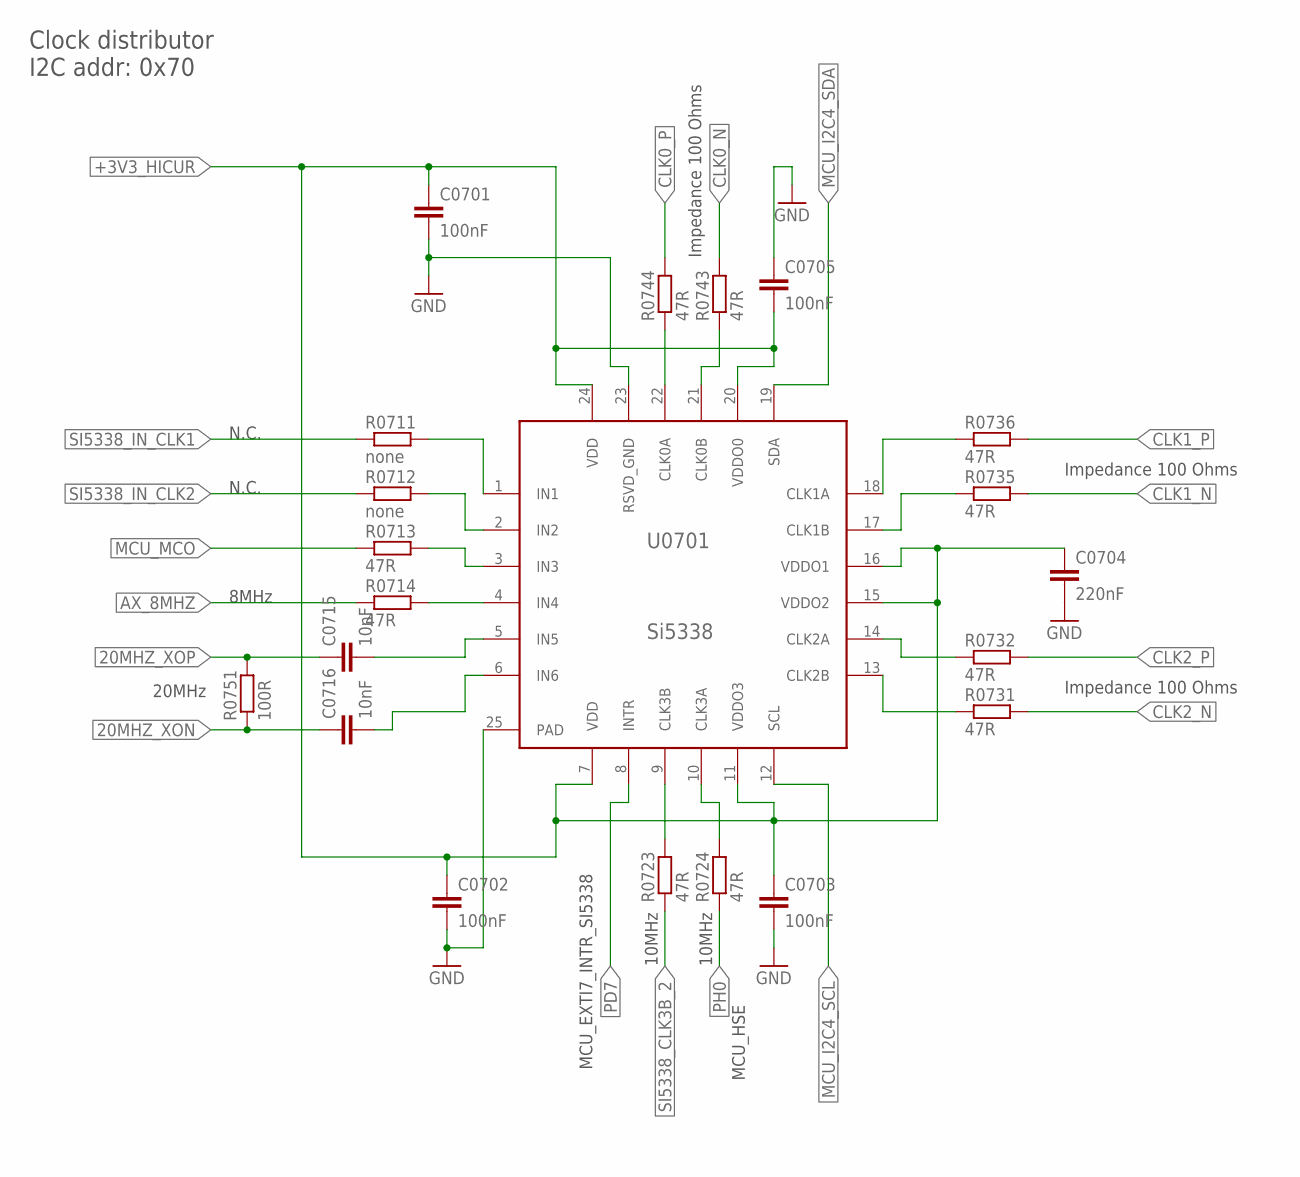
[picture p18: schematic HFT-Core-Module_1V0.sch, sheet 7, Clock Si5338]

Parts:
C0701, C0702, C0703, C0705: 100nF; C0603
C0704: 220nF; C0603
C0715, C0716: 10nF; C0603
R0711, R0712: none; R0603
R0713, R0714, R0723, R0724, R0731, R0732, R0735, R0736, R0743, R0744: 47R; R0603
R0751: 100R; R0603
U0701: Si5338; QFN24_P0MM5_CTRPAD

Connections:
20MHZ_XON: C0716.1, R0751.1; also elsewhere on the board
20MHZ_XOP: C0715.1, R0751.2; also elsewhere on the board
+3V3_HICUR: C0701.1, C0702.1, C0703.1, C0704.1, C0705.2, U0701.7 (VDD), U0701.11 (VDDO3), U0701.15 (VDDO2), U0701.16 (VDDO1), U0701.20 (VDDO0), U0701.24 (VDD); also elsewhere on the board
AX_8MHZ: R0714.1; also elsewhere on the board
CLK0_N: R0743.2; also elsewhere on the board
CLK0_P: R0744.2; also elsewhere on the board
CLK1_N: R0735.2; also elsewhere on the board
CLK1_P: R0736.2; also elsewhere on the board
CLK2_N: R0731.2; also elsewhere on the board
CLK2_P: R0732.2; also elsewhere on the board
GND: C0701.2, C0702.2, C0703.2, C0704.2, C0705.1, U0701.23 (RSVD_GND), U0701.25 (PAD); also elsewhere on the board
MCU_I2C4_SCL: U0701.12 (SCL); also elsewhere on the board
MCU_I2C4_SDA: U0701.19 (SDA); also elsewhere on the board
MCU_MCO: R0713.1; also elsewhere on the board
PD7: U0701.8 (INTR); also elsewhere on the board
PH0: R0724.1; also elsewhere on the board
SI5338_CLK0A: R0744.1, U0701.22 (CLK0A)
SI5338_CLK0B: R0743.1, U0701.21 (CLK0B)
SI5338_CLK1A: R0736.1, U0701.18 (CLK1A)
SI5338_CLK1B: R0735.1, U0701.17 (CLK1B)
SI5338_CLK2A: R0732.1, U0701.14 (CLK2A)
SI5338_CLK2B: R0731.1, U0701.13 (CLK2B)
SI5338_CLK3A: R0724.2, U0701.10 (CLK3A)
SI5338_CLK3B: R0723.2, U0701.9 (CLK3B)
SI5338_CLK3B_2: R0723.1; also elsewhere on the board
SI5338_IN1: R0711.2, U0701.1 (IN1)
SI5338_IN2: R0712.2, U0701.2 (IN2)
SI5338_IN3: R0713.2, U0701.3 (IN3)
SI5338_IN4: R0714.2, U0701.4 (IN4)
SI5338_IN5: C0715.2, U0701.5 (IN5)
SI5338_IN6: C0716.2, U0701.6 (IN6)
SI5338_IN_CLK1: R0711.1
SI5338_IN_CLK2: R0712.1

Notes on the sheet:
Impedance 100 Ohms
Clock distributor I2C addr: 0x70
10MHz
8MHz
20MHz
N.C.
MCU_EXTI7_INTR_SI5338
MCU_HSE

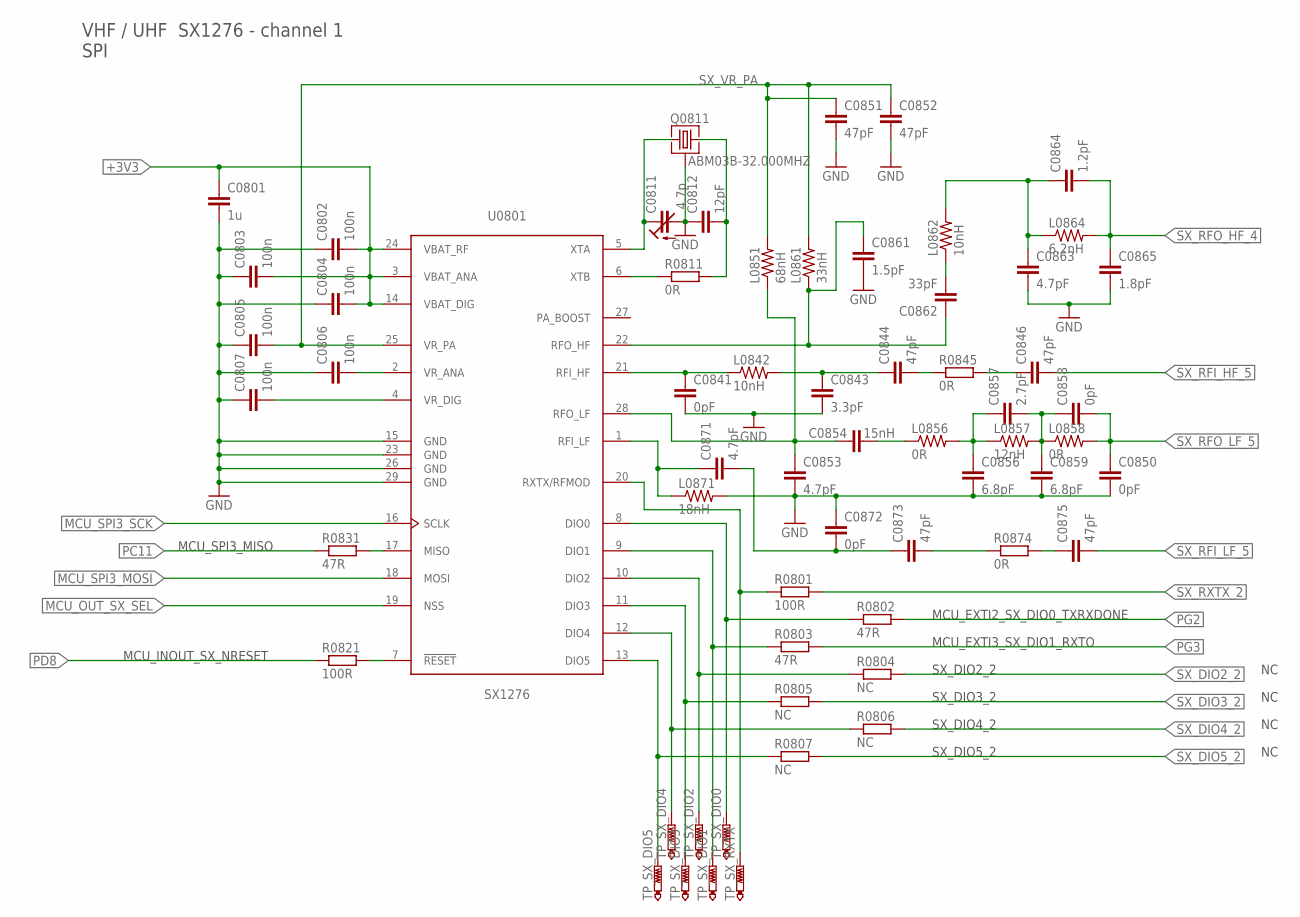
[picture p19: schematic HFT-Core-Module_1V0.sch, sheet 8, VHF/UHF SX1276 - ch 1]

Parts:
C0801: 1u; C0603
C0802, C0803, C0804, C0805, C0806, C0807: 100n; C0603
C0811: 4.7p; 3MM2_X_2MM5
C0812: 12pF; C0603
C0841, C0850, C0858, C0872: 0pF; C0603
C0843: 3.3pF; C0603
C0844, C0846, C0851, C0852, C0873, C0875: 47pF; C0603
C0853, C0863, C0871: 4.7pF; C0603
C0854: 15nH; C0603
C0856, C0859: 6.8pF; C0603
C0857: 2.7pF; C0603
C0861: 1.5pF; C0603
C0862: 33pF; C0603
C0864: 1.2pF; C0603
C0865: 1.8pF; C0603
L0842, L0862: 10nH; R0603
L0851: 68nH; R0603
L0856, L0858: 0R; R0603
L0857: 12nH; R0603
L0861: 33nH; R0603
L0864: 6.2nH; R0603
L0871: 18nH; R0603
Q0811: ABM03B-32.000MHZ; ABM03B
R0801, R0821: 100R; R0603
R0802, R0803, R0831: 47R; R0603
R0804, R0805, R0806, R0807: NC; R0603
R0811, R0845, R0874: 0R; R0603
TP_SX_DIO0, TP_SX_DIO1, TP_SX_DIO2, TP_SX_DIO3, TP_SX_DIO4, TP_SX_DIO5: PTR1TP06R; TP06R
TP_SX_RXTX: PTR1TP06R; TP06R
U0801: SX1276; QFN28-6X6-0P65-PAD

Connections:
+3V3: C0801.1, C0802.2, C0803.2, C0804.2, U0801.3 (VBAT_ANA), U0801.14 (VBAT_DIG), U0801.24 (VBAT_RF); also elsewhere on the board
GND: C0801.2, C0802.1, C0803.1, C0804.1, C0805.1, C0806.1, C0807.1, C0811.+ (A), C0812.1, C0841.2, C0843.2, C0850.2, C0851.2, C0852.2, C0853.2, C0856.2, C0859.2, C0861.2, C0863.2, C0865.2, C0872.1, L0871.2, Q0811.2 (3), Q0811.4 (3), U0801.15 (GND), U0801.23 (GND), U0801.26 (GND), U0801.29 (GND); also elsewhere on the board
MCU_OUT_SX_SEL: U0801.19 (NSS); also elsewhere on the board
MCU_SPI3_MOSI: U0801.18 (MOSI); also elsewhere on the board
MCU_SPI3_SCK: U0801.16 (SCLK); also elsewhere on the board
PC11: R0831.1; also elsewhere on the board
PD8: R0821.1; also elsewhere on the board
PG2: R0802.2; also elsewhere on the board
PG3: R0803.2; also elsewhere on the board
SX_DIO0: R0802.1, TP_SX_DIO0.TP, U0801.8 (DIO0)
SX_DIO1: R0803.1, TP_SX_DIO1.TP, U0801.9 (DIO1)
SX_DIO2: R0804.1, TP_SX_DIO2.TP, U0801.10 (DIO2)
SX_DIO2_2: R0804.2
SX_DIO3: R0805.1, TP_SX_DIO3.TP, U0801.11 (DIO3)
SX_DIO3_2: R0805.2
SX_DIO4: R0806.1, TP_SX_DIO4.TP, U0801.12 (DIO4)
SX_DIO4_2: R0806.2
SX_DIO5: R0807.1, TP_SX_DIO5.TP, U0801.13 (DIO5)
SX_DIO5_2: R0807.2
SX_MISO: R0831.2, U0801.17 (MISO)
SX_NRESET: R0821.2, U0801.7 (!RESET)
SX_RFI_HF: C0841.1, L0842.1, U0801.21 (RFI_HF)
SX_RFI_HF_2: C0843.1, C0844.1, L0842.2
SX_RFI_HF_3: C0844.2, R0845.1
SX_RFI_HF_4: C0846.1, R0845.2
SX_RFI_HF_5: C0846.2; also elsewhere on the board
SX_RFI_LF: C0871.1, L0871.1, U0801.1 (RFI_LF)
SX_RFI_LF_2: C0871.2, C0872.2, C0873.1
SX_RFI_LF_3: C0873.2, R0874.1
SX_RFI_LF_4: C0875.1, R0874.2
SX_RFI_LF_5: C0875.2; also elsewhere on the board
SX_RFO_HF: C0861.1, C0862.1, L0861.1, U0801.22 (RFO_HF)
SX_RFO_HF_2: C0862.2, L0862.1
SX_RFO_HF_3: C0863.1, C0864.1, L0862.2, L0864.1
SX_RFO_HF_4: C0864.2, C0865.1, L0864.2; also elsewhere on the board
SX_RFO_LF: C0853.1, C0854.1, L0851.1, U0801.28 (RFO_LF)
SX_RFO_LF_2: C0854.2, L0856.1
SX_RFO_LF_3: C0856.1, C0857.1, L0856.2, L0857.1
SX_RFO_LF_4: C0857.2, C0858.1, C0859.1, L0857.2, L0858.1
SX_RFO_LF_5: C0850.1, C0858.2, L0858.2; also elsewhere on the board
SX_RXTX: R0801.1, TP_SX_RXTX.TP, U0801.20 (RXTX/RFMOD)
SX_RXTX_2: R0801.2; also elsewhere on the board
SX_VR_ANA: C0806.2, U0801.2 (VR_ANA)
SX_VR_DIG: C0807.2, U0801.4 (VR_DIG)
SX_VR_PA: C0805.2, C0851.1, C0852.1, L0851.2, L0861.2, U0801.25 (VR_PA)
SX_XTA: C0811.- (E), Q0811.1, U0801.5 (XTA)
SX_XTB: R0811.1, U0801.6 (XTB)
SX_XTB_R: C0812.2, Q0811.3 (2), R0811.2

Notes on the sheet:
VHF / UHF SX1276 - channel 1 SPI
MCU_SPI3_MISO
MCU_INOUT_SX_NRESET
MCU_EXTI2_SX_DIO0_TXRXDONE
MCU_EXTI3_SX_DIO1_RXTO
SX_DIO2_2
SX_DIO3_2
SX_DIO4_2
SX_DIO5_2

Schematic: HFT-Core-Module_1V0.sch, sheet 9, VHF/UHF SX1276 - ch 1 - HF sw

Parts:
C0911, C0921, C0999: 1nF; C0603
C0991: 100pF HiQ; C0603
C0992, C0993: 330pF HiQ; C0603
C0994, C0996: 0nF HiQ; C0603
L0995: 0R; R0603
U0911, U0921, U0991: PE4259; SC-70_6-LEAD_2X1MM25_0P65

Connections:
+3V3: C0911.1, C0921.1, C0999.1, U0911.6 (VDD_!CTRL), U0921.6 (VDD_!CTRL), U0991.6 (VDD_!CTRL); also elsewhere on the board
CH1_ANT: C0996.1, L0995.2; also elsewhere on the board
GND: C0911.2, C0921.2, C0994.2, C0996.2, C0999.2, U0911.2 (GND), U0921.2 (GND), U0991.2 (GND); also elsewhere on the board
MCU_SX_TX_RX_CTRL: U0991.4 (CTRL); also elsewhere on the board
SX_ANT_1: C0993.1, U0991.5 (RFC)
SX_ANT_2: C0993.2, C0994.1, L0995.1
SX_HF_1: C0991.1, U0911.5 (RFC)
SX_HF_2: C0991.2, U0991.1 (RF1)
SX_LF_1: C0992.1, U0921.5 (RFC)
SX_LF_2: C0992.2, U0991.3 (RF2)
SX_RFI_HF_5: U0911.3 (RF2); also elsewhere on the board
SX_RFI_LF_5: U0921.3 (RF2); also elsewhere on the board
SX_RFO_HF_4: U0911.1 (RF1); also elsewhere on the board
SX_RFO_LF_5: U0921.1 (RF1); also elsewhere on the board
SX_RXTX_2: U0911.4 (CTRL), U0921.4 (CTRL); also elsewhere on the board

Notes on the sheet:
HF: high / LF: low

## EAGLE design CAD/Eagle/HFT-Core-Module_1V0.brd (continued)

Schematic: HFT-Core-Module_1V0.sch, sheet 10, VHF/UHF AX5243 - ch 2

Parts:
C1001, C1002, C1003: 100nF; C0603
C_AX_A2, C_AX_A3: 4.7pF; C0603
C_AX_B2: 4.7pF; C0603
C_AX_C1, C_AX_C2: 0pF; C0603
C_AX_F2: 4.7pF; C0603
C_AX_M1: 4.7pF; C0603
C_AX_M2: 0pF; C0603
C_AX_T1, C_AX_T2: 4.3pF; C0603
L_AX_1: 22nH; R0603
L_AX_B1, L_AX_B2: 22nH; R0603
L_AX_C1, L_AX_C2: 100nH; R0603
L_AX_F1: 22nH; R0603
L_AX_T1, L_AX_T2: 43nH; R0603
Q0911: ABM3B-16MHZ-10-R50-1-U; ABM03B
R1021, R1041, R1051, R1061: 47R; R0603
R1031, R1032: 100kR; R0603
TP_AX_ADC1, TP_AX_ADC2: PTR1TP06R; TP06R
TP_AX_IRQ: PTR1TP06R; TP06R
TP_AX_TCXO_EN: PTR1TP06R; TP06R
U0901: AX5243; QFN20-4X4-0P5-PAD

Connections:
+3V3: C1001.1, U0901.16 (VDD_IO); also elsewhere on the board
AX_8MHZ: R1021.2; also elsewhere on the board
AX_ADC1: R1031.1, TP_AX_ADC1.TP, U0901.17 (GPADC1)
AX_ADC2: R1032.1, TP_AX_ADC2.TP, U0901.18 (GPADC2)
AX_ANTN: C_AX_C2.1, C_AX_T2.1, L_AX_C2.1, U0901.4 (ANTN)
AX_ANTP: C_AX_C1.1, C_AX_T1.1, L_AX_C1.1, U0901.3 (ANTP)
AX_B1: C_AX_M1.1, L_AX_B1.1, L_AX_T1.2
AX_B2: C_AX_B2.1, C_AX_M2.1, L_AX_B2.2, L_AX_T2.2
AX_CLK16N: Q0911.1, U0901.19 (CLK16N)
AX_CLK16P: Q0911.3 (2), U0901.20 (CLK16P)
AX_COMB: C_AX_A2.1, C_AX_B2.2, C_AX_F2.1, L_AX_B1.2, L_AX_F1.1
AX_GPIO1: R1061.2, TP_AX_TCXO_EN.TP, U0901.15 (TCXO_EN)
AX_IRQ: R1051.2, TP_AX_IRQ.TP, U0901.14 (IRQ)
AX_L1: L_AX_1.1, U0901.8 (L1)
AX_L2: L_AX_1.2, U0901.7 (L2)
AX_SYSCLK: R1021.1, U0901.9 (SYSCLK)
AX_T1: C_AX_T1.2, L_AX_T1.1
AX_T2: C_AX_T2.2, L_AX_T2.1
AX_VDD1: C1002.2, U0901.1 (VDD_ANA)
AX_VDD5: C1003.2, U0901.5 (VDD_ANA)
CH2_ANT: C_AX_A3.1, C_AX_F2.2, L_AX_F1.2; also elsewhere on the board
GND: C1001.2, C1002.1, C1003.1, C_AX_A2.2, C_AX_A3.2, C_AX_C1.2, C_AX_C2.2, C_AX_M1.2, C_AX_M2.2, L_AX_B2.1, L_AX_C1.2, L_AX_C2.2, Q0911.2 (3), Q0911.4 (3), R1031.2, R1032.2, U0901.2 (GND), U0901.21 (GND); also elsewhere on the board
MCU_AX_MISO: R1041.2, U0901.12 (MISO)
MCU_OUT_AX_SEL: U0901.10 (SEL); also elsewhere on the board
MCU_SPI3_MOSI: U0901.13 (MOSI); also elsewhere on the board
MCU_SPI3_SCK: U0901.11 (CLK); also elsewhere on the board
PC11: R1041.1; also elsewhere on the board
PE7: R1051.1; also elsewhere on the board
PG1: R1061.1; also elsewhere on the board

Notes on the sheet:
VHF / UHF AX5243 - channel 2 SPI

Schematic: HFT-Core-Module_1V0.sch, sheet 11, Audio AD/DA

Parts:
C1101, C1102, C1103, C1111, C1112, C1128, C1129: 100nF; C0603
C1104, C1105, C1131, C1141: 220nF; C0603
C1113: 47pF; C0603
C1132, C1142: 100uF; C0805
L1102, L1112: 10uH; L2012C
R1104, R1105: 22kR; R0603
R1106, R1107, R1108, R1109, R1114: 47R; R0603
R1110: 33kR; R0603
R1131, R1141: 10kR; R0603
R1132, R1135, R1142, R1145: 10MR; R0603
U1101: MCP3911A0-E-SS; QFN20_P0MM5_CTRPAD
U1111: MAX5136AGTG+; QFN24_P0MM5_CTRPAD
U1121, U1131, U1141: OPA354; SOT-23-5

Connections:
+3V3_HICUR: C1101.1, C1111.1, C1128.1, C1129.1, L1102.2, L1112.2, U1101.19 (DVDD), U1111.3 (DVDD), U1111.15 (!LDAC), U1121.5 (V+), U1131.5 (V+), U1141.5 (V+); also elsewhere on the board
AUDIO_IN_L: C1104.1; also elsewhere on the board
AUDIO_IN_R: C1105.1; also elsewhere on the board
AUDIO_OUT_L: C1132.2; also elsewhere on the board
AUDIO_OUT_L_OP: C1132.1, U1131.1 (OUT), U1131.4 (-IN)
AUDIO_OUT_R: C1142.2; also elsewhere on the board
AUDIO_OUT_R_OP: C1142.1, U1141.1 (OUT), U1141.4 (-IN)
GND: C1101.2, C1102.1, C1103.1, C1111.2, C1112.1, C1113.2, C1128.2, C1129.2, R1104.1, R1105.1, R1110.1, R1135.1, R1145.1, U1101.2 (CH0-), U1101.4 (CH1-), U1101.5 (AGND), U1101.7 (REFIN-), U1101.8 (DGND), U1101.21 (DGND), U1111.7 (GND), U1111.19 (GND), U1111.25 (GND), U1121.2 (V-), U1131.2 (V-), U1141.2 (V-); also elsewhere on the board
MAX5136_!READY: R1114.2, U1111.4 (!READY)
MAX5136_AVDD: C1112.2, L1112.1, U1111.16 (M/!Z), U1111.24 (AVDD)
MAX5136_OUT0: R1131.1, U1111.1 (OUT0)
MAX5136_OUT0_R: C1131.1, R1131.2
MAX5136_OUT0_SUM: C1131.2, R1132.2, R1135.2, U1131.3 (+IN)
MAX5136_OUT1: R1141.1, U1111.18 (OUT1)
MAX5136_OUT1_R: C1141.1, R1141.2
MAX5136_OUT1_SUM: C1141.2, R1142.2, R1145.2, U1141.3 (+IN)
MAX5136_REF: C1113.1, U1111.21 (REFO), U1111.22 (REFI), U1121.3 (+IN)
MAX5136_REF_OP: R1132.1, R1142.1, U1121.1 (OUT), U1121.4 (-IN)
MCP3911_!DR: R1106.1, U1101.11 (!DR)
MCP3911_CH0+: C1104.2, R1104.2, U1101.1 (CH0+)
MCP3911_CH1+: C1105.2, R1105.2, U1101.3 (CH1+)
MCP3911_MDAT0: R1108.1, U1101.10 (MDAT0)
MCP3911_MDAT1: R1109.1, U1101.9 (MDAT1)
MCP3911_REFINOUT: C1103.2, U1101.6 (REFINOUT)
MCP3911_SDO: R1107.1, U1101.16 (SDO)
MCU_OUT_AUDIO_ADC_NRESET: R1110.2, U1101.18 (!RESET); also elsewhere on the board
MCU_OUT_AUDIO_ADC_SEL: U1101.14 (!CS); also elsewhere on the board
MCU_OUT_AUDIO_DAC_SEL: U1111.10 (!CS); also elsewhere on the board
MCU_SPI3_MOSI: U1101.17 (SDI), U1111.9 (DIN); also elsewhere on the board
MCU_SPI3_SCK: U1101.15 (SCK), U1111.12 (SCLK); also elsewhere on the board
MVP3911_AVDD: C1102.2, L1102.1, U1101.20 (AVDD)
PC8: R1114.1; also elsewhere on the board
PC11: R1107.2; also elsewhere on the board
PD0: R1109.2; also elsewhere on the board
PD1: R1108.2; also elsewhere on the board
PD2: R1106.2; also elsewhere on the board
SI5338_CLK3B_2: U1101.12 (OSC1); also elsewhere on the board

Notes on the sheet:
Audio stereo A/D-Converter SPI
N.C. (should be connected to GND)
10MHz
Audio stereo D/A-Converter SPI
MCU_IN_AUDIO_DAC_NRDY
MCU_IN_AUDIO_ADC_MDAT0
MCU_IN_AUDIO_ADC_MDAT1
MCU_IN_AUDIO_ADC_NDR
MCU_SPI3_MISO

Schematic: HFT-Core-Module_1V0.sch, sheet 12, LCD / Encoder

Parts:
C1211, C1221: 1uF; C0805
C1231: 100nF; C0603
C1261, C1262, C1271: 1nF; C0603
R1201, R1204, R1207: 2.0kR; R0603
R1202, R1205, R1208: 1.5kR; R0603
R1203, R1206, R1209: 27R; R0805
R1241: 33kR; R0603
R1261, R1262, R1271: 10kR; R0603
T1201, T1202, T1203: MMBT2222; SOT23
U1201: NHD-C0220BIZ_2X20CHARS
X1261: TTE_EN11-HSM

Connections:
+3V3: C1231.1, U1201.5 (VDD), U1201.12 (A); also elsewhere on the board
GND: C1221.2, C1231.2, C1261.2, C1262.2, C1271.2, R1202.1, R1203.1, R1205.1, R1206.1, R1208.1, R1209.1, R1241.1, U1201.4 (VSS), X1261.C, X1261.D; also elsewhere on the board
LCD_C1+: C1211.2, U1201.7 (C1+)
LCD_C1-: C1211.1, U1201.8 (C1-)
LCD_VOUT: C1221.1, U1201.6 (VOUT)
LED_B_B: R1207.1, R1208.2, T1203.1 (B)
LED_B_E: R1209.2, T1203.2 (E)
LED_B_K: T1203.3 (C), U1201.11 (KB)
LED_G_B: R1204.1, R1205.2, T1202.1 (B)
LED_G_E: R1206.2, T1202.2 (E)
LED_G_K: T1202.3 (C), U1201.10 (KG)
LED_R_B: R1201.1, R1202.2, T1201.1 (B)
LED_R_E: R1203.2, T1201.2 (E)
LED_R_K: T1201.3 (C), U1201.9 (KR)
MCU_I2C4_SCL: U1201.2 (SCL); also elsewhere on the board
MCU_I2C4_SDA: U1201.3 (SDA); also elsewhere on the board
MCU_OUT_LCD_NRST: R1241.2, U1201.1 (RST); also elsewhere on the board
PA7: R1204.2; also elsewhere on the board
PB0: R1207.2; also elsewhere on the board
PB10: R1261.2; also elsewhere on the board
PB12: R1262.2; also elsewhere on the board
PB14: R1271.2; also elsewhere on the board
PC6: R1201.2; also elsewhere on the board
ROTENC_A: C1261.1, R1261.1, X1261.A
ROTENC_B: C1262.1, R1262.1, X1261.B
ROTENC_E: C1271.1, R1271.1, X1261.E

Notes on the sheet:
LCD: 2x20 chars NHD-C0220BIZ-FS(RGB)-FBW-3VM-ND
LC-Display I2C addr: 0x3E
Rotary Encoder with Pushbutton
MCU_PWM_LED_R
MCU_PWM_LED_G
MCU_PWM_LED_B
MCU_IN_RE_I
MCU_IN_RE_Q
MCU_IN_RE_PB

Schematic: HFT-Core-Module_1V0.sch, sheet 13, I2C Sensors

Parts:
C1301, C1303, C1311, C1321: 100nF; C0603
C1302: 10nF; C0603
R1301: 68R; R0603
R1331, R1332: 1.0kR; R0603
U1301: MPU-9250; QFN24-3X3
U1311: MS5607-02BA03; MS5607-02BA
U1321: SHT31-DIS; DFN8/SHT

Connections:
+3V3: C1301.1, C1302.1, C1311.1, C1321.1, R1331.2, R1332.2, U1301.1 (VDDIO), U1301.8 (VDDIO), U1301.13 (VDD), U1301.22 (!CS), U1311.1 (VDD), U1311.2 (PS), U1311.4 (CSB_!ADDR), U1321.5 (VDD), U1321.6 (!RESET); also elsewhere on the board
GND: C1301.2, C1302.2, C1303.2, C1311.2, C1321.2, U1301.9 (AD0/SDO), U1301.11 (FSYNC), U1301.18 (GND), U1301.20 (GND), U1311.3 (GND), U1321.2 (ADDR), U1321.7 (R), U1321.8 (VSS), U1321.9 (PAD); also elsewhere on the board
MCU_I2C4_SCL: R1332.1, U1301.23 (SCL/SCLK), U1311.8 (SCL_SCLK), U1321.4 (SCL); also elsewhere on the board
MCU_I2C4_SDA: R1331.1, U1301.24 (SDA/SDI), U1311.7 (SDI_SDA), U1321.1 (SDA); also elsewhere on the board
MPU_INT: R1301.1, U1301.12 (INT)
MPU_REGOUT: C1303.1, U1301.10 (REGOUT)
PF13: R1301.2; also elsewhere on the board

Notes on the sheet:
Baro sensor: MS5607-02BA03 I2C addr: 0x76
9-axis sensor: MPU-9250 I2C addr: 0x68, 0x0C
RH sensor: Sensirion SHT3x I2C addr: 0x44
I2C4 Termination
I2C2_INT

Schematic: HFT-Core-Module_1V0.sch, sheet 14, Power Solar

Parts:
C1401: 100uF; C0805
C1402, C1403: 100nF; C0603
C1404: 10uF; C0805
C1405: 0nF; C0603
C1406: 47uF; C0805
D1403: CRS08; SOD80C
L1403: 33uH; L_13.5X12.5MM
R1404, R1405, R1406, R1409: 0R; R0603
R1407, R1412: 100kR; R0603
R1408: 310kR; R0603
R1411: 1kR; R0603
TP_+5V0_SOL: PTR1B1,27; B1,27
TP_VSOL: PTR1B1,27; B1,27
U1401: SOLARPANEL_3V3_5MA1_25MM_X_20MM
U1402: SPV1040T; TSSOP8

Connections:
+5V0: R1409.2; also elsewhere on the board
+5V1_SOL: C1406.1, R1405.2, R1406.2, R1408.2, R1409.1, TP_+5V0_SOL.TP
GND: C1401.2, C1402.2, C1403.2, C1404.2, C1406.2, R1407.1, U1401.-VSOL, U1402.2 (GND); also elsewhere on the board
PA3: R1411.2; also elsewhere on the board
PF9: R1412.1; also elsewhere on the board
SPV_ICTRL_M: C1405.2, R1405.1, U1402.6 (ICTRL_M)
SPV_ICTRL_P: C1405.1, R1404.1, U1402.7 (ICTRL_P)
SPV_LX: D1403.A, L1403.1, R1412.2, U1402.3 (LX)
SPV_VCTRL: R1407.2, R1408.1, U1402.5 (VCTRL)
SPV_VOUT: C1403.1, C1404.1, D1403.C, R1404.2, R1406.1, U1402.4 (VOUT)
VSOL: C1401.1, C1402.1, L1403.2, R1411.1, TP_VSOL.TP, U1401.+VSOL, U1402.1 (MPP_SET), U1402.8 (XSHUT)

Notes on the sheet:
1V25
Imax:50mV
13.5mm x 12.5mm
DC/DC boost converter
Imax disabled
Solar power converter
MCU_VSOL_ADC1
MCU_VSOL_TIMCAP

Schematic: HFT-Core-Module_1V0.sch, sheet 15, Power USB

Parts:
C1501: 100nF; C0603
D1501: CRS08; SOD80C
R1502: 33kR; R0603
TP_+5V0_USB_SW: PTR1B1,27; B1,27
U1501: TS5A23166; R-PDSO-G8

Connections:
+5V0: D1501.C; also elsewhere on the board
GND: C1501.2, R1502.1, U1501.4; also elsewhere on the board
MCU_OUT_VUSB_EN: R1502.2, U1501.3, U1501.7; also elsewhere on the board
VDDUSB: C1501.1, U1501.1, U1501.5, U1501.8; also elsewhere on the board
VUSB_SW: D1501.A, TP_+5V0_USB_SW.TP, U1501.2, U1501.6

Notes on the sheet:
Electronic switch for USB <--> 5V

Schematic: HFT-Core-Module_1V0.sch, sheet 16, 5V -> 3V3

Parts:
C1601, C1607: 1F_EEC-S5R5H105N; W14MM_D8MM_P13MM5
C1602, C1606: 47uF; C0805
C1605: 100nF; C0603
L1604: 1.0uH 33mR; L5650M
TP_+3V3, TP_+5V0: PTR1B1,27; B1,27
U1601: SC189ZSKTRT; SOT95P280X145-5N

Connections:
+3V3: C1605.1, C1606.1, C1607.+, L1604.1, TP_+3V3.TP, U1601.4 (VOUT_FB); also elsewhere on the board
+5V0: C1601.+, C1602.1, TP_+5V0.TP, U1601.1 (VIN), U1601.3 (EN); also elsewhere on the board
GND: C1601.-, C1602.2, C1605.2, C1606.2, C1607.-, U1601.2 (GND); also elsewhere on the board
SW: L1604.2, U1601.5 (SW)

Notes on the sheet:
5mm x 5mm
DC/DC buck converter
Power converter 5V --> 3.3V
(1.5A out, 1.5MHz fixed)
(replaces PAM2305)

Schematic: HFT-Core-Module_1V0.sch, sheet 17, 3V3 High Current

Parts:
C1701, C1703: 100nF; C0603
R1702: 33kR; R0603
TP_+3V3_HICUR: PTR1B1,27; B1,27
U1701: TS5A23166; R-PDSO-G8

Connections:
+3V3: C1701.1, U1701.1, U1701.5, U1701.8; also elsewhere on the board
+3V3_HICUR: C1703.1, TP_+3V3_HICUR.TP, U1701.2, U1701.6; also elsewhere on the board
GND: C1701.2, C1703.2, R1702.1, U1701.4; also elsewhere on the board
MCU_OUT_HICUR_EN: R1702.2, U1701.3, U1701.7; also elsewhere on the board

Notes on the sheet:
Electronic switch for clock distribution unit

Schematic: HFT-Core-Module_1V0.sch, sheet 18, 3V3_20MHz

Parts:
C1801, C1803: 100nF; C0603
R1802: 33kR; R0603
TP_+3V3_20MHZ: PTR1B1,27; B1,27
U1801: TS5A23166; R-PDSO-G8

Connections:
+3V3: C1801.1, U1801.1, U1801.5, U1801.8; also elsewhere on the board
+3V3_20MHZ: C1803.1, TP_+3V3_20MHZ.TP, U1801.2, U1801.6; also elsewhere on the board
GND: C1801.2, C1803.2, R1802.1, U1801.4; also elsewhere on the board
MCU_OUT_20MHZ_EN: R1802.2, U1801.3, U1801.7; also elsewhere on the board

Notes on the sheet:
Electronic switch for TCXO unit

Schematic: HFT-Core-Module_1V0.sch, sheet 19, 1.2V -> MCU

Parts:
C1901, C1902, C1903, C1908, C1909: 100nF; C0603
R1902: 33kR; R0603
TP_+1V2_MCU: PTR1B1,27; B1,27
U1901: TS5A23166; R-PDSO-G8

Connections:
+1V2: C1901.1, U1901.1, U1901.5; also elsewhere on the board
+3V3: C1902.1, U1901.8; also elsewhere on the board
GND: C1901.2, C1902.2, C1903.2, C1908.1, C1909.2, R1902.1, U1901.4; also elsewhere on the board
MCU_OUT_VDD12_EN: R1902.2, U1901.3, U1901.7; also elsewhere on the board
MCU_VDD12: C1903.1, C1908.2, C1909.1, TP_+1V2_MCU.TP, U1901.2, U1901.6; also elsewhere on the board

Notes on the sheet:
Electronic switch for MCU SMTP ext. 1.2V

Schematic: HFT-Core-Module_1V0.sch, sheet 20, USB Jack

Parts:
C2003: 1nF; C0603
PF2011: 1.1A/2.2A; M1206
R2002: 330kR; R0603
X2001: MOLEX 105017-0001; USB-B-MICRO-SMD_MOLEX-105017-0001

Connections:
GND: C2003.1, R2002.1, X2001.GND; also elsewhere on the board
PA9: PF2011.1, X2001.VBUS (J_VUSB); also elsewhere on the board
PA10: X2001.ID (J_ID); also elsewhere on the board
PA_USB_N: X2001.D- (J_D-); also elsewhere on the board
PA_USB_P: X2001.D+ (J_D+); also elsewhere on the board
USB_SHIELD: C2003.2, R2002.2, X2001.JSHIELD (SHIELD), X2001.JSHIELD@2 (SHIELD), X2001.JSHIELD@3 (SHIELD), X2001.JSHIELD@4 (SHIELD), X2001.JSHIELD@5 (SHIELD), X2001.JSHIELD@6 (SHIELD)
VDDUSB: PF2011.2; also elsewhere on the board

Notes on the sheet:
Impedance 90 Ohms
USB device and USB host (OTG) interface
MCU_USB_DM
MCU_USB_DP
MCU_USB_ID
MCU_USB_OTG_FS_VBUS
LITTLEFUSE 1206L050YR

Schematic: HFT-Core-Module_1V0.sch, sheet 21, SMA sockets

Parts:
X2101, X2111: SMA_SMT_AMPHENOL-901-143, SAMTEC SMA-J-P-H-RA-TH1; SMA_SMT_AMPHENOL_901-143

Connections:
CH1_ANT: X2101.1; also elsewhere on the board
CH2_ANT: X2111.1; also elsewhere on the board
GND: X2101.2, X2101.3 (2), X2101.4 (2), X2101.5 (2), X2111.2, X2111.3 (2), X2111.4 (2), X2111.5 (2); also elsewhere on the board

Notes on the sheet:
SMA channel 1
SMA channel 2

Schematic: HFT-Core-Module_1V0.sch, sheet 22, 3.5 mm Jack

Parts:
X2201, X2211: CUI SJ1-3535NS; SJ1-353XNS_3MM5-STEREO-AUDIO-JACKS

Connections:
AUDIO_IN_L: X2201.2 (TIP); also elsewhere on the board
AUDIO_IN_R: X2201.3 (RING); also elsewhere on the board
AUDIO_OUT_L: X2211.2 (TIP); also elsewhere on the board
AUDIO_OUT_R: X2211.3 (RING); also elsewhere on the board
GND: X2201.1 (SLEEVE), X2201.6 (GND), X2201.7 (GND), X2201.8 (GND), X2211.1 (SLEEVE), X2211.6 (GND), X2211.7 (GND), X2211.8 (GND); also elsewhere on the board

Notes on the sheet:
Audio connectors
AUDIO IN
AUDIO OUT

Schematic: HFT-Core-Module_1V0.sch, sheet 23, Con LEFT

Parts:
R2310, R2311, R2312, R2313, R2314, R2315, R2316, R2317, R2318, R2320, R2321, R2322, R2323, R2324, R2325, R2326, R2327, R2328, R2330, R2331, R2332, R2333, R2334, R2335, R2336, R2337, R2338: 47R; R0603
X2311, X2312, X2321, X2322, X2331, X2332: 2X20/90_1MM27_HARWIN_M50-3202045

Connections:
+3V3: X2311.3, X2311.4, X2312.37, X2312.38, X2321.3, X2321.4, X2322.37, X2322.38, X2331.3, X2331.4, X2332.37, X2332.38; also elsewhere on the board
+5V0: X2311.37, X2311.38, X2321.37, X2321.38, X2331.37, X2331.38; also elsewhere on the board
CLK0_N: X2332.4; also elsewhere on the board
CLK0_P: X2332.3; also elsewhere on the board
CLK1_N: X2322.4; also elsewhere on the board
CLK1_P: X2322.3; also elsewhere on the board
CLK2_N: X2312.4; also elsewhere on the board
CLK2_P: X2312.3; also elsewhere on the board
EVT_N: R2314.2, X2311.29
EVT_S: R2334.2, X2331.29
EVT_W: R2324.2, X2321.29
GND: X2311.1, X2311.2, X2311.5, X2311.6, X2311.8, X2311.10, X2311.12, X2311.14, X2311.21, X2311.22, X2311.27, X2311.28, X2311.30, X2311.32, X2311.34, X2311.35, X2311.36, X2311.39, X2311.40, X2312.1, X2312.2, X2312.5, X2312.6, X2312.9, X2312.10, X2312.14, X2312.15, X2312.16, X2312.21, X2312.22, X2312.25, X2312.27, X2312.28, X2312.39, X2312.40, X2321.1, X2321.2, X2321.5, X2321.6, X2321.8, X2321.10, X2321.12, X2321.14, X2321.21, X2321.22, X2321.27, X2321.28, X2321.30, X2321.32, X2321.34, X2321.35, X2321.36, X2321.39, X2321.40, X2322.1, X2322.2, X2322.5, X2322.6, X2322.9, X2322.10, X2322.14, X2322.15, X2322.16, X2322.21, X2322.22, X2322.25, X2322.27, X2322.28, X2322.39, X2322.40, X2331.1, X2331.2, X2331.5, X2331.6, X2331.8, X2331.10, X2331.12, X2331.14, X2331.21, X2331.22, X2331.27, X2331.28, X2331.30, X2331.32, X2331.34, X2331.35, X2331.36, X2331.39, X2331.40, X2332.1, X2332.2, X2332.5, X2332.6, X2332.9, X2332.10, X2332.14, X2332.15, X2332.16, X2332.21, X2332.22, X2332.25, X2332.27, X2332.28, X2332.39, X2332.40; also elsewhere on the board
I2S_FS_IN_N: R2317.2, X2312.26
I2S_FS_IN_S: R2337.2, X2332.26
I2S_FS_IN_W: R2327.2, X2322.26
I2S_FS_OUT: X2312.20, X2322.20, X2332.20; also elsewhere on the board
I2S_MCLK_OUT: X2312.19, X2322.19, X2332.19; also elsewhere on the board
I2S_SCK_IN_N: R2315.2, X2312.23
I2S_SCK_IN_S: R2335.2, X2332.23
I2S_SCK_IN_W: R2325.2, X2322.23
I2S_SCK_OUT: X2312.17, X2322.17, X2332.17; also elsewhere on the board
I2S_SD_IN_N: R2316.2, X2312.24
I2S_SD_IN_S: R2336.2, X2332.24
I2S_SD_IN_W: R2326.2, X2322.24
I2S_SD_OUT: X2312.18, X2322.18, X2332.18; also elsewhere on the board
MCU_I2C1_SCL: X2312.7; also elsewhere on the board
MCU_I2C1_SDA: X2312.8; also elsewhere on the board
MCU_I2C2_SCL: X2322.7; also elsewhere on the board
MCU_I2C2_SDA: X2322.8; also elsewhere on the board
MCU_I2C3_SCL: X2332.7; also elsewhere on the board
MCU_I2C3_SDA: X2332.8; also elsewhere on the board
MCU_SPI1_MISO: X2312.12, X2322.12, X2332.12; also elsewhere on the board
MCU_SPI1_MOSI: X2312.11, X2322.11, X2332.11; also elsewhere on the board
MCU_SPI1_SCK: X2312.13, X2322.13, X2332.13; also elsewhere on the board
MCU_WAKEUP: X2311.33, X2321.33, X2331.33; also elsewhere on the board
PB3: R2310.1; also elsewhere on the board
PB5: R2311.1; also elsewhere on the board
PB6: R2312.1; also elsewhere on the board
PB7: R2313.1; also elsewhere on the board
PB13: R2315.1, R2325.1, R2335.1; also elsewhere on the board
PD9: R2330.1; also elsewhere on the board
PD10: R2331.1; also elsewhere on the board
PD11: R2316.1, R2326.1, R2336.1; also elsewhere on the board
PD12: R2317.1, R2327.1, R2337.1; also elsewhere on the board
PD14: R2332.1; also elsewhere on the board
PD15: R2333.1; also elsewhere on the board
PE0: R2314.1; also elsewhere on the board
PE2: R2323.1; also elsewhere on the board
PE4: R2322.1; also elsewhere on the board
PE5: R2321.1; also elsewhere on the board
PF2: R2320.1; also elsewhere on the board
PF6: R2318.1; also elsewhere on the board
PF7: R2328.1; also elsewhere on the board
PF8: R2338.1; also elsewhere on the board
PF10: R2324.1; also elsewhere on the board
PG4: R2334.1; also elsewhere on the board
PN00: R2310.2, X2311.7
PN01: R2311.2, X2311.9
PN02: R2312.2, X2311.11
PN03: R2313.2, X2311.13
PS00: R2330.2, X2331.7
PS01: R2331.2, X2331.9
PS02: R2332.2, X2331.11
PS03: R2333.2, X2331.13
PW00: R2320.2, X2321.7
PW01: R2321.2, X2321.9
PW02: R2322.2, X2321.11
PW03: R2323.2, X2321.13
TIMCAP_N: R2318.2, X2311.31
TIMCAP_S: R2338.2, X2331.31
TIMCAP_W: R2328.2, X2321.31
UART1_CTS_IN: X2311.26; also elsewhere on the board
UART1_RTS_OUT: X2311.25; also elsewhere on the board
UART1_RX_IN: X2311.24; also elsewhere on the board
UART1_TX_OUT: X2311.23; also elsewhere on the board
UART2_CTS_IN: X2321.26; also elsewhere on the board
UART2_RTS_OUT: X2321.25; also elsewhere on the board
UART2_RX_IN: X2321.24; also elsewhere on the board
UART2_TX_OUT: X2321.23; also elsewhere on the board
UART3_CTS_IN: X2331.26; also elsewhere on the board
UART3_RTS_OUT: X2331.25; also elsewhere on the board
UART3_RX_IN: X2331.24; also elsewhere on the board
UART3_TX_OUT: X2331.23; also elsewhere on the board

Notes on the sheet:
North-West
West-South
South-East
North-East
West-North
South-West
Expansion connectors

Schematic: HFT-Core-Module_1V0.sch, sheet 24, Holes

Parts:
H2401, H2402, H2403, H2404: MOUNT-PAD-ROUND2.8; 2,8-PAD

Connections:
GND: H2401.B2,8, H2402.B2,8, H2403.B2,8, H2404.B2,8; also elsewhere on the board

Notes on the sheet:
Mounting holes

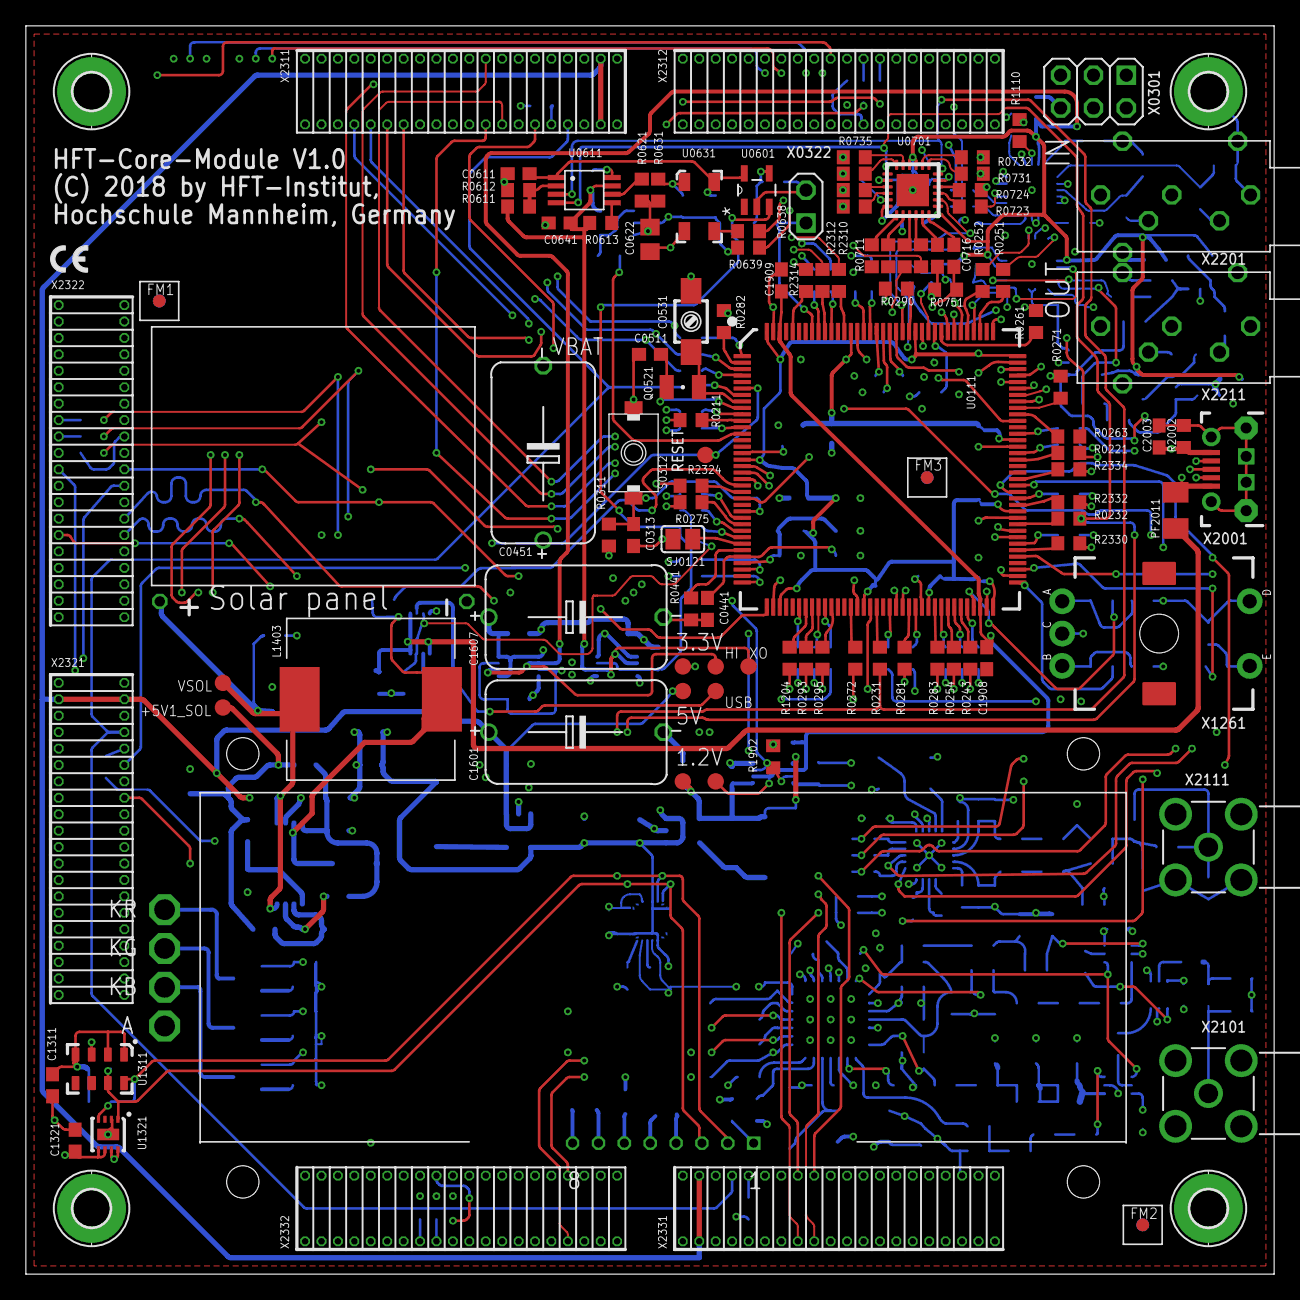
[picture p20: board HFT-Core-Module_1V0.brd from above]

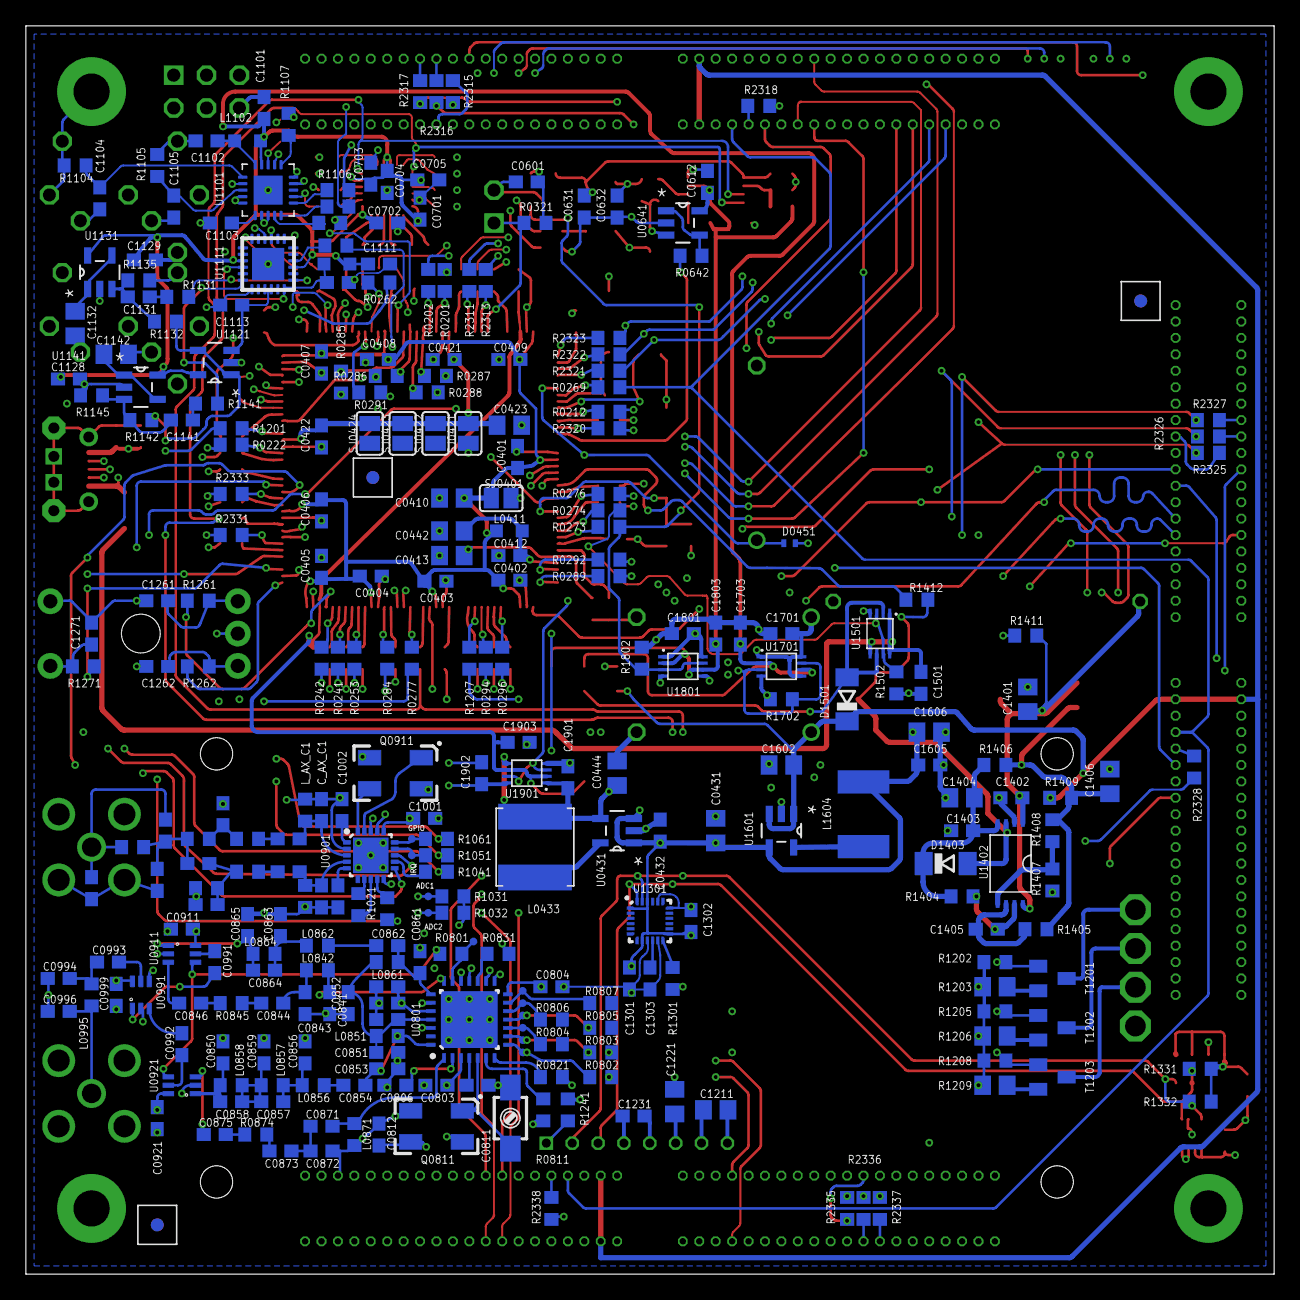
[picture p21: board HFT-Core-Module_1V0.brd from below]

Board: 4 copper layers, 96.5 x 96.5 mm, 402 parts (288 on the bottom side), 325 nets.

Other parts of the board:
FM1, FM2, FM3: FIDUCIAL_MARK_1MM

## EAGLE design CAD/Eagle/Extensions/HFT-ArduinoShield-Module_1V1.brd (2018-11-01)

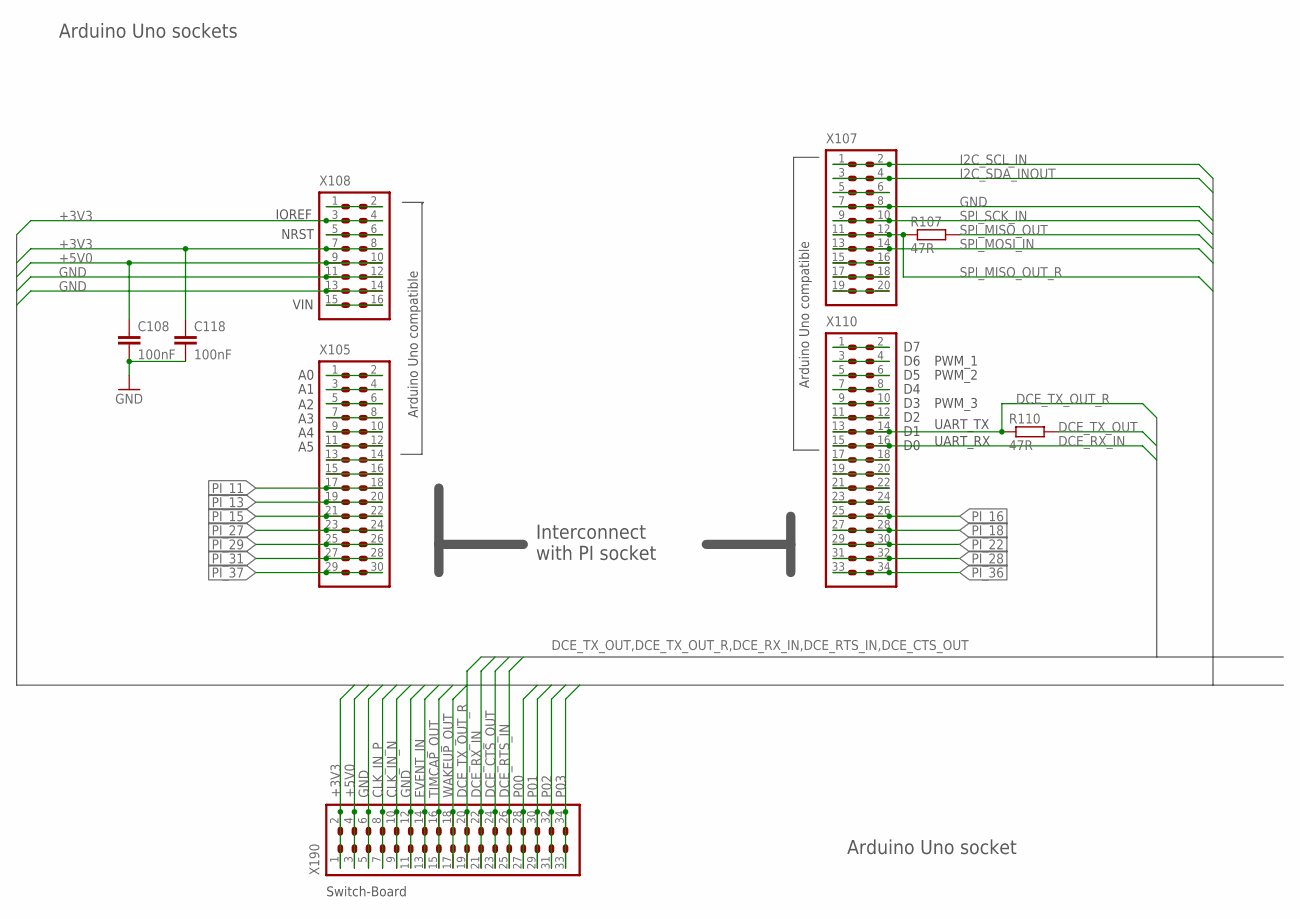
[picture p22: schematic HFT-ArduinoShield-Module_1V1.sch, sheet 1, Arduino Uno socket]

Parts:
C108, C118: 100nF; C0603
R107, R110: 47R; R0603
X105: 2X15_2MM56_SOCKET; 2X15
X107: 2X10_2MM56_SOCKET; 2X10
X108: 2X08_2MM56_SOCKET; 2X08
X110, X190: 2X17_2MM56_SOCKET; 2X17

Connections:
+3V3: C118.1, X108.3, X108.4, X108.7, X108.8, X190.1, X190.2; also elsewhere on the board
+5V0: C108.1, X108.9, X108.10, X190.3, X190.4; also elsewhere on the board
CLK_IN_N: X190.9, X190.10; also elsewhere on the board
CLK_IN_P: X190.7, X190.8; also elsewhere on the board
DCE_CTS_OUT: X190.23, X190.24; also elsewhere on the board
DCE_RTS_IN: X190.25, X190.26; also elsewhere on the board
DCE_RX_IN: X110.15, X110.16, X190.21, X190.22; also elsewhere on the board
DCE_TX_OUT: R110.2; also elsewhere on the board
DCE_TX_OUT_R: R110.1, X110.13, X110.14, X190.19, X190.20; also elsewhere on the board
EVENT_IN: X190.13, X190.14; also elsewhere on the board
GND: C108.2, C118.2, X107.7, X107.8, X108.11, X108.12, X108.13, X108.14, X190.5, X190.6, X190.11, X190.12; also elsewhere on the board
I2C_SCL_IN: X107.1, X107.2; also elsewhere on the board
I2C_SDA_INOUT: X107.3, X107.4; also elsewhere on the board
N105_01: X105.1, X105.2
N105_03: X105.3, X105.4
N105_05: X105.5, X105.6
N105_07: X105.7, X105.8
N105_09: X105.9, X105.10
N105_11: X105.11, X105.12
N105_13: X105.13, X105.14
N105_15: X105.15, X105.16
N107_05: X107.5, X107.6
N107_15: X107.15, X107.16
N107_17: X107.17, X107.18
N107_19: X107.19, X107.20
N108_01: X108.1, X108.2
N108_05: X108.5, X108.6
N108_15: X108.15, X108.16
N110_01: X110.1, X110.2
N110_03: X110.3, X110.4
N110_05: X110.5, X110.6
N110_07: X110.7, X110.8
N110_09: X110.9, X110.10
N110_11: X110.11, X110.12
N110_17: X110.17, X110.18
N110_19: X110.19, X110.20
N110_21: X110.21, X110.22
N110_23: X110.23, X110.24
P00: X190.27, X190.28; also elsewhere on the board
P01: X190.29, X190.30; also elsewhere on the board
P02: X190.31, X190.32; also elsewhere on the board
P03: X190.33, X190.34; also elsewhere on the board
PI_11: X105.17, X105.18; also elsewhere on the board
PI_13: X105.19, X105.20; also elsewhere on the board
PI_15: X105.21, X105.22; also elsewhere on the board
PI_16: X110.25, X110.26; also elsewhere on the board
PI_18: X110.27, X110.28; also elsewhere on the board
PI_22: X110.29, X110.30; also elsewhere on the board
PI_27: X105.23, X105.24; also elsewhere on the board
PI_28: X110.31, X110.32; also elsewhere on the board
PI_29: X105.25, X105.26; also elsewhere on the board
PI_31: X105.27, X105.28; also elsewhere on the board
PI_36: X110.33, X110.34; also elsewhere on the board
PI_37: X105.29, X105.30; also elsewhere on the board
SPI_MISO_OUT: R107.2; also elsewhere on the board
SPI_MISO_OUT_R: R107.1, X107.11, X107.12; also elsewhere on the board
SPI_MOSI_IN: X107.13, X107.14; also elsewhere on the board
SPI_SCK_IN: X107.9, X107.10; also elsewhere on the board
TIMCAP_OUT: X190.15, X190.16; also elsewhere on the board
WAKEUP_OUT: X190.17, X190.18; also elsewhere on the board

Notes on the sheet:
NRST
Arduino Uno compatible
Switch-Board
Arduino Uno socket
IOREF
VIN
UART_RX
UART_TX
PWM_1
PWM_2
PWM_3
Arduino Uno sockets
Interconnect with PI socket

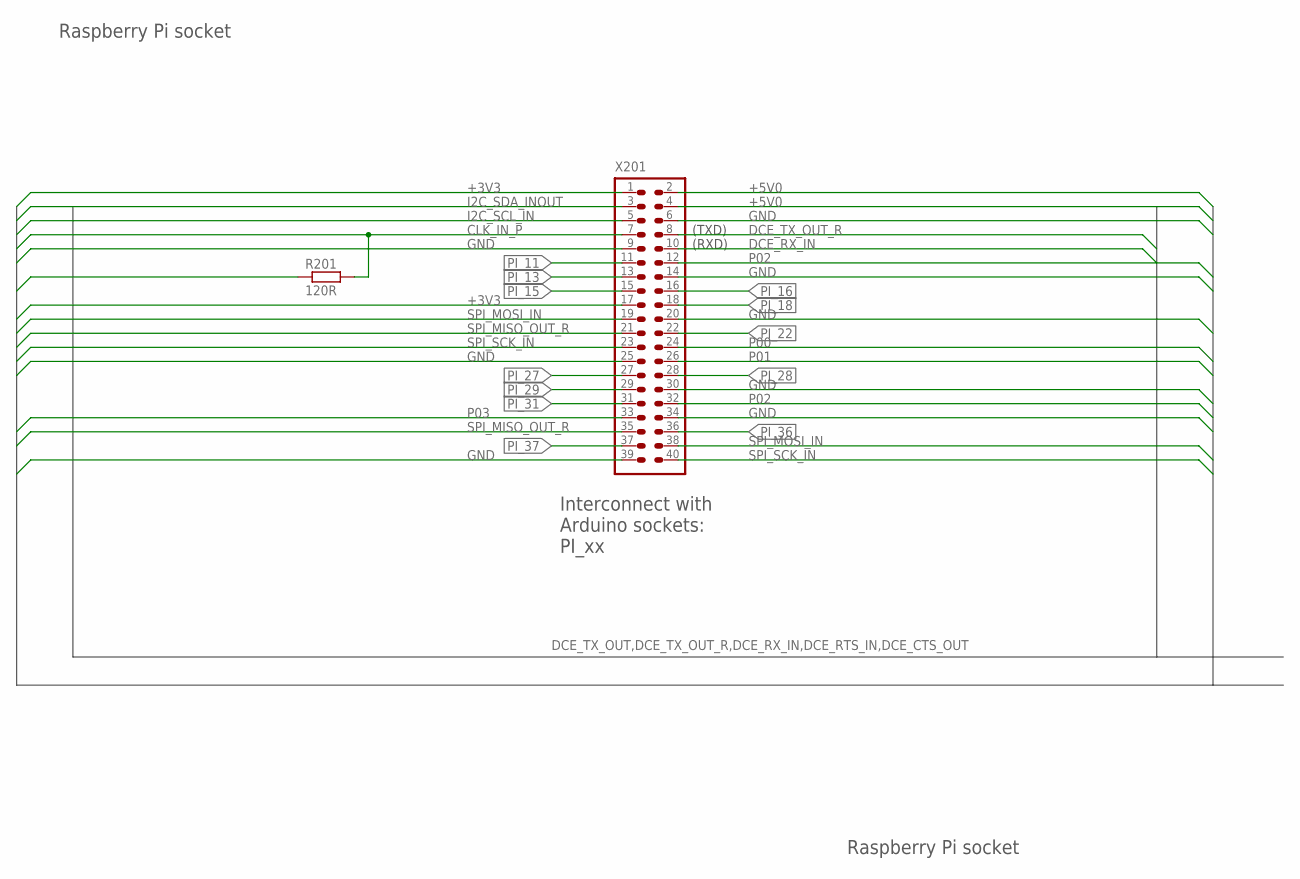
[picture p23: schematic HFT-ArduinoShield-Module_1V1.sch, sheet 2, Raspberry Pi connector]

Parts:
R201: 120R; R0603
X201: 2X20_2MM56_SOCKET; 2X20

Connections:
+3V3: X201.1, X201.17; also elsewhere on the board
+5V0: X201.2, X201.4; also elsewhere on the board
CLK_IN_N: R201.1; also elsewhere on the board
CLK_IN_P: R201.2, X201.7; also elsewhere on the board
DCE_RX_IN: X201.10; also elsewhere on the board
DCE_TX_OUT_R: X201.8; also elsewhere on the board
GND: X201.6, X201.9, X201.14, X201.20, X201.25, X201.30, X201.34, X201.39; also elsewhere on the board
I2C_SCL_IN: X201.5; also elsewhere on the board
I2C_SDA_INOUT: X201.3; also elsewhere on the board
P00: X201.24; also elsewhere on the board
P01: X201.26; also elsewhere on the board
P02: X201.12, X201.32; also elsewhere on the board
P03: X201.33; also elsewhere on the board
PI_11: X201.11; also elsewhere on the board
PI_13: X201.13; also elsewhere on the board
PI_15: X201.15; also elsewhere on the board
PI_16: X201.16; also elsewhere on the board
PI_18: X201.18; also elsewhere on the board
PI_22: X201.22; also elsewhere on the board
PI_27: X201.27; also elsewhere on the board
PI_28: X201.28; also elsewhere on the board
PI_29: X201.29; also elsewhere on the board
PI_31: X201.31; also elsewhere on the board
PI_36: X201.36; also elsewhere on the board
PI_37: X201.37; also elsewhere on the board
SPI_MISO_OUT_R: X201.21, X201.35; also elsewhere on the board
SPI_MOSI_IN: X201.19, X201.38; also elsewhere on the board
SPI_SCK_IN: X201.23, X201.40; also elsewhere on the board

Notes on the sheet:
Raspberry Pi socket
(TXD)
(RXD)
Interconnect with Arduino sockets: PI_xx


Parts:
X301, X302: 2X20/90_1MM27_HARWIN_M50-3902042_HEADER

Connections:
+3V3: X301.3, X301.4, X302.37, X302.38; also elsewhere on the board
+5V0: X301.37, X301.38; also elsewhere on the board
CLK_IN_N: X302.4; also elsewhere on the board
CLK_IN_P: X302.3; also elsewhere on the board
DCE_CTS_OUT: X301.26; also elsewhere on the board
DCE_RTS_IN: X301.25; also elsewhere on the board
DCE_RX_IN: X301.23; also elsewhere on the board
DCE_TX_OUT: X301.24; also elsewhere on the board
EVENT_IN: X301.29; also elsewhere on the board
GND: X301.1, X301.2, X301.5, X301.6, X301.8, X301.10, X301.12, X301.14, X301.21, X301.22, X301.27, X301.28, X301.30, X301.32, X301.34, X301.35, X301.36, X301.39, X301.40, X302.1, X302.2, X302.5, X302.6, X302.9, X302.10, X302.14, X302.15, X302.16, X302.21, X302.22, X302.25, X302.27, X302.28, X302.39, X302.40; also elsewhere on the board
I2C_SCL_IN: X302.7; also elsewhere on the board
I2C_SDA_INOUT: X302.8; also elsewhere on the board
I2S_A_FS_IN: X302.20
I2S_A_MCLK_IN: X302.19
I2S_A_SCK_IN: X302.17
I2S_A_SD_IN: X302.18
I2S_B_FS_OUT: X302.26
I2S_B_SCK_OUT: X302.23
I2S_B_SD_OUT: X302.24
P00: X301.7; also elsewhere on the board
P01: X301.9; also elsewhere on the board
P02: X301.11; also elsewhere on the board
P03: X301.13; also elsewhere on the board
SPI_MISO_OUT: X302.12; also elsewhere on the board
SPI_MOSI_IN: X302.11; also elsewhere on the board
SPI_SCK_IN: X302.13; also elsewhere on the board
TIMCAP_OUT: X301.31; also elsewhere on the board
WAKEUP_OUT: X301.33; also elsewhere on the board

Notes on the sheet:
Left
Right
Expansion connectors
Looking onto the HEADER
Expansion connectors to the HFT-Core-Module

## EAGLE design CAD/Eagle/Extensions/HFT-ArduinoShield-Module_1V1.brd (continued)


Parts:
H401, H402, H403, H404: MOUNT-PAD-ROUND2.8; 2,8-PAD

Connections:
GND: H401.B2,8, H402.B2,8, H403.B2,8, H404.B2,8; also elsewhere on the board

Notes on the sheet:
Board & mounting holes
Left
Right


Board: 4 copper layers, 80.0 x 96.5 mm, 17 parts (1 on the bottom side), 60 nets.

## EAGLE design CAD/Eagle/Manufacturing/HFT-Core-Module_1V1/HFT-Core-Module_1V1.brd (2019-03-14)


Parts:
R0121: 0R; R0402
U0111: STM32L4Z_144PIN_SMPS; LQFP144

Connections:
GND: R0121.1, U0111.16 (VSS1), U0111.38 (VSS2), U0111.51 (VSS3), U0111.61 (VSS4), U0111.71 (VSS5), U0111.83 (VSS6), U0111.94 (VSS7), U0111.107 (VSS8), U0111.120 (VSS9), U0111.130 (VSS10), U0111.143 (VSS11); also elsewhere on the board
MCU_NRST: U0111.25 (NRST); also elsewhere on the board
MCU_VBAT: U0111.6 (VBAT); also elsewhere on the board
MCU_VDD: U0111.17 (VDD1), U0111.39 (VDD2), U0111.52 (VDD3), U0111.62 (VDD4), U0111.72 (VDD5), U0111.84 (VDD6), U0111.108 (VDD7), U0111.121 (VDD8), U0111.144 (VDD9); also elsewhere on the board
MCU_VDD12: U0111.70 (VDD12_1), U0111.142 (VDD12_2); also elsewhere on the board
MCU_VDDA: U0111.33 (VDDA); also elsewhere on the board
MCU_VDDIO2: U0111.95 (VDDIO2_1), U0111.131 (VDDIO2_2); also elsewhere on the board
MCU_VREF_M: U0111.31 (VREF-); also elsewhere on the board
MCU_VREF_P: U0111.32 (VREF+); also elsewhere on the board
MCU_VSSA: R0121.2, U0111.30 (VSSA)
PA0: U0111.34 (PA0_WU); also elsewhere on the board
PA1: U0111.35 (PA1); also elsewhere on the board
PA2: U0111.36 (PA2_WU); also elsewhere on the board
PA3: U0111.37 (PA3); also elsewhere on the board
PA4: U0111.40 (PA4)
PA5: U0111.41 (PA5); also elsewhere on the board
PA6: U0111.42 (PA6); also elsewhere on the board
PA7: U0111.43 (PA7); also elsewhere on the board
PA8: U0111.100 (PA8); also elsewhere on the board
PA9: U0111.101 (PA9); also elsewhere on the board
PA10: U0111.102 (PA10); also elsewhere on the board
PA12PA11_N: U0111.103 (PA11); also elsewhere on the board
PA12PA11_P: U0111.104 (PA12); also elsewhere on the board
PA13: U0111.105 (PA13); also elsewhere on the board
PA14: U0111.109 (PA14); also elsewhere on the board
PA15: U0111.110 (PA15)
PB0: U0111.46 (PB0); also elsewhere on the board
PB1: U0111.47 (PB1); also elsewhere on the board
PB2: U0111.48 (PB2)
PB3: U0111.132 (PB3); also elsewhere on the board
PB4: U0111.133 (PB4)
PB5: U0111.134 (PB5); also elsewhere on the board
PB6: U0111.135 (PB6); also elsewhere on the board
PB7: U0111.136 (PB7); also elsewhere on the board
PB8: U0111.138 (PB8)
PB9: U0111.139 (PB9)
PB10: U0111.69 (PB10)
PB12: U0111.73 (PB12)
PB13: U0111.74 (PB13); also elsewhere on the board
PB14: U0111.75 (PB14)
PB15: U0111.76 (PB15); also elsewhere on the board
PC0: U0111.26 (PC0); also elsewhere on the board
PC1: U0111.27 (PC1); also elsewhere on the board
PC2: U0111.28 (PC2); also elsewhere on the board
PC3: U0111.29 (PC3); also elsewhere on the board
PC4: U0111.44 (PC4)
PC5: U0111.45 (PC5_WU); also elsewhere on the board
PC6: U0111.96 (PC6); also elsewhere on the board
PC7: U0111.97 (PC7); also elsewhere on the board
PC8: U0111.98 (PC8); also elsewhere on the board
PC9: U0111.99 (PC9); also elsewhere on the board
PC10: U0111.111 (PC10); also elsewhere on the board
PC11: U0111.112 (PC11); also elsewhere on the board
PC12: U0111.113 (PC12); also elsewhere on the board
PC13: U0111.7 (PC13_WU); also elsewhere on the board
PC14_OSC32_IN: U0111.8 (PC14_OSC32_IN); also elsewhere on the board
PC15_OSC32_OUT: U0111.9 (PC15_OSC32_OUT); also elsewhere on the board
PD0: U0111.114 (PD0)
PD1: U0111.115 (PD1); also elsewhere on the board
PD2: U0111.116 (PD2); also elsewhere on the board
PD3: U0111.117 (PD3); also elsewhere on the board
PD4: U0111.118 (PD4)
PD5: U0111.119 (PD5)
PD6: U0111.122 (PD6)
PD7: U0111.123 (PD7); also elsewhere on the board
PD8: U0111.77 (PD8); also elsewhere on the board
PD9: U0111.78 (PD9); also elsewhere on the board
PD10: U0111.79 (PD10); also elsewhere on the board
PD11: U0111.80 (PD11); also elsewhere on the board
PD12: U0111.81 (PD12); also elsewhere on the board
PD13: U0111.82 (PD13)
PD14: U0111.85 (PD14); also elsewhere on the board
PD15: U0111.86 (PD15); also elsewhere on the board
PE0: U0111.140 (PE0)
PE1: U0111.141 (PE1)
PE2: U0111.1 (PE2)
PE3: U0111.2 (PE3); also elsewhere on the board
PE4: U0111.3 (PE4); also elsewhere on the board
PE5: U0111.4 (PE5); also elsewhere on the board
PE6: U0111.5 (PE6_WU); also elsewhere on the board
PE7: U0111.58 (PE7); also elsewhere on the board
PE8: U0111.59 (PE8); also elsewhere on the board
PE9: U0111.60 (PE9); also elsewhere on the board
PE10: U0111.63 (PE10); also elsewhere on the board
PE11: U0111.64 (PE11); also elsewhere on the board
PE12: U0111.65 (PE12); also elsewhere on the board
PE13: U0111.66 (PE13); also elsewhere on the board
PE14: U0111.67 (PE14); also elsewhere on the board
PE15: U0111.68 (PE15); also elsewhere on the board
PF0: U0111.10 (PF0); also elsewhere on the board
PF1: U0111.11 (PF1); also elsewhere on the board
PF2: U0111.12 (PF2)
PF3: U0111.13 (PF3); also elsewhere on the board
PF4: U0111.14 (PF4); also elsewhere on the board
PF5: U0111.15 (PF5); also elsewhere on the board
PF6: U0111.18 (PF6); also elsewhere on the board
PF7: U0111.19 (PF7); also elsewhere on the board
PF8: U0111.20 (PF8); also elsewhere on the board
PF9: U0111.21 (PF9); also elsewhere on the board
PF10: U0111.22 (PF10); also elsewhere on the board
PF11: U0111.49 (PF11); also elsewhere on the board
PF12: U0111.50 (PF12); also elsewhere on the board
PF13: U0111.53 (PF13); also elsewhere on the board
PF14: U0111.54 (PF14); also elsewhere on the board
PF15: U0111.55 (PF15); also elsewhere on the board
PG0: U0111.56 (PG0); also elsewhere on the board
PG1: U0111.57 (PG1); also elsewhere on the board
PG2: U0111.87 (PG2)
PG3: U0111.88 (PG3); also elsewhere on the board
PG4: U0111.89 (PG4); also elsewhere on the board
PG5: U0111.90 (PG5); also elsewhere on the board
PG6: U0111.91 (PG6); also elsewhere on the board
PG7: U0111.92 (PG7); also elsewhere on the board
PG8: U0111.93 (PG8); also elsewhere on the board
PG9: U0111.124 (PG9); also elsewhere on the board
PG10: U0111.125 (PG10); also elsewhere on the board
PG11: U0111.126 (PG11); also elsewhere on the board
PG12: U0111.127 (PG12); also elsewhere on the board
PG13: U0111.128 (PG13); also elsewhere on the board
PG14: U0111.129 (PG14); also elsewhere on the board
PH0: U0111.23 (PH0_OSC_IN); also elsewhere on the board
PH1: U0111.24 (PH1_OSC_OUT)
PH3_BOOT0: U0111.137 (PH3_BOOT0); also elsewhere on the board
VDDUSB: U0111.106 (VDDUSB); also elsewhere on the board

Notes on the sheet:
STM32L496ZGT6P
MCU


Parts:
C0213: 100nF; C0402
R0201, R0202: 220kR; R0402
R0222: 33kR; R0402
S0212: KSR223GLFG; KSR223G_SMD_1POL
X0201: 2X05_1MM27_SHROUDED_CORTEX_JTAG_SWD"; 2X05_1MM27_SHROUDED_CORTEX_JTAG_SWD
X0221: HEADER-1X2; 1X02

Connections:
+3V3: R0202.2, X0201.1, X0221.1; also elsewhere on the board
GND: C0213.2, R0201.1, R0222.1, S0212.1, X0201.3, X0201.5, X0201.9; also elsewhere on the board
MCU_NRST: C0213.1, S0212.2 (S), X0201.10; also elsewhere on the board
PA13: R0202.1, X0201.2; also elsewhere on the board
PA14: R0201.2, X0201.4; also elsewhere on the board
PH3_BOOT0: R0222.2, X0221.2; also elsewhere on the board

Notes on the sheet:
SWDIO
SWCLK
RESET
BOOT0
SW-DEBUG
SWD header
Boot configuration
RESET button
nRESET
MCU Reset & SWD
no PU/PD
Iq=0uA


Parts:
C0311: 22pF; C0402
C0331: JR200; 3MM2_X_2MM5
C0332: 18pF; C0402
Q0321: ABS07-32.768KHZ; ABS07

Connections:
GND: C0311.2, C0331.+ (A), C0332.2; also elsewhere on the board
PC14_OSC32_IN: C0331.- (E), C0332.1, Q0321.2; also elsewhere on the board
PC15_OSC32_OUT: C0311.1, Q0321.1; also elsewhere on the board

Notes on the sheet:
4p5F..20pF
MCU LSE Crystal 32.768 kHz
MCU: LSE 32.768 kHz


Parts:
C0401, C0402, C0403, C0404, C0405, C0406, C0407, C0408, C0409, C0421, C0422, C0441: 100nF; C0402
C0410, C0423: 4.7uF; C0402
C0412: 10nF; C0402
C0413, C0442: 1uF; C0402
C0451: 1F_6V_SCMR18H105MRBB0; C115-080X160_POL
L0411: 10uH; L0603
R0401, R0421, R0441: 0R; R0402
TP_VBAT: PTR1B1,27; B1,27

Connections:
+3V3: R0401.1, R0421.2; also elsewhere on the board
GND: C0401.2, C0402.2, C0403.2, C0404.2, C0405.2, C0406.2, C0407.2, C0408.2, C0409.2, C0410.2, C0412.2, C0413.2, C0421.1, C0422.2, C0423.2, C0441.1, C0442.1, C0451.-, R0441.1; also elsewhere on the board
MCU_VBAT: C0451.+, TP_VBAT.TP; also elsewhere on the board
MCU_VDD: C0401.1, C0402.1, C0403.1, C0404.1, C0405.1, C0406.1, C0407.1, C0408.1, C0409.1, C0410.1, L0411.1, R0401.2; also elsewhere on the board
MCU_VDDA: C0412.1, C0413.1, L0411.2; also elsewhere on the board
MCU_VDDIO2: C0421.2, C0422.1, C0423.1, R0421.1; also elsewhere on the board
MCU_VREF_M: R0441.2; also elsewhere on the board
MCU_VREF_P: C0441.2, C0442.2; also elsewhere on the board

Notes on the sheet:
MCU VDDIO2 selection
MCU VDDA
MCU VREF
MCU VBAT
MCU power distribution


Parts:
C0521: 100nF; C0402
R0521: 100kR; R0402
R0531: 47R; R0402
R0581, R0582, R0583, R0584, R0585, R0586, R0587, R0588, R0589, R0590, R0591, R0592, R0593, R0594, R0595, R0596: 1MR; R0402
R0611, R0612: 1.0kR; R0402
U0521: PCAL6416APW; TSSOP24_SOT355-1

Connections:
+3V3: C0521.1, R0521.2, R0611.2, R0612.2, U0521.2 (VDD_I2C), U0521.24 (VDD_P); also elsewhere on the board
GND: C0521.2, R0581.2, R0582.2, R0583.2, R0584.2, R0585.2, R0586.2, R0587.2, R0588.2, R0589.2, R0590.2, R0591.2, R0592.2, R0593.2, R0594.2, R0595.2, R0596.2, U0521.12 (VSS), U0521.21 (ADDR); also elsewhere on the board
I2C1_SCL: R0612.1, U0521.22 (SCL); also elsewhere on the board
I2C1_SDA: R0611.1, U0521.23 (SDA); also elsewhere on the board
PEXPA_INTN: R0531.2, U0521.1 (!INT)
PEXPA_P0_0_R: R0581.1, U0521.4 (P0_0); also elsewhere on the board
PEXPA_P0_1_R: R0582.1, U0521.5 (P0_1); also elsewhere on the board
PEXPA_P0_2_R: R0583.1, U0521.6 (P0_2); also elsewhere on the board
PEXPA_P0_3_R: R0584.1, U0521.7 (P0_3); also elsewhere on the board
PEXPA_P0_4_R: R0585.1, U0521.8 (P0_4); also elsewhere on the board
PEXPA_P0_5_R: R0586.1, U0521.9 (P0_5); also elsewhere on the board
PEXPA_P0_6_R: R0587.1, U0521.10 (P0_6); also elsewhere on the board
PEXPA_P0_7_R: R0588.1, U0521.11 (P0_7); also elsewhere on the board
PEXPA_P1_0_R: R0589.1, U0521.13 (P1_0); also elsewhere on the board
PEXPA_P1_1_R: R0590.1, U0521.14 (P1_1); also elsewhere on the board
PEXPA_P1_2_R: R0591.1, U0521.15 (P1_2); also elsewhere on the board
PEXPA_P1_3_R: R0592.1, U0521.16 (P1_3); also elsewhere on the board
PEXPA_P1_4_R: R0593.1, U0521.17 (P1_4); also elsewhere on the board
PEXPA_P1_5_R: R0594.1, U0521.18 (P1_5); also elsewhere on the board
PEXPA_P1_6_R: R0595.1, U0521.19 (P1_6); also elsewhere on the board
PEXPA_P1_7_R: R0596.1, U0521.20 (P1_7); also elsewhere on the board
PEXPA_RESET: R0521.1, U0521.3 (!RESET)
PF3: R0531.1; also elsewhere on the board

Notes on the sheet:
I2C1 Port Expander-A I2C1 addr: 0x20
I2C1 Expander-A Pull-Down
I2C1 Port Expander-A
Iq=6.5uA
I_MAX=16 x 3.3uA
MCU_EXTI3_PEXPA
VBUS_HARD_SW_EN
+3V3_XO_EN
+3V3_XO_PA_EN
+3V3_HICUR_EN
PMIC_VDD12_EN
MCU_VDD12_SW_EN
HSE_XO_SW_EN
HSE_PLL_SW_EN
BNO085_BOOTN
BNO085_NRST
GPS_SW_EN
LIPO_PSEL
LIPO_OTG_R
SX_NRESET
LCD_NRST
SW_PWR
out
I2C1 Termination


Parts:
C0621: 100nF; C0402
R0621: 100kR; R0402
R0631: 47R; R0402
R0681, R0682, R0683, R0684, R0685, R0686, R0687, R0688, R0689, R0693, R0694, R0695, R0696: 1MR; R0402
U0621: PCAL6416APW; TSSOP24_SOT355-1

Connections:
+3V3: C0621.1, R0621.2, U0621.2 (VDD_I2C), U0621.21 (ADDR), U0621.24 (VDD_P); also elsewhere on the board
GND: C0621.2, R0681.2, R0682.2, R0683.2, R0684.2, R0685.2, R0686.2, R0687.2, R0688.2, R0689.2, R0693.2, R0694.2, R0695.2, R0696.2, U0621.12 (VSS); also elsewhere on the board
I2C1_SCL: U0621.22 (SCL); also elsewhere on the board
I2C1_SDA: U0621.23 (SDA); also elsewhere on the board
PEXPB_INTN: R0631.2, U0621.1 (!INT)
PEXPB_P0_0_R: R0681.1, U0621.4 (P0_0)
PEXPB_P0_1_R: R0682.1, U0621.5 (P0_1)
PEXPB_P0_2_R: R0683.1, U0621.6 (P0_2); also elsewhere on the board
PEXPB_P0_3_R: R0684.1, U0621.7 (P0_3); also elsewhere on the board
PEXPB_P0_4_R: R0685.1, U0621.8 (P0_4); also elsewhere on the board
PEXPB_P0_5_R: R0686.1, U0621.9 (P0_5); also elsewhere on the board
PEXPB_P0_6_R: R0687.1, U0621.10 (P0_6)
PEXPB_P0_7_R: R0688.1, U0621.11 (P0_7)
PEXPB_P1_0_R: R0689.1, U0621.13 (P1_0); also elsewhere on the board
PEXPB_P1_1_R: U0621.14 (P1_1); also elsewhere on the board
PEXPB_P1_2_R: U0621.15 (P1_2); also elsewhere on the board
PEXPB_P1_3_R: U0621.16 (P1_3); also elsewhere on the board
PEXPB_P1_4_R: R0693.1, U0621.17 (P1_4); also elsewhere on the board
PEXPB_P1_5_R: R0694.1, U0621.18 (P1_5); also elsewhere on the board
PEXPB_P1_6_R: R0695.1, U0621.19 (P1_6); also elsewhere on the board
PEXPB_P1_7_R: R0696.1, U0621.20 (P1_7); also elsewhere on the board
PEXPB_RESET: R0621.1, U0621.3 (!RESET)
PF4: R0631.1; also elsewhere on the board
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

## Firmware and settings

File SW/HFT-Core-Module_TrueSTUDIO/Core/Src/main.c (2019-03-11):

/**
  ******************************************************************************
  * @file           : main.c
  * @brief          : Main program body
  ******************************************************************************
  * This notice applies to any and all portions of this file
  * that are not between comment pairs USER CODE BEGIN and
  * USER CODE END. Other portions of this file, whether 
  * inserted by the user or by software development tools
  * are owned by their respective copyright owners.
  *
  * Copyright (c) 2018 STMicroelectronics International N.V. 
  * All rights reserved.
  *
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
  ******************************************************************************
  */
/* Includes ------------------------------------------------------------------*/
#include "main.h"
#include "stm32l4xx_hal.h"
#include "cmsis_os.h"
#include "adc.h"
#include "crc.h"
#include "dfsdm.h"
#include "dma.h"
#include "i2c.h"
#include "rng.h"
#include "rtc.h"
#include "sai.h"
#include "spi.h"
#include "tim.h"
#include "usart.h"
#include "usb_device.h"
#include "gpio.h"

/* USER CODE BEGIN Includes */
#include "FreeRTOS.h"

#include <stddef.h>
#include <stdio.h>
#include <math.h>
#include <task_USB.h>
#include "device_adc.h"
#include "bus_i2c.h"
#include "bus_spi.h"
#include "task_Controller.h"
#include "task_TCXO_20MHz.h"
#include "task_Si5338.h"
#include "task_Audio_ADC.h"
#include "task_Audio_DAC.h"
#include "task_AX5243.h"
#include "task_SX1276.h"


#define  PERIOD_VALUE       (uint32_t)(16000UL - 1)                                             /* Period Value = 1ms */
#define  PULSE_RED_VALUE    (uint32_t)(PERIOD_VALUE * 75 / 100)                                 /* Capture Compare 1 Value  */
#define  PULSE_GREEN_VALUE  (uint32_t)(PERIOD_VALUE * 25 / 100)                                 /* Capture Compare 2 Value  */
#define  PULSE_BLUE_VALUE   (uint32_t)(PERIOD_VALUE * 50 / 100)                                 /* Capture Compare 3 Value  */

/* USER CODE END Includes */


/* USER CODE BEGIN PV */
#if !defined(__MCO1_CLK_ENABLE)
# define __MCO1_CLK_ENABLE()          __HAL_RCC_GPIOA_CLK_ENABLE()
# define __MCO1_CLK_DISABLE()         __HAL_RCC_GPIOA_CLK_DISABLE()
# define MCO1_GPIO_PORT               GPIOA
# define MCO1_PIN                     GPIO_PIN_8
#endif

extern EventGroupHandle_t             adcEventGroupHandle;
extern EventGroupHandle_t             extiEventGroupHandle;
extern EventGroupHandle_t             globalEventGroupHandle;
extern EventGroupHandle_t             spiEventGroupHandle;
extern EventGroupHandle_t             usbToHostEventGroupHandle;

extern TIM_HandleTypeDef              htim2;
extern uint32_t                       uwTick;

extern uint8_t                        i2c4TxBuffer[I2C_TXBUFSIZE];
extern uint8_t                        i2c4RxBuffer[I2C_RXBUFSIZE];

extern uint8_t                        spi3TxBuffer[SPI3_BUFFERSIZE];
extern uint8_t                        spi3RxBuffer[SPI3_BUFFERSIZE];

ENABLE_MASK_t                         g_enableMsk;
MON_MASK_t                            g_monMsk;
SYSCLK_CONFIG_t                       g_main_SYSCLK_CONFIG    = SYSCLK_CONFIG_04MHz_MSI;

/* Typical values for 24 MHz MSI configuration */
uint32_t                              g_main_HSE_VALUE        =   20000000UL;
uint32_t                              g_main_HSE_START_MS     =        100UL;
uint32_t                              g_main_MSI_VALUE        =    4000000UL;
uint32_t                              g_main_HSI_VALUE        =   16000000UL;
uint32_t                              g_main_HSI48_VALUE      =   48000000UL;
uint32_t                              g_main_LSI_VALUE        =      32000UL;
uint32_t                              g_main_LSE_VALUE        =      32768UL;
uint32_t                              g_main_LSE_START_MS     =       5000UL;
uint32_t                              g_main_i2c1_timing      = 0x00000000UL;
uint32_t                              g_main_i2c2_timing      = 0x00000000UL;
uint32_t                              g_main_i2c3_timing      = 0x00000000UL;
uint32_t                              g_main_i2c4_timing      = 0x00000000UL;
uint32_t                              g_main_adc1_clkpresclr  = ADC_CLOCK_ASYNC_DIV1;
uint32_t                              g_main_adc3_clkpresclr  = ADC_CLOCK_ASYNC_DIV1;
uint8_t                               g_main_PCLK1_Prescaler  = 1U;


/* Counter Prescaler value */
uint32_t                              uhPrescalerValue        = 0;

volatile uint32_t                     g_rtc_ssr_last          = 0UL;

static uint64_t                       s_timerLast_us          = 0ULL;
static uint64_t                       s_timerStart_us         = 0ULL;

/* USER CODE END PV */

void SystemClock_Config(void);
void MX_FREERTOS_Init(void);

/* USER CODE BEGIN PFP */

/* USER CODE END PFP */

/* USER CODE BEGIN 0 */
uint32_t crcCalc(const uint32_t* ptr, uint32_t len)
{
  return HAL_CRC_Calculate(&hcrc, (uint32_t*) ptr, len);
}


uint8_t sel_u8_from_u32(uint32_t in_u32, uint8_t sel)
{
  return 0xff & (in_u32 >> (sel << 3));
}

void mainCalcFloat2IntFrac(float val, uint8_t fracCnt, int32_t* outInt, uint32_t* outFrac)
{
  const uint8_t isNeg = val >= 0 ?  0U : 1U;

  if (!outInt || !outFrac) {
    return;
  }

  *outInt = (int32_t) val;
  val -= *outInt;

  if (isNeg) {
    val = -val;
  }
  val *= pow(10, fracCnt);
  *outFrac = (uint32_t) (val + 0.5f);
}

void mainPowerSwitchDo(POWERSWITCH_ENUM_t sw, uint8_t enable)
{
  __HAL_RCC_GPIOC_CLK_ENABLE();
  __asm volatile( "NOP" );

  switch (sw) {
  case POWERSWITCH__USB_SW:
    /* Port: PC2 */
    HAL_GPIO_WritePin(MCU_OUT_VUSB_EN_GPIO_Port, MCU_OUT_VUSB_EN_Pin, (enable ?  GPIO_PIN_SET : GPIO_PIN_RESET));
    break;

  case POWERSWITCH__3V3_HICUR:
    /* Port: PC1 */
    if (enable) {
      /* Connect chip select with SPI bus signal */
      HAL_GPIO_WritePin(MCU_OUT_AUDIO_ADC_SEL_GPIO_Port, MCU_OUT_AUDIO_ADC_SEL_Pin, GPIO_PIN_SET);
      HAL_GPIO_WritePin(MCU_OUT_AUDIO_DAC_SEL_GPIO_Port, MCU_OUT_AUDIO_DAC_SEL_Pin, GPIO_PIN_SET);

      /* Power switch: 3V3_HICUR */
      HAL_GPIO_WritePin(MCU_OUT_HICUR_EN_GPIO_Port, MCU_OUT_HICUR_EN_Pin, GPIO_PIN_SET);

      /* Disable RESET */
      HAL_GPIO_WritePin(MCU_OUT_AUDIO_ADC_nRESET_GPIO_Port, MCU_OUT_AUDIO_ADC_nRESET_Pin, GPIO_PIN_SET);

    } else {
      /* Enable RESET */
      HAL_GPIO_WritePin(MCU_OUT_AUDIO_ADC_nRESET_GPIO_Port, MCU_OUT_AUDIO_ADC_nRESET_Pin, GPIO_PIN_RESET);

      /* Power switch: 3V3_HICUR */
      HAL_GPIO_WritePin(MCU_OUT_HICUR_EN_GPIO_Port, MCU_OUT_HICUR_EN_Pin, GPIO_PIN_RESET);

      /* No energy through select pins during power off */
      HAL_GPIO_WritePin(MCU_OUT_AUDIO_ADC_SEL_GPIO_Port, MCU_OUT_AUDIO_ADC_SEL_Pin, GPIO_PIN_RESET);
      HAL_GPIO_WritePin(MCU_OUT_AUDIO_DAC_SEL_GPIO_Port, MCU_OUT_AUDIO_DAC_SEL_Pin, GPIO_PIN_RESET);
    }
    break;

  case POWERSWITCH__3V3_XO:
    /* Port: PC3 */
    if (enable) {
      HAL_GPIO_WritePin(MCU_OUT_20MHZ_EN_GPIO_Port, MCU_OUT_20MHZ_EN_Pin, GPIO_PIN_SET);

    } else {
      HAL_GPIO_WritePin(MCU_OUT_20MHZ_EN_GPIO_Port, MCU_OUT_20MHZ_EN_Pin, GPIO_PIN_RESET);
    }
    break;

  case POWERSWITCH__1V2_DCDC:
    /* V1.0: no hardware support */
    return;

  case POWERSWITCH__1V2_SW:
    /* SMPS handling */
    if (enable)
    {
      /* Port: PC0 */
      HAL_GPIO_WritePin(MCU_OUT_VDD12_EN_GPIO_Port, MCU_OUT_VDD12_EN_Pin, GPIO_PIN_SET);

      osDelay(10UL);

      /* Scale1: 1.2V up to 80MHz */
      /* Scale2: 1.0V up to 24MHz */
      HAL_PWREx_ControlVoltageScaling(PWR_REGULATOR_VOLTAGE_SCALE2);

    } else {
      /* Scale1: 1.2V up to 80MHz */
      /* Scale2: 1.0V up to 24MHz */
      HAL_PWREx_ControlVoltageScaling(PWR_REGULATOR_VOLTAGE_SCALE1);

      osDelay(100UL);

      /* Port: PC0 */
      HAL_GPIO_WritePin(MCU_OUT_VDD12_EN_GPIO_Port, MCU_OUT_VDD12_EN_Pin, GPIO_PIN_RESET);
    }
    break;

  case POWERSWITCH__BAT_SW:
    if (enable) {
      HAL_PWREx_EnableBatteryCharging(PWR_BATTERY_CHARGING_RESISTOR_5);

    } else {
      HAL_PWREx_DisableBatteryCharging();
    }
    break;

  case POWERSWITCH__BAT_HICUR:
    if (enable) {
      HAL_PWREx_EnableBatteryCharging(PWR_BATTERY_CHARGING_RESISTOR_1_5);

    } else {
      HAL_PWREx_EnableBatteryCharging(PWR_BATTERY_CHARGING_RESISTOR_5);
    }
    break;

  default:
    { }
  }

  __HAL_RCC_GPIOC_CLK_DISABLE();
}

void mainPowerSwitchInit(void)
{
  /* Connect Vusb with +5V0 */
  mainPowerSwitchDo(POWERSWITCH__USB_SW,    1U);

  /* Disable high current system */
  mainPowerSwitchDo(POWERSWITCH__3V3_HICUR, 0U);

  /* Disable TCXO - enabled by i2cI2c4Si5338Init() on request */
  mainPowerSwitchDo(POWERSWITCH__3V3_XO,    0U);

  /* Enable SMPS */
  {
//  PowerSwitchDo(POWERSWITCH__1V2_DCDC,
//      1U);
//  for (uint16_t i = 10000; i; i--) ;
    mainPowerSwitchDo(POWERSWITCH__1V2_SW,  1U);

    /*
     * SMPS DC/DC converter enabled but disconnected:
     *  --> Quiescent   current: 3.0 mA
     *  --> Application current: 3.0 mA + 13.5  mA = 16.5  mA
     *  --> Power estimation   : 3.0 mA +  2.97 mA =  5.97 mA
     *
     * SMPS DC/DC converter enabled and connected:
     *  --> Quiescent   current: 3.0 mA
     *  --> Application current: 3.0 mA + 11.0  mA = 14.0  mA
     *  --> Power estimation   : 3.0 mA +  1.33 mA =  4.33 mA
     */
  }

  /* Vbat charger of MCU enabled with 1.5 kOhm */
  mainPowerSwitchDo(POWERSWITCH__BAT_HICUR, 1U);
}

void LcdBacklightInit(void)
{
  TIM_HandleTypeDef   TimHandle;
  TIM_OC_InitTypeDef  sConfig;

  /* PWM initial code */
  TimHandle.Instance = TIM3;

  TimHandle.Init.Prescaler         = uhPrescalerValue;
  TimHandle.Init.Period            = PERIOD_VALUE;
  TimHandle.Init.ClockDivision     = 0;
  TimHandle.Init.CounterMode       = TIM_COUNTERMODE_UP;
  TimHandle.Init.RepetitionCounter = 0;
  if (HAL_TIM_PWM_Init(&TimHandle) != HAL_OK)
  {
    /* Initialization Error */
    Error_Handler();
  }

  /* Common configuration for all channels */
  sConfig.OCMode       = TIM_OCMODE_PWM1;
  sConfig.OCPolarity   = TIM_OCPOLARITY_HIGH;
  sConfig.OCFastMode   = TIM_OCFAST_DISABLE;
  sConfig.OCNPolarity  = TIM_OCNPOLARITY_HIGH;
  sConfig.OCNIdleState = TIM_OCNIDLESTATE_RESET;

  sConfig.OCIdleState  = TIM_OCIDLESTATE_RESET;

  /* PWM: LCD-backlight Red */
  sConfig.Pulse = PULSE_RED_VALUE;
  if (HAL_TIM_PWM_ConfigChannel(&TimHandle, &sConfig, TIM_CHANNEL_1) != HAL_OK)
  {
    /* Configuration Error */
    Error_Handler();
  }

  /* PWM: LCD-backlight Green */
  sConfig.Pulse = PULSE_GREEN_VALUE;
  if (HAL_TIM_PWM_ConfigChannel(&TimHandle, &sConfig, TIM_CHANNEL_2) != HAL_OK)
  {
    /* Configuration Error */
    Error_Handler();
  }

  /* PWM: LCD-backlight Blue */
  sConfig.Pulse = PULSE_BLUE_VALUE;
  if (HAL_TIM_PWM_ConfigChannel(&TimHandle, &sConfig, TIM_CHANNEL_3) != HAL_OK)
  {
    /* Configuration Error */
    Error_Handler();
  }

  /* Start channel 1 - Red */
  if (HAL_TIM_PWM_Start(&TimHandle, TIM_CHANNEL_1) != HAL_OK)
  {
    /* PWM Generation Error */
    Error_Handler();
  }
  /* Start channel 2 - Green */
  if (HAL_TIM_PWM_Start(&TimHandle, TIM_CHANNEL_2) != HAL_OK)
  {
    /* PWM Generation Error */
    Error_Handler();
  }
  /* Start channel 3 - Blue */
  if (HAL_TIM_PWM_Start(&TimHandle, TIM_CHANNEL_3) != HAL_OK)
  {
    /* PWM generation Error */
    Error_Handler();
  }
}

void SystemResetbyARMcore(void)
{
  /* Set SW reset bit */
  SCB->AIRCR = 0x05FA0000UL | SCB_AIRCR_SYSRESETREQ_Msk;
}

/* Used by the run-time stats */
void configureTimerForRunTimeStats(void)
{
  getRunTimeCounterValue();

  /* Interrupt disabled block */
  {
    __disable_irq();

    s_timerStart_us = s_timerLast_us;

    __enable_irq();
  }
}

/* Used by the run-time stats */
unsigned long getRunTimeCounterValue(void)
{
  uint64_t l_timerStart_us = 0ULL;
  uint64_t l_timer_us = HAL_GetTick() & 0x003fffffUL;                                                   // avoid overflows

  /* Add microseconds */
  l_timer_us *= 1000ULL;
  l_timer_us += TIM2->CNT % 1000UL;                                                                     // TIM2 counts microseconds

  /* Interrupt disabled block */
  {
    __disable_irq();

    s_timerLast_us  = l_timer_us;
    l_timerStart_us = s_timerStart_us;

    __enable_irq();
  }

  uint64_t l_timerDiff64 = (l_timer_us >= l_timerStart_us) ?  (l_timer_us - l_timerStart_us) : l_timer_us;
  uint32_t l_timerDiff32 = (uint32_t) (l_timerDiff64 & 0xffffffffULL);
  return l_timerDiff32;
}

/* USER CODE END 0 */

/**
  * @brief  The application entry point.
  *
  * @retval None
  */
int main(void)
{
  /* USER CODE BEGIN 1 */

  // During RESET: 26.0mA @ 3.3V

  /* Check if ARM core is already in reset state */
  if (!(RCC->CSR & 0xff000000UL)) {
    __HAL_RCC_GPIOC_CLK_ENABLE();
    __HAL_RCC_GPIOF_CLK_ENABLE();
    __asm volatile( "NOP" );

    /* Disable SMPS */
    HAL_GPIO_WritePin(MCU_OUT_VDD12_EN_GPIO_Port, MCU_OUT_VDD12_EN_Pin, GPIO_PIN_RESET);
    //POWERSWITCH__1V2_DCDC, RESET;

    /* Turn off battery charger of Vbat */
    HAL_PWREx_DisableBatteryCharging();

    /* HICUR off */
    HAL_GPIO_WritePin(MCU_OUT_HICUR_EN_GPIO_Port, MCU_OUT_HICUR_EN_Pin, GPIO_PIN_RESET);

    /* 20MHz oscillator off */
    HAL_GPIO_WritePin(MCU_OUT_20MHZ_EN_GPIO_Port, MCU_OUT_20MHZ_EN_Pin, GPIO_PIN_RESET);

    /* VUSB off */
    HAL_GPIO_WritePin(MCU_OUT_VUSB_EN_GPIO_Port, MCU_OUT_VUSB_EN_Pin, GPIO_PIN_RESET);

    /* LCD reset */
    HAL_GPIO_WritePin(MCU_OUT_LCD_nRST_GPIO_Port, MCU_OUT_LCD_nRST_Pin, GPIO_PIN_RESET);

    /* ARM software reset to be done */
    SystemResetbyARMcore();
  }
  __HAL_RCC_CLEAR_RESET_FLAGS();

  // Here: 25.5mA @ 3.3V

  /* USER CODE END 1 */

  /* MCU Configuration----------------------------------------------------------*/

  /* Reset of all peripherals, Initializes the Flash interface and the Systick. */
  HAL_Init();

  /* USER CODE BEGIN Init */

  // Here: 26.0mA @ 3.3V

  #ifdef STD_INIT
  /* USER CODE END Init */

  /* Configure the system clock */
  SystemClock_Config();

  /* USER CODE BEGIN SysInit */
  #else
  /* Use MCU start-up clocking set-up */
  HFT_SystemClock_Config(g_main_SYSCLK_CONFIG);
  #endif

  // Here: 28.5mA @ 3.3V

  /* HSI16 trim */
  __HAL_RCC_HSI_CALIBRATIONVALUE_ADJUST(0x3f);                                                        // 0x40 centered

  /* MSI trim */
  //__HAL_RCC_MSI_CALIBRATIONVALUE_ADJUST(0x00);                                                      // Signed
  HAL_RCCEx_EnableMSIPLLMode();

  #ifdef STD_INIT
  // Here: 28.5mA @ 3.3V

  /* USER CODE END SysInit */

  /* Initialize all configured peripherals */
  MX_GPIO_Init();
  MX_DMA_Init();
  MX_ADC1_Init();
  MX_ADC3_Init();
  MX_CRC_Init();
  MX_DFSDM1_Init();
  MX_I2C1_Init();
  MX_I2C2_Init();
  MX_I2C3_Init();
  MX_I2C4_Init();
  MX_RNG_Init();
  MX_RTC_Init();
  MX_SAI1_Init();
  MX_SAI2_Init();
  MX_SPI1_Init();
  MX_SPI3_Init();
  MX_TIM16_Init();
  MX_TIM17_Init();
  MX_TIM3_Init();
  MX_TIM5_Init();
  MX_USART1_UART_Init();
  MX_USART2_UART_Init();
  MX_USART3_UART_Init();
  /* USER CODE BEGIN 2 */

  /* Copy of above for documentation */
  //MX_GPIO_Init();                                                                                   // Here: 27.5mA @ 3.3V    -0.5mA
  //MX_DMA_Init();                                                                                    // Here: 28.0mA @ 3.3V    +0.5mA
  //MX_ADC1_Init();                                                                                   // Here: 28.0mA @ 3.3V
  //MX_ADC3_Init();                                                                                   // Here: 28.0mA @ 3.3V
  //MX_CRC_Init();                                                                                    // Here: 28.0mA @ 3.3V
  //MX_DFSDM1_Init();                                                                                 // Here: 28.0mA @ 3.3V
  //MX_I2C1_Init();                                                                                   // Here: 28.5mA @ 3.3V    +0.5mA
  //MX_I2C2_Init();                                                                                   // Here: 29.0mA @ 3.3V    +0.5mA
  //MX_I2C3_Init();                                                                                   // Here: 29.0mA @ 3.3V
  //MX_I2C4_Init();                                                                                   // Here: 29.0mA @ 3.3V
  //MX_RNG_Init();                                                                                    // Here: 29.5mA @ 3.3V    +0.5mA
  //MX_RTC_Init();                                                                                    // Here: 29.5mA @ 3.3V
  //MX_SAI1_Init();                                                                                   // Here: 30.0mA @ 3.3V    +0.5mA
  //MX_SAI2_Init();                                                                                   // Here: 30.0mA @ 3.3V
  //MX_SPI1_Init();                                                                                   // Here: 31.0mA @ 3.3V    +1.0mA
  //MX_SPI3_Init();                                                                                   // Here: 31.0mA @ 3.3V
  //MX_TIM16_Init();                                                                                  // Here: 31.0mA @ 3.3V
  //MX_TIM17_Init();                                                                                  // Here: 31.0mA @ 3.3V
  //MX_TIM3_Init();                                                                                   // Here: 31.0mA @ 3.3V
  //MX_TIM5_Init();                                                                                   // Here: 31.0mA @ 3.3V
  //MX_USART1_UART_Init();                                                                            // Here: 31.5mA @ 3.3V    +0.5mA
  //MX_USART2_UART_Init();                                                                            // Here: 32.0mA @ 3.3V    +0.5mA
  //MX_USART3_UART_Init();                                                                            // Here: 32.0mA @ 3.3V

  //#define GPIO_AUDIO_DAC_SEL_OFF
  #ifdef GPIO_AUDIO_DAC_SEL_OFF
  gpio_AudioAdc_TurnOffSel();
  #endif

  #else

  /* Low energy set-up */
                                                                                                      // Here: 28.5mA @ 3.3V
  MX_GPIO_Init();                                                                                     // Here: 28.0mA @ 3.3V
  MX_DMA_Init();                                                                                      // Here: 28.0mA @ 3.3V
  MX_RTC_Init();                                                                                      // Here: 28.0mA @ 3.3V

  #define GPIO_ABCDEFGH_CLK_DISABLE
  #ifdef GPIO_ABCDEFGH_CLK_DISABLE
  /* Disable clocks again to save power */
  gpio_ABCDEFGH_ClkDisable();                                                                         // Here: 27.0mA @ 3.3V
  #endif

  #endif


  //#define I2C_BUS4_SCAN
  #ifdef I2C_BUS4_SCAN
  i2cBusAddrScan(&hi2c4, i2c4MutexHandle);
  #endif

  /* USER CODE END 2 */

  /* Call init function for freertos objects (in freertos.c) */
  MX_FREERTOS_Init();

  /* Start scheduler */
  osKernelStart();
  
  /* We should never get here as control is now taken by the scheduler */

  /* Infinite loop */
  /* USER CODE BEGIN WHILE */
  while (1)
  {

  /* USER CODE END WHILE */

  /* USER CODE BEGIN 3 */

  }
  /* USER CODE END 3 */

}

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
/* USER CODE BEGIN 4 */
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

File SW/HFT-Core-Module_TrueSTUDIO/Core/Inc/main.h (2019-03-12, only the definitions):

#define MCU_INOUT_PW03_Pin GPIO_PIN_2
#define MCU_INOUT_PW03_GPIO_Port GPIOE
#define I2S1B_SD_OUT_Pin GPIO_PIN_3
#define I2S1B_SD_OUT_GPIO_Port GPIOE
#define MCU_INOUT_PW02_Pin GPIO_PIN_4
#define MCU_INOUT_PW02_GPIO_Port GPIOE
#define MCU_INOUT_PW01_Pin GPIO_PIN_5
#define MCU_INOUT_PW01_GPIO_Port GPIOE
#define MCU_IN_WAKEUP_Pin GPIO_PIN_13
#define MCU_IN_WAKEUP_GPIO_Port GPIOC
#define MCU_OSC32_IN_Pin GPIO_PIN_14
#define MCU_OSC32_IN_GPIO_Port GPIOC
#define MCU_OSC32_OUT_Pin GPIO_PIN_15
#define MCU_OSC32_OUT_GPIO_Port GPIOC
#define MCU_I2C2_SDA_Pin GPIO_PIN_0
#define MCU_I2C2_SDA_GPIO_Port GPIOF
#define MCU_I2C2_SCL_Pin GPIO_PIN_1
#define MCU_I2C2_SCL_GPIO_Port GPIOF
#define MCU_INOUT_PW00_Pin GPIO_PIN_2
#define MCU_INOUT_PW00_GPIO_Port GPIOF
#define ADC3_IN6_20MHZ_PULL_Pin GPIO_PIN_3
#define ADC3_IN6_20MHZ_PULL_GPIO_Port GPIOF
#define MCU_IN_TIMCAP_N_Pin GPIO_PIN_6
#define MCU_IN_TIMCAP_N_GPIO_Port GPIOF
#define MCU_IN_TIMCAP_W_Pin GPIO_PIN_7
#define MCU_IN_TIMCAP_W_GPIO_Port GPIOF
#define MCU_IN_TIMCAP_S_Pin GPIO_PIN_8
#define MCU_IN_TIMCAP_S_GPIO_Port GPIOF
#define MCU_IN_TIMCAP_VSOL_Pin GPIO_PIN_9
#define MCU_IN_TIMCAP_VSOL_GPIO_Port GPIOF
#define MCU_EVENTOUT_PF10_Pin GPIO_PIN_10
#define MCU_EVENTOUT_PF10_GPIO_Port GPIOF
#define MCU_HSE_Pin GPIO_PIN_0
#define MCU_HSE_GPIO_Port GPIOH
#define MCU_OUT_VDD12_EN_Pin GPIO_PIN_0
#define MCU_OUT_VDD12_EN_GPIO_Port GPIOC
#define MCU_OUT_HICUR_EN_Pin GPIO_PIN_1
#define MCU_OUT_HICUR_EN_GPIO_Port GPIOC
#define MCU_OUT_VUSB_EN_Pin GPIO_PIN_2
#define MCU_OUT_VUSB_EN_GPIO_Port GPIOC
#define MCU_OUT_20MHZ_EN_Pin GPIO_PIN_3
#define MCU_OUT_20MHZ_EN_GPIO_Port GPIOC
#define UART2_CTS_IN_Pin GPIO_PIN_0
#define UART2_CTS_IN_GPIO_Port GPIOA
#define UART2_TX_OUT_Pin GPIO_PIN_2
#define UART2_TX_OUT_GPIO_Port GPIOA
#define MCU_VSOL_ADC1_Pin GPIO_PIN_3
#define MCU_VSOL_ADC1_GPIO_Port GPIOA
#define UART3_CTS_IN_Pin GPIO_PIN_6
#define UART3_CTS_IN_GPIO_Port GPIOA
#define MCU_OUT_PWM_LED_G_Pin GPIO_PIN_7
#define MCU_OUT_PWM_LED_G_GPIO_Port GPIOA
#define UART3_TX_OUT_Pin GPIO_PIN_4
#define UART3_TX_OUT_GPIO_Port GPIOC
#define UART3_RX_IN_Pin GPIO_PIN_5
#define UART3_RX_IN_GPIO_Port GPIOC
#define MCU_OUT_PWM_LED_B_Pin GPIO_PIN_0
#define MCU_OUT_PWM_LED_B_GPIO_Port GPIOB
#define UART3_RTS_OUT_Pin GPIO_PIN_1
#define UART3_RTS_OUT_GPIO_Port GPIOB
#define MCU_OUT_LCD_nRST_Pin GPIO_PIN_12
#define MCU_OUT_LCD_nRST_GPIO_Port GPIOF
#define MCU_I2C4_SCL_Pin GPIO_PIN_14
#define MCU_I2C4_SCL_GPIO_Port GPIOF
#define MCU_OUT_SX_HF_LF_CTRL_Pin GPIO_PIN_0
#define MCU_OUT_SX_HF_LF_CTRL_GPIO_Port GPIOG
#define MCU_IN_AX_GPIO1_Pin GPIO_PIN_1
#define MCU_IN_AX_GPIO1_GPIO_Port GPIOG
#define MCU_IN_AX_IRQ_Pin GPIO_PIN_7
#define MCU_IN_AX_IRQ_GPIO_Port GPIOE
#define I2S1B_SCK_OUT_Pin GPIO_PIN_8
#define I2S1B_SCK_OUT_GPIO_Port GPIOE
#define I2S1B_FS_OUT_Pin GPIO_PIN_9
#define I2S1B_FS_OUT_GPIO_Port GPIOE
#define I2S1B_MCLK_OUT_Pin GPIO_PIN_10
#define I2S1B_MCLK_OUT_GPIO_Port GPIOE
#define MCU_OUT_AX_SEL_Pin GPIO_PIN_11
#define MCU_OUT_AX_SEL_GPIO_Port GPIOE
#define MCU_OUT_SX_SEL_Pin GPIO_PIN_12
#define MCU_OUT_SX_SEL_GPIO_Port GPIOE
#define MCU_SPI1_SCK_Pin GPIO_PIN_13
#define MCU_SPI1_SCK_GPIO_Port GPIOE
#define MCU_SPI1_MISO_Pin GPIO_PIN_14
#define MCU_SPI1_MISO_GPIO_Port GPIOE
#define MCU_SPI1_MOSI_Pin GPIO_PIN_15
#define MCU_SPI1_MOSI_GPIO_Port GPIOE
#define MCU_IN_RE_I_Pin GPIO_PIN_10
#define MCU_IN_RE_I_GPIO_Port GPIOB
#define MCU_IN_RE_Q_Pin GPIO_PIN_12
#define MCU_IN_RE_Q_GPIO_Port GPIOB
#define I2S2A_SCK_IN_Pin GPIO_PIN_13
#define I2S2A_SCK_IN_GPIO_Port GPIOB
#define MCU_IN_RE_PB_Pin GPIO_PIN_14
#define MCU_IN_RE_PB_GPIO_Port GPIOB
#define MCU_OUT_SX_nRESET_Pin GPIO_PIN_8
#define MCU_OUT_SX_nRESET_GPIO_Port GPIOD
#define MCU_INOUT_PS00_Pin GPIO_PIN_9
#define MCU_INOUT_PS00_GPIO_Port GPIOD
#define MCU_INOUT_PS01_Pin GPIO_PIN_10
#define MCU_INOUT_PS01_GPIO_Port GPIOD
#define I2S2A_SD_IN_Pin GPIO_PIN_11
#define I2S2A_SD_IN_GPIO_Port GPIOD
#define I2S2A_FS_IN_Pin GPIO_PIN_12
#define I2S2A_FS_IN_GPIO_Port GPIOD
#define MCU_I2C4_SDA_Pin GPIO_PIN_13
#define MCU_I2C4_SDA_GPIO_Port GPIOD
#define MCU_INOUT_PS02_Pin GPIO_PIN_14
#define MCU_INOUT_PS02_GPIO_Port GPIOD
#define MCU_INOUT_PS03_Pin GPIO_PIN_15
#define MCU_INOUT_PS03_GPIO_Port GPIOD
#define MCU_IN_EXTI2_SX_DIO0_TXRXDONE_Pin GPIO_PIN_2
#define MCU_IN_EXTI2_SX_DIO0_TXRXDONE_GPIO_Port GPIOG
#define MCU_IN_EXTI2_SX_DIO0_TXRXDONE_EXTI_IRQn EXTI2_IRQn
#define MCU_IN_EXTI3_SX_DIO1_RXTO_Pin GPIO_PIN_3
#define MCU_IN_EXTI3_SX_DIO1_RXTO_GPIO_Port GPIOG
#define MCU_IN_EXTI3_SX_DIO1_RXTO_EXTI_IRQn EXTI3_IRQn
#define MCU_EVENTOUT_PG4_Pin GPIO_PIN_4
#define MCU_EVENTOUT_PG4_GPIO_Port GPIOG
#define MCU_I2C3_SCL_Pin GPIO_PIN_7
#define MCU_I2C3_SCL_GPIO_Port GPIOG
#define MCU_I2C3_SDA_Pin GPIO_PIN_8
#define MCU_I2C3_SDA_GPIO_Port GPIOG
#define MCU_OUT_PWM_LED_R_Pin GPIO_PIN_6
#define MCU_OUT_PWM_LED_R_GPIO_Port GPIOC
#define MCU_IN_AUDIO_DAC_nRDY_Pin GPIO_PIN_8
#define MCU_IN_AUDIO_DAC_nRDY_GPIO_Port GPIOC
#define MCU_OUT_AUDIO_DAC_SEL_Pin GPIO_PIN_9
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

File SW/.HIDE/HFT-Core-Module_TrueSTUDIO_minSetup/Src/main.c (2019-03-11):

/**
  ******************************************************************************
  * @file           : main.c
  * @brief          : Main program body
  ******************************************************************************
  * This notice applies to any and all portions of this file
  * that are not between comment pairs USER CODE BEGIN and
  * USER CODE END. Other portions of this file, whether 
  * inserted by the user or by software development tools
  * are owned by their respective copyright owners.
  *
  * Copyright (c) 2018 STMicroelectronics International N.V. 
  * All rights reserved.
  *
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
  ******************************************************************************
  */
/* Includes ------------------------------------------------------------------*/
#include "main.h"
#include "stm32l4xx_hal.h"
#include "cmsis_os.h"

RTC_HandleTypeDef hrtc;

osThreadId defaultTaskHandle;
osThreadId usbToHostTaskHandle;
osThreadId usbFromHostTaskHandle;
osThreadId hygroTaskHandle;
osThreadId baroTaskHandle;
osThreadId gyroTaskHandle;
osThreadId lcdTaskHandle;
osThreadId tcxo20MhzTaskHandle;
osThreadId ax5243TaskHandle;
osThreadId sx1276TaskHandle;
osThreadId controllerTaskHandle;
osThreadId si5338TaskHandle;
osThreadId audioAdcTaskHandle;
osThreadId audioDacTaskHandle;
osMessageQId usbToHostQueueHandle;
osMessageQId usbFromHostQueueHandle;
osMessageQId controllerInQueueHandle;
osMessageQId controllerOutQueueHandle;
osMessageQId loraMacQueueHandle;
osTimerId baroTimerHandle;
osTimerId hygroTimerHandle;
osTimerId defaultTimerHandle;
osTimerId gyroTimerHandle;
osTimerId controllerTimerHandle;
osTimerId tcxoTimerHandle;
osTimerId audioAdcTimerHandle;
osTimerId audioDacTimerHandle;
osSemaphoreId c2Ax5243_BSemHandle;
osSemaphoreId c2Sx1276_BSemHandle;
osSemaphoreId c2Si5338_BSemHandle;
osSemaphoreId c2Tcxo_BSemHandle;
osSemaphoreId c2Baro_BSemHandle;
osSemaphoreId c2Gyro_BSemHandle;
osSemaphoreId c2Hygro_BSemHandle;
osSemaphoreId c2Lcd_BSemHandle;
osSemaphoreId c2Default_BSemHandle;
osSemaphoreId i2c1_BSemHandle;
osSemaphoreId i2c2_BSemHandle;
osSemaphoreId i2c3_BSemHandle;
osSemaphoreId i2c4_BSemHandle;
osSemaphoreId spi1_BSemHandle;
osSemaphoreId spi3_BSemHandle;
osSemaphoreId cQin_BSemHandle;
osSemaphoreId cQout_BSemHandle;
osSemaphoreId c2AudioAdc_BSemHandle;
osSemaphoreId c2AudioDac_BSemHandle;

/* USER CODE BEGIN PV */

/* USER CODE END PV */

void SystemClock_Config(void);
static void MX_GPIO_Init(void);
static void MX_RTC_Init(void);
void StartDefaultTask(void const * argument);
void StartUsbToHostTask(void const * argument);
void StartUsbFromHostTask(void const * argument);
void StartHygroTask(void const * argument);
void StartBaroTask(void const * argument);
void StartGyroTask(void const * argument);
void StartLcdTask(void const * argument);
void StartTcxo20MhzTask(void const * argument);
void StartAx5243Task(void const * argument);
void StartSx1276Task(void const * argument);
void StartControllerTask(void const * argument);
void StartSi5338Task(void const * argument);
void StartAudioAdcTask(void const * argument);
void StartAudioDacTask(void const * argument);
void mainBaroTimerCallback(void const * argument);
void mainHygroTimerCallback(void const * argument);
void mainDefaultTimerCallback(void const * argument);
void mainGyroTimerCallback(void const * argument);
void mainControllerTimerCallback(void const * argument);
void mainTcxoTimerCallback(void const * argument);
void mainAudioAdcTimerCallback(void const * argument);
void mainAudioDacTimerCallback(void const * argument);

/* USER CODE BEGIN PFP */

/* USER CODE END PFP */

/**
  * @brief  The application entry point.
  *
  * @retval None
  */
int main(void)
{
  /* MCU Configuration----------------------------------------------------------*/

  /* Reset of all peripherals, Initializes the Flash interface and the Systick. */
  HAL_Init();

  /* Configure the system clock */
  SystemClock_Config();

  /* Initialize all configured peripherals */
  MX_GPIO_Init();
  MX_RTC_Init();
  /* USER CODE BEGIN RTOS_MUTEX */
  /* add mutexes, ... */
  /* USER CODE END RTOS_MUTEX */

  /* Create the semaphores(s) */
  /* definition and creation of c2Ax5243_BSem */
  osSemaphoreDef(c2Ax5243_BSem);
  c2Ax5243_BSemHandle = osSemaphoreCreate(osSemaphore(c2Ax5243_BSem), 1);

  /* definition and creation of c2Sx1276_BSem */
  osSemaphoreDef(c2Sx1276_BSem);
  c2Sx1276_BSemHandle = osSemaphoreCreate(osSemaphore(c2Sx1276_BSem), 1);

  /* definition and creation of c2Si5338_BSem */
  osSemaphoreDef(c2Si5338_BSem);
  c2Si5338_BSemHandle = osSemaphoreCreate(osSemaphore(c2Si5338_BSem), 1);

  /* definition and creation of c2Tcxo_BSem */
  osSemaphoreDef(c2Tcxo_BSem);
  c2Tcxo_BSemHandle = osSemaphoreCreate(osSemaphore(c2Tcxo_BSem), 1);

  /* definition and creation of c2Baro_BSem */
  osSemaphoreDef(c2Baro_BSem);
  c2Baro_BSemHandle = osSemaphoreCreate(osSemaphore(c2Baro_BSem), 1);

  /* definition and creation of c2Gyro_BSem */
  osSemaphoreDef(c2Gyro_BSem);
  c2Gyro_BSemHandle = osSemaphoreCreate(osSemaphore(c2Gyro_BSem), 1);

  /* definition and creation of c2Hygro_BSem */
  osSemaphoreDef(c2Hygro_BSem);
  c2Hygro_BSemHandle = osSemaphoreCreate(osSemaphore(c2Hygro_BSem), 1);

  /* definition and creation of c2Lcd_BSem */
  osSemaphoreDef(c2Lcd_BSem);
  c2Lcd_BSemHandle = osSemaphoreCreate(osSemaphore(c2Lcd_BSem), 1);

  /* definition and creation of c2Default_BSem */
  osSemaphoreDef(c2Default_BSem);
  c2Default_BSemHandle = osSemaphoreCreate(osSemaphore(c2Default_BSem), 1);

  /* definition and creation of i2c1_BSem */
  osSemaphoreDef(i2c1_BSem);
  i2c1_BSemHandle = osSemaphoreCreate(osSemaphore(i2c1_BSem), 1);

  /* definition and creation of i2c2_BSem */
  osSemaphoreDef(i2c2_BSem);
  i2c2_BSemHandle = osSemaphoreCreate(osSemaphore(i2c2_BSem), 1);

  /* definition and creation of i2c3_BSem */
  osSemaphoreDef(i2c3_BSem);
  i2c3_BSemHandle = osSemaphoreCreate(osSemaphore(i2c3_BSem), 1);

  /* definition and creation of i2c4_BSem */
  osSemaphoreDef(i2c4_BSem);
  i2c4_BSemHandle = osSemaphoreCreate(osSemaphore(i2c4_BSem), 1);

  /* definition and creation of spi1_BSem */
  osSemaphoreDef(spi1_BSem);
  spi1_BSemHandle = osSemaphoreCreate(osSemaphore(spi1_BSem), 1);

  /* definition and creation of spi3_BSem */
  osSemaphoreDef(spi3_BSem);
  spi3_BSemHandle = osSemaphoreCreate(osSemaphore(spi3_BSem), 1);

  /* definition and creation of cQin_BSem */
  osSemaphoreDef(cQin_BSem);
  cQin_BSemHandle = osSemaphoreCreate(osSemaphore(cQin_BSem), 1);

  /* definition and creation of cQout_BSem */
  osSemaphoreDef(cQout_BSem);
  cQout_BSemHandle = osSemaphoreCreate(osSemaphore(cQout_BSem), 1);

  /* definition and creation of c2AudioAdc_BSem */
  osSemaphoreDef(c2AudioAdc_BSem);
  c2AudioAdc_BSemHandle = osSemaphoreCreate(osSemaphore(c2AudioAdc_BSem), 1);

  /* definition and creation of c2AudioDac_BSem */
  osSemaphoreDef(c2AudioDac_BSem);
  c2AudioDac_BSemHandle = osSemaphoreCreate(osSemaphore(c2AudioDac_BSem), 1);
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

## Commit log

2018-02-26 HW_1V0 - CAD/Eagle - initial board with STM32L496Z created
    [HFT-Core-Module_1V0.brd, HFT-Core-Module_1V0.sch]
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2018-03-02 HW_1V0 - Harwin connectors fixed, core module re-sized
    [HFT-Core-Module_1V0.brd, HFT-Core-Module_1V0.sch]
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2018-04-03 HW_1V0 - multiple sheet pages added based on basket content of distributor
    [HFT-Core-Module_1V0.brd, HFT-Core-Module_1V0.sch]
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2018-04-08 HW_1V0 - df4iah_connector - USB socket fixed
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2018-04-09 HW_1V0 - df4iah_powersupply - missing devices added
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2018-04-16 HW_1V0 - minor fixes in schematics done
    [HFT-Core-Module_1V0.brd, HFT-Core-Module_1V0.sch]
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2018-04-19 SW - TrueSTUDIO - multiple fixes added
    [main.c]
2018-04-19 HW_1V0 - multiple fixes, missing lines added
    [HFT-Core-Module_1V0.brd, HFT-Core-Module_1V0.sch]
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2018-04-26 HW_1V0 - HFT_VHF-UHF-TRX_1V0 minor corrections done
    [HFT_VHF-UHF-TRX_1V0.brd]
2018-04-26 HW_1V0 - revert board to un-modified version - make lines at least with 0.1mm width
    [HFT_VHF-UHF-TRX_1V0.brd]
2018-04-30 SW - switched to MX version V4.25.0, removed distinct ports for PC and Mac
    [HFT-Core-Module_TrueSTUDIO_PinOuts_With-AFs.csv, HFT-Core-Module_TrueSTUDIO_PinOuts_Without-AFs.csv, PC_PinOuts_With-AFs.csv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]
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2018-05-28 HW_1V0 - SX1276 added to the board - before removing one AX5243
    [HFT-Core-Module_1V0.brd, HFT-Core-Module_1V0.sch]
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2018-06-18 SW - STM32CubeMX - signals/wires renamed to match schematics, exported to source
    [HFT-Core-Module_TrueSTUDIO_PinOuts_With-AFs.csv, HFT-Core-Module_TrueSTUDIO_PinOuts_Without-AFs.csv]
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2018-07-11 HW_1V0 - ERC findings fixed
    [HFT-Core-Module_1V0.brd, HFT-Core-Module_1V0.sch]
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2018-07-21 SW - STM32CubeMX - USB renamed to match schematics, exported to source
    [HFT-Core-Module_TrueSTUDIO_PinOuts_With-AFs.csv, HFT-Core-Module_TrueSTUDIO_PinOuts_Without-AFs.csv]
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2018-07-22 HW_1V0 - ERC: some missing signals at the MCU found
    [HFT-Core-Module_1V0.brd, HFT-Core-Module_1V0.sch]
2018-07-23 HW_1V0 - TIM5 capture channels 1-3 added to the North, West and the South
    [HFT-Core-Module_1V0.brd, HFT-Core-Module_1V0.sch]
2018-07-23 SW - STM32CubeMX - missing TIM5 captures and ADC added
    [HFT-Core-Module_TrueSTUDIO_PinOuts_With-AFs.csv, HFT-Core-Module_TrueSTUDIO_PinOuts_Without-AFs.csv]
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2018-07-28 HW_1V0 - df4iah_stm32l4.lbr - wrong LQFP144 package of STM32L496 fixed
2018-07-28 HW_1V0 - routing for LQFP144 package fixed and minor other fixes
    [HFT-Core-Module_1V0.brd, HFT-Core-Module_1V0.sch]
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2018-07-29 HW_1V0 - outdated DC/DC buck converter replaced
    [HFT-Core-Module_1V0.brd, HFT-Core-Module_1V0.sch]
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2018-08-13 HW_1V1 - CAD/Eagle - LCD, Audio jacks and Rotary encoder corrected
    [HFT-Core-Module_1V1.brd, HFT-Core-Module_1V1.sch]
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2018-08-14 HW_1V1 - CAD/Eagle - USB power switch bridged by 50R to enable power-up
    [HFT-Core-Module_1V1.brd, HFT-Core-Module_1V1.sch]
2018-08-14 HW_1V1 - CAD/Eagle - notice added about current consumption of DcDc converters
    [HFT-Core-Module_1V1.sch]
2018-08-15 HW_1V1 - CAD/Eagle - U0111 text put outside of of placed MCU
    [HFT-Core-Module_1V1.brd]
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2018-08-16 HW_1V1 - CAD/Eagle - Micro-USB receptacle corrected
    [HFT-Core-Module_1V1.brd, HFT-Core-Module_1V1.sch]
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2018-08-18 HW_1V1 - CAD/Eagle - programmer socket changed, Reset button is of type NO and not NC
    [HFT-Core-Module_1V1.brd, HFT-Core-Module_1V1.sch]
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2018-08-26 HW_1V0 - SWD header, XO 32.768kHz caps, RESET resistor removed
    [HFT-Core-Module_1V0.brd, HFT-Core-Module_1V0.sch]
2018-08-26 HW_1V1 - SWD header, XO 32.768kHz caps, RESET resistor removed, SWD resistors added
    [HFT-Core-Module_1V1.brd, HFT-Core-Module_1V1.sch]
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2018-08-31 HW_1V1 - I2C addresses changed, LCD will be replaced by EA DOGS104N-A
    [HFT-Core-Module_1V1.brd, HFT-Core-Module_1V1.sch]
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2018-09-05 HW_1V1 - oscillators PCB drawings fixed
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2018-09-05 SW - Throw out TICKLESS_IDLE due to timing slip
    [HFT-Core-Module_TrueSTUDIO.ioc, main.c]
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2018-09-05 DOCS - V1.1 LoRa SX1276 will be replaced by SX1262
    [Pick Place for SX1276RF1IAS_e266v02a.xlsx, Pick Place for SX1276_e315v01a.xlsx, SX1276MB1MAS_e315v01a_BOM.xls]
2018-09-05 DOCS - V1.1 PMIC DC/DC replacements
    [HFTCoreModule_V1.1__replacements_DcDc-converters.xlsx]
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2018-09-06 SW - power analysis - MCU stays 3 seconds at low power consumption after reset for PMICs to stabilize
    [main.c]
2018-09-07 SW - power analysis - bug with DefaultTask fixed, 3 seconds wait removed again
    [HFT-Core-Module_TrueSTUDIO_PinOuts_With-AFs.csv, HFT-Core-Module_TrueSTUDIO_PinOuts_Without-AFs.csv]
2018-09-08 SW - solved: power analysis - clock domain changed, pull-up/-down even on output signals needed, I/O speed class aware
    [main.c, main.h]
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2018-09-08 SW - power consumption simulation fixed
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2018-09-10 HW_1V0 - Solar DC/DC needs 100uF at the input, MCU runs 24MHz and emits 12MHz for the Si5338
    [HFT-Core-Module_1V0.brd, HFT-Core-Module_1V0.sch]
2018-09-10 HW_1V1 - multiple new modules for V1.1 to be used instead of problematic ones
    [HFT-Core-Module_1V1.brd, HFT-Core-Module_1V1.sch]
2018-09-11 SW - task names shortened
    [HFT-Core-Module_TrueSTUDIO.ioc, main.c, task_AX5243.h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]
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2018-09-15 SW - task_AX5243 - POCSAG having problem with FIFO
    [main.h, task_AX5243.h]
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2018-09-16 HW_1V1 - some values cleaned-up and latest V1.0 issue reminders added
    [HFT-Core-Module_1V1.brd, HFT-Core-Module_1V1.sch]
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2018-09-24 DOCS - 20_LED - missing order number to RGB LED added
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2018-09-25 HW_1V0 - ADC resistor values changed, ADC OSC2 should be connected to GND (reminder added)
    [HFT-Core-Module_1V0.brd, HFT-Core-Module_1V0.sch]
2018-09-25 HW_1V1 - AUDIO ADC and DAC - replaced by I2S streaming devices
    [HFT-Core-Module_1V1.brd, HFT-Core-Module_1V1.sch]
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2018-09-26 HW_ARDUINO - missing headers for Arduino Uno compatible sockets added
2018-09-26 HW_1V1 - measurements - wrong sizes fixed
    [HFT-Core-Module_1V1.brd]
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2018-09-27 HW_ARDUINO - last positioning and small fixes
    [HFT-ArduinoShield-Module_1V0.brd]
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2018-09-27 HW_ARDUINO - CAM - correction: some labels moved
    [HFT-ArduinoShield-Module_1V0.brd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]
2018-09-30 SW - Controller - task_TCXO_20MHz module DAC voltage fixed
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2018-10-03 SW - task_LCD - missing characters work-around introduced (due to HW constructions?)
    [main.h, task_Controller.c]
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2018-10-03 HW_1V1 - CAD/Eagle - Replacements for 9-axis controller and 1.8V supply
    [HFT-Core-Module_1V1.brd, HFT-Core-Module_1V1.sch]
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2018-10-07 SW - reworking directory structure, new export settings used
    [HFT-Core-Module_TrueSTUDIO_PinOuts_With-AFs.csv, HFT-Core-Module_TrueSTUDIO_PinOuts_Without-AFs.csv]
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2018-10-14 SW - clocking - HSE with 20MHz of VCTCXO fixed
    [HFT-Core-Module_TrueSTUDIO.ioc, main.c, main.h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]
2018-10-14 SW - clocking - module task_TCXO_20MHz fixed
    [HFT-Core-Module_TrueSTUDIO.ioc, i2c.c, main.c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]
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2018-10-15 SW - timer - hunting for PCLK bug
    [adc.c, i2c.c, main.c]
2018-10-16 HW_1V1 - CAD/Eagle - Note added for QUADSPI to include to new design
    [HFT-Core-Module_1V1.sch]
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2018-10-20 DOCS - 23_PMIC - missing device added
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2018-10-21 HW_1V1 - CAD/Eagle/lbr - wrong package for WM8523 replaced
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2018-10-22 HW_1V1 - CAD/Eagle - PMIC 3.3V --> 1.20V - 2x dig. pot. for Vcore voltage reduction added
    [HFT-Core-Module_1V1.brd, HFT-Core-Module_1V1.sch]
2018-10-22 HW_1V1 - CAD/Eagle - PMIC 3.3V --> 1.20V - I2C address added to the list
    [HFT-Core-Module_1V1.sch]
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2018-10-22 HW_1V1 - CAD/Eagle - BNO085 - missing I2C termination added
    [HFT-Core-Module_1V1.brd, HFT-Core-Module_1V1.sch]
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2018-10-23 HW_1V1 - CAD/Eagle/lbr - df4iah_lcd.lbr - wrong backlight pins fixed
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2018-10-24 HW_1V1 - CAD/Eagle - idea for SIM868 level shifter and LiPo charger added
    [HFT-Core-Module_1V1.sch]
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2018-10-24 HW_1V1 - CAD/Eagle - I2C address map update, decission for LiPo charger made
    [HFT-Core-Module_1V1.sch]
2018-10-25 HW_1V1 - CAD/Eagle - I2C port expander instead of serial shift register
    [HFT-Core-Module_1V1.sch]
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2018-10-27 HW_1V1 - CAD/Eagle - LPV811 OpAmps added, resistor arrays added, I2C port expanders changed
    [HFT-Core-Module_1V1.brd, HFT-Core-Module_1V1.sch]
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2018-10-29 HW_1V1 - CAD/Eagle - inductivities fixed
    [HFT-Core-Module_1V1.brd, HFT-Core-Module_1V1.sch]
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2018-10-30 HW_1V1 - CAD/Eagle/lbr - df4iah_powersupply.lbr - pin direction of RESET reversed
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2018-11-01 HW_1V1 - CAD/Eagle - HARWIN connectors fixed
    [HFT-ArduinoShield-Module_1V1.brd, HFT-ArduinoShield-Module_1V1.sch, HFT-Core-Module_1V1.brd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]
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2018-11-02 HW_1V1 - CAD/Eagle/lbr - font size fixed for df4iah_sc-switches.lbr
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2018-11-03 HW_1V1 - CAD/Eagle - many signal names changed, SIM868 continued to implement
    [HFT-Core-Module_1V1.brd, HFT-Core-Module_1V1.sch]
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2018-11-04 HW_1V1 - CAD/Eagle - all pages placed, E-Ink Display still to improve
    [HFT-Core-Module_1V1.brd, HFT-Core-Module_1V1.sch]
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2018-11-05 HW_1V1 - CAD/Eagle/lbr - df4iah_dataconvertion.lbr - symbol port directions fixed for level shifter
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2018-11-07 HW_1V1 - CAD/Eagle/lbr - df4iah_rf.lbr - packages fixed
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2018-11-07 HW_1V1 - CAD/Eagle - many resistors and capacitors changed to 0402 package
    [HFT-Core-Module_1V1.brd, HFT-Core-Module_1V1.sch]
2018-11-08 HW_1V1 - CAD/Eagle/lbr - packages fixed
2018-11-08 HW_1V1 - CAD/Eagle/lbr - millings and stop masks fixed
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2018-11-08 HW_1V1 - CAD/Eagle - current libraries reloaded, border lines made smooth (2)
    [HFT-Core-Module_1V1.brd]
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2018-11-09 HW_1V1 - CAD/Eagle - VDDUSB fixed at MCU schematic page
    [HFT-Core-Module_1V1.brd, HFT-Core-Module_1V1.sch]
2018-11-10 HW_1V1 - CAD/Eagle/lbr - df4iah_connector.lbr - USB socket fixed
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2018-11-11 HW_1V1 - CAD/Eagle - pulling out all devices from the 3mm border area
    [HFT-Core-Module_1V1.brd]
2018-11-11 HW_1V1 - CAD/Eagle - routing: starting at 12V buck down conv. and solar regulator
    [HFT-Core-Module_1V1.brd, HFT-Core-Module_1V1.sch]
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2018-11-12 HW_1V1 - CAD/Eagle - USB switch enhanced for SOFT and HARD connection path
    [HFT-Core-Module_1V1.brd, HFT-Core-Module_1V1.sch]
2018-11-13 HW_1V1 - CAD/Eagle/lbr - LCD backlight pads fixed
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2018-11-14 HW_1V1 - CAD/Eagle/lbr - df4iah_crystal.lbr - dimension for device fixed
2018-11-14 HW_1V1 - CAD/Eagle - More routing done, crystal device fixed, USB bus finished
    [HFT-Core-Module_1V1.brd, HFT-Core-Module_1V1.sch]
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2018-11-15 HW_1V1 - CAD/Eagle - Text size of new device fixed
    [HFT-Core-Module_1V1.brd]
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2018-11-19 HW_1V1 - CAD/Eagle - All ground pins are connected, more routing done
    [HFT-Core-Module_1V1.brd]
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2018-11-30 HW_1V1 - CAD/Eagle - Short wires routing done
    [HFT-Core-Module_1V1.brd]
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2018-12-02 HW_1V1 - CAD/Eagle - DRC findings solved
    [HFT-Core-Module_1V1.brd, HFT-Core-Module_1V1.sch]
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2018-12-17 HW_1V1 - CAD/Eagle - more routed, still abt. 10 airwires to do
    [HFT-Core-Module_1V1.brd]
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2019-01-01 HW_1V1 - CAD/Eagle - update of schematic and board due to changed libraries
    [HFT-Core-Module_1V1.brd, HFT-Core-Module_1V1.sch]
2019-01-01 HW_1V1 - CAD/Eagle - STM32L496 symbol fixed
    [HFT-Core-Module_1V1.sch]
2019-01-02 HW_1V1 - text size fixed for 0603 and 0402 devices
    [HFT-Core-Module_1V1.brd, HFT-Core-Module_1V1.sch]
2019-01-11 HW_1V1 - CAD/Eagle - new board design settings due to change of PCB house
    [HFT-Core-Module_1V1.brd, HFT-Core-Module_1V1.sch]
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2019-01-14 HW_1V1 - CAD/Eagle - SIM level shifters replaced by R-networks
    [HFT-Core-Module_1V1.brd, HFT-Core-Module_1V1.sch]
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2019-01-16 HW_1V1 - CAD/Eagle - some more enable signals controlled by the MCU, ERC okay.
    [HFT-Core-Module_1V1.brd, HFT-Core-Module_1V1.sch]
2019-01-17 HW_1V1 - CAD/Eagle/lbr - STM32L4 library with bad package LQFP64 fixed, LQFP144 minor fix
2019-01-17 HW_1V1 - CAD/Eagle - update of schematic and board due to library changes of STM32L4
    [HFT-Core-Module_1V1.brd, HFT-Core-Module_1V1.sch]
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2019-02-01 HW_1V1 - df4iah_connector.lbr - SWD connector fixed
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2019-02-11 HW_1V1 - CAD/Eagle - 32kHz crystal oscillator modified
    [HFT-Core-Module_1V1.brd, HFT-Core-Module_1V1.sch]
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2019-02-12 HW_1V1 - CAD/Eagle/lbr - df4iah_powersupply package SOT95P280X145-5N text size fixed
    [HFT-Core-Module_1V1.brd, HFT-Core-Module_1V1.sch]
2019-02-12 HW_1V1 - CAD/Eagle/lbr - df4iah_opamp package SOT-23-5 and SOT-23-6 text size fixed
    [HFT-Core-Module_1V1.brd, HFT-Core-Module_1V1.sch]
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2019-02-13 HW_1V1 - CAD/Eagle/lbr - df4iah_powersupply VQFN-24.pac, HTSSOP16.pac drill size expanded to 12mil (0.3mm)
    [HFT-Core-Module_1V1.brd, HFT-Core-Module_1V1.sch]
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2019-03-09 HW_1V1 - CAD/Eagle/lbr - df4iah_rf.lbr ESP-12F pin directions fixed
2019-03-11 HW_1V1 - CAD/Eagle - PMIC BQ no automatic rail connection but by MCU control
    [HFT-Core-Module_1V1.brd, HFT-Core-Module_1V1.sch]
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2019-03-12 HW_1V1 - CAD/Eagle - all micro airwires fixed
    [HFT-Core-Module_1V1.brd]
2019-03-12 HW_1V1 - CAD/Eagle - last airwire solved
    [HFT-Core-Module_1V1.brd]
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2019-03-12 HW_1V1 - CAD/Eagle/lbr - df4iah_connector - audio jack missing layers 3 and 14 added
    [HFT-Core-Module_1V1.brd, HFT-Core-Module_1V1.sch]
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2019-03-14 DOCS - Request by PCB board house and fixes
    [HFT-Core-Module_1V1_2.brd]
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

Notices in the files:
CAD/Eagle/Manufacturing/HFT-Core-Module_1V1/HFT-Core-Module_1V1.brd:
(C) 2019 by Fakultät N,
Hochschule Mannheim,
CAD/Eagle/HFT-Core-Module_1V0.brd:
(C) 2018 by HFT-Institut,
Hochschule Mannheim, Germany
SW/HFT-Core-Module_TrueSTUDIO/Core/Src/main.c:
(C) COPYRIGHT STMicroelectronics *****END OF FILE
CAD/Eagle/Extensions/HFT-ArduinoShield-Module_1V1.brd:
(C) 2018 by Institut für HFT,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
